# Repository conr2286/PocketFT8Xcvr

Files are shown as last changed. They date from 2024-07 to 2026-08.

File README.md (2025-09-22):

# Pocket FT8 Revisited
A derivative of Charles Hill's Palm-Sized Pocket FT8 Transceiver

# Attribution
* Copyright (C) 2025, James R Conrad (KQ7B), conr2286 *at* gmail *dot* com
* Copyright (C) 2021, Charles Hill (W5BAA), https://github.com/Rotron/Pocket-FT8 
* Si4735 Library developed by Ricardo Caritti: https://github.com/pu2clr/SI4735
* FT8 Decoding Library by Karlis Goba (YL3JG): https://github.com/kgoba/ft8_lib
* SN74ACT244 PA by Barb (WB2CBA), https://github.com/WB2CBA/DX-FT8-FT8-MULTIBAND-TABLET-TRANSCEIVER 
* Adafruit, PJRC and many Arduino libraries copyrighted by their respective authors

# Permissive MIT License (applies to most project files)
* Copyright (c) 2018 Kārlis Goba
* Copyright (C) 2019 Ricardo Lima Caratti
* Copyright (C) 2021, Charles Hill (W5BAA)
* Copyright (C) 2024, 2025 Jim Conrad (KQ7B)

Permission is hereby granted, free of charge, to any person obtaining a copy of this software and associated documentation files (the "Software"), to deal in the Software without restriction, including without limitation the rights to use, copy, modify, merge, publish, distribute, sublicense, and/or sell copies of the Software, and to permit persons to whom the Software is furnished to do so, subject to the following conditions:

The above copyright notice and this permission notice shall be included in all copies or substantial portions of the Software.

THE SOFTWARE IS PROVIDED "AS IS", WITHOUT WARRANTY OF ANY KIND, EXPRESS OR IMPLIED, INCLUDING BUT NOT LIMITED TO THE WARRANTIES OF MERCHANTABILITY, FITNESS FOR A PARTICULAR PURPOSE AND NONINFRINGEMENT. IN NO EVENT SHALL THE AUTHORS OR COPYRIGHT HOLDERS BE LIABLE FOR ANY CLAIM, DAMAGES OR OTHER LIABILITY, WHETHER IN AN ACTION OF CONTRACT, TORT OR OTHERWISE, ARISING FROM, OUT OF OR IN CONNECTION WITH THE SOFTWARE OR THE USE OR OTHER DEALINGS IN THE SOFTWARE.

# CopyLeft GPL License (applies to the SI5351 library)
* Copyright (C) 2015-2019 Jason Milldrum and Dana H. Myers

# Features
* Single band, FT8 Tranceiver
* Designed for 160-15 meters, tested on 40m
* Small Size, 4.0 X 2.8", 4-layer board
* Powered by a single 5V USB source (e.g. portable USB power block) delivering ~375 mA
* Si4735 SSB Receiver
* TCXO stabilized Si5351 Clock
* SN74ACT244 PA delivering ~250 mW on 40M (Tnx, Barb;)
* ADIF Contact Logging to SD card
* Adafruit 320 X 480 Resistive Color Touch Screen
* Optional Adafruit Ultimate GPS-derived location and UTC date/time
* RoboOp sequences FT8 QSOs somewhat akin to wsjtx

# DSP Audio Architecture
Decoding FT8 requires significant data storage and processing speed.  To optimize program storage and processing speed so the Teensy is not over taxed, the Teensy Audio Library has been modified to allow Analog to Digital conversion to be run at the rate of 6400 samples per second. This allows audio data processing to be done at 3200 Hz. The 3200 Hz audio processing with a 2048 FTT to process the received audio for FT8 decoding yields a bin spacing of 3.125 Hz.  For Teensy 4.1, the revised sample rate requires replacement of the core AudioStream.h file with the AudioStream6400.h file in the PocketFT8FW sketch folder.

The algorithms developed by Karlis Goba use the 3.125 Hz spaced FFT bins to be screened in both frequency and time so that errors in symbol frequency and time reception can be overcome to provide really great FT8 decoding. The end spacing of the FT8 algorithms is 6.25 Hz.

# Motivation and Related Projects
In the mid-60s, the ARRL Handbook published a receiver design known as the Junior Miser's Dream offering so much with so little.  Today, Charley Hill's concept for a self-contained FT8 transceiver, ideal for portable operation, again achieves so much with so little.  The entire transceiver fits in a small enclosure, powered by a USB power brick.  Pocket FT8 Revisited is a derivative of Charley's original concept.

Unlike the uSDX and related multi-mode designs, Pocket FT8 focuses entirely on FT8.  If you need CW, SSB, etc then Pocket FT8 is not for you.

Charley and Barb have progressed with another Pocket FT8 derivative, DX FT8, at https://github.com/WB2CBA/DX-FT8-FT8-MULTIBAND-TABLET-TRANSCEIVER, most notably replacing the SI4735 with a Tayloe receiver.

# Manifest
* BenchTests:  Arduino sketches for incremental tests of the hardware
* Bibliography:  "..shoulders of giants"
* Doc:  Minimalist user manual
* Enclosure:  STLs for 3D printing a plastic case for an older version (needs update)
* Examples:  Sample JSON configuration and ADIF log files
* Extras:  Modified Teensy AudioStream6400.h header (you *need* this)
* Investigations:  Code and simulations exploring technologies for this project
* Mfg:  BOM files for assembly.  V2.00 has been built; the current BOM awaits tariff issues.
* PocketFT8XcvrFW:  The transceiver firmware sources
* PocketFT8XcvrHW:  KiCad files for the PCB
* RFFilters:  Investigations into various filter designs
* Extras:  Contains Teensy AudioStream.h modified for 6400 samples/second.  You *need* this.
* Schematics:  PDFs of hardware schematics.  V2.00 matches V2.00 BOM.
* SpectralPurity:  Results of investigations into transmitter output using V2.00 hardware.

# Versions
* V1.00 PCB gerbers and pos files submitted to PCBWay.
* V1.10 Transmitter works.  Receiver occasionally decodes FT8 messages.  See Issue #23 on github.
* V2.00 Revised PCB moves the SI5351 and MCP342x to Wire1 to avoid I2C noise (Issue #23) hampering the SI4735
* V2.10 Implements GPS, ADIF logging and the RoboOp QSO sequencer.  Uses V2.00 hardware with patch wires for GPS connector.  The GPS is optional but *strongly* recommended.
* V3.00 continues with the same firmware, but the hardware eliminates the requirement for the PPS patch wire and adds an expansion connector to break-out a few GPIO signals.  The V3.00 board fabrication awaits a satisfactory tariff solution.

# Implementationi Notes
* The receiver is based upon the SI4735 chip offering a compact, low-power approach for most HF bands  Following up on a tip from the SI4735's application notes, the chip was found to be extremely sensitive to noise from other I2C traffic on the same bus as the SI4735.  The V2.00 boards address this issue by moving the touchscreen (MCP342X) and SI5351 traffic from the Wire to the Wire1 I2C bus, isolating the SI4735 on Wire.  Likewise, the V2.00 boards pay more attention to signal routing adjacent to noise-sensitive circuitry.
* Many clock designs use a TCXO driving one of the SI5351's XTAL pins and often in conflict with the SI5351 application notes recommendations.  Many designers have commented (not of one voice;) on this approach.  Following up on a now-misplaced tip re. phase noise, this design employs a low jitter TCXO driving the SI5351's CLKIN pin.  Following up on yet another misplaced tip regarding the SI5351's phase noise when driving heavy loads, the V2.00 boards buffer the XCLK signal from the SI5351.  All this may be overkill but it was easy to implement.
* The V2.00 boards and the original Pocket FT8 project use an external MCP342x ADC to poll the touchscreen.  With a non-blocking ADC library, the Teensy 4.1 could likely use the second internal ADC but this idea has not yet been tested (it can be achieved using a patch to the V2.00 boards).  Alternative approaches include using a touchscreen controller.  These are considered for a future V4.00.
* The V1.10 LP filter lacked rejection of received signals below the operating frequency.  Spectral investigations into the found surprisingly strong signals in the 500..7000 kHz range having the potential to limit the receiver's performance.  The V2.00 board filter plugins offer a chance to explore a bandpass design to protect the receiver's front end.  Suitable bandpass filters have been modeled but not yet been tested.
* The V2.00 boards support the Adafruit Ultimate GPS Breakout board.  The firmware supports using the PPS digital interrupt signal to determine when the GPS acquires a fix; however, the V2.00 PCB requires a patch wire to connect the PPS pin to Teensy Digital Pin 2, and the GPS connector has the PPS pin in an awkward location for a ribbon cable.  This will hopefull be fixed in the V3.00 hardware when tariffs permit.  The patch is easy to solder and I strongly recommend it.

# Boards and Parts Availability
Pocket FT8 Revisited is not a kit.  If you seek a kit-like experience, check-out QRP Labs, the uSDX follow-ons, or the DX FT8 kit because Pocket FT8 construction requires some engineering skills and tools including KiCAD, the Arduino IDE, and Visual Studio Code with the PlatformIO extensions.  This project is more about homebrewing than operating.  That said, sometimes I have spare boards for one version or another.

# Building the Firmware
1. Install Arduino 2.X IDE (the BenchTests still require the Arduino IDE, sorry)
2. Using Arduino 2.X, install support for the Teensy 4.1 board
3. Install Visual Studio Code and PlatformIO
4. Using PlatformIO, install support for the Teensy 4.1 platform
5. Using PlatformIO, install support for the required libraries (documented in the PocketFT8XcvrFW folder)
6. Copy Extras/AudioStream6400.h into
 .../Library/Arduino15/packages/teensy/hardware/avr/1.59.0/cores/teens4 asArduinoStream.h --- This file redefines AUDIO_SAMPLE_RATE_EXACT enabling Teensy 4.1 to operate the audio stream at 6400 samples/second (required).  You absolutely *must* do this; PocketFT8XcvrFW.cpp will not execute if you forget.
7. Build the firmware with PlatformIO.  The project src files build without warnings; library files... not so much.

# Hardware Notes
Pocket FT8 Revisited was designed with KiCAD, and the V2.00 PCBs were fabbed and the SMD assembled by PCBWay.  There are two boards, the main board (PocketFT8XcvrHW) and a daughter board for the filter (RFFilters).  I used the 5Pole40MLPFilter in the SpectralPurity test.  The V3.00 boards are designed and checked but await a satisfactory tariff solution for fabrication and assembly.

# Building the Hardware
1. Attach the Teensy 4.1 MPU to the board using *low profile* headers.
2. Attach the Adafruit resistive 320x480 touchscreen with high profile headers (so the display clears the MPU)
3. Construct a suitable filter (e.g. 5-pole Chebyshev) for your chosen band of operation and solder it into the FL1 spot.  The RFFilters folder contains a KiCAD design for the filter daughter board.
4. Hand solder SMD CR2032 battery holder to reverse side of PCB and install battery (before powering-up the Teensy).  T
5. Hand solder THT red XMIT LED
6. Wind THT T1 (10T bifilar #26 on FT37-43 core) and install
7. Install right angle header for GPS.  Hand solder a PPS patch wire from the GPS connector to the MCU as described above.
8. Hand solder the SMD SMA antenna socket to the board
9. Smoke test with wall wart USB supply (not your expensive computer;)
10. Build and execute each of the BenchTests (with Arduino IDE 2.00) in numerical order to individually check-out the circuit subsystems.

# Putting Pocket FT8 Revisited On-the-Air
1. Create an SD file, CONFIG.JSON, to configure the Pocket FT8 for your station (see the sample file in Examples).  The required parameters are, callsign and frequency.  If you don't have a GPS, you'll also need location.  Install the SD card in Teensy (*not* in the Adafruit display which also has an SD slot).
2. If you are using a GPS, connect it now.
3. Connect an antenna 
4. Connect your host computer and load your firmware

# Usage
## CONFIG.JSON
During setup(), the rig reads the config.json file, if available, from the Teensy SD card.  The SD card and configuration file are required to enable the transmitter.  See the example config file in the Examples folder.  The important configuration parameters include:
* callsign      Station callsign.  *Required* to enable the transmitter.
* frequency     Operating frequency in kHz (default is 7074).
* locator       Four letter Maidenhead grid square (Required if no GPS).
* enableAVC     Enable/disable SI4735 AVC (default is enabled).
* qsoTimeout    Seconds the QSO Sequencer will retransmit a msg without receiving a usable response from remote station (default is 180)

## GPS
If available, the rig will use the current UTC date, time and location (Maidenhead grid square) from an attached GPS.  The V2.00 hardware requires a patch wire to connect the GPS PPS connector pin to Teensy digital pin 2.  The firmware monitors PPS interrupts and begins using the UTC time and location only when/if the GPS acquires a satellite fix.  
Without a GPS fix, the firmware uses the date/time from the battery-backed Teensy Real Time Clock (RTC) and displays that date/time in yellow.  After a fix is obtained, the date/time displays in green.  The GPS is not required but *greatly* facilitates UTC logging and accurate synchronization with FT8 timeslots.

## Logging
Pocket FT8 logs successful contacts to an ADIF file on the Teensy SD disk.  The date/time are recorded in UTC if the rig has acquired a GPS fix.  If the rig has never had a GPS fix, the date/time come from the boot loader and the computer that installed the firmware --- that may work for FT8 but the UTC date/time will be incorrect in the ADIF log.  You really do want the GPS.  The logging software considers a contact successful when the rig obtains the remote station's callsign and signal report (yes, that's a little more severe than required by ARRL's LoTW).  Without a GPS, the grid locator can be obtained from the configuration file.

## Robo-Op
Pocket FT8 firmware includes a "RoboOp" "sequencer somewhat akin (or ajar...;) to those used in wsjtx and DX FT8.  The sequencer conducts a standard FT8 QSO initiated with your station's CQ, or with your reply to a station calling CQ.  The sequencer automagically coordinates its transmissions with those of the remote station to avoid "doubling" (transmitting in the same timeslot as the remote transmission).  In most cases, the sequencer prepares a reply during the FT8 "dwell" time (between timeslots) and can transmit in the very next timeslot.  If not... well... it will wait for an appriopriate even/odd timeslot.
The sequencer is implemented as a giant state machine that attempts to make the best of difficult conditions/responses to complete a troubled QSO.  The sequencer has a configurable QSO Timeout feature to abort a run-on QSO (including CQ) arising from QRM, QRN, or a QRT/QLF remote station.  As with most large state machines... the code is difficult to follow, but is mitigated with an abundance of comments that attempt to explain what's happening in the various event handlers and their actions.

## CQ Button
The CQ button directs RoboOp to begin calling CQ in the next FT8 timeslot.  RoboOp will continue calling CQ until either a response is received, a timeout occurs, the operator toggles the CQ button, or clicks the ABort button.

## TU Button
The TUne button transmits a dead carrier at the CONFIG.JSON specified operating frequency.  Toggling the TUne button or clicking ABort drops the carrier.

## AB Button
The ABort button aborts a transmission in-progress.

## TX Button
The TX button directs RoboOp to respond to the first received CQ message.  Unless CONFIG.JSON has configured otherwise, RoboOp ignores recent duplicates already in the log.  Toggling the TX button or the completion of a QSO disables the TX mode auto-responses.

## M0, M1 and M2 Buttons
These buttons transmit a free-text FT8 message specified in CONFIG.JSON.

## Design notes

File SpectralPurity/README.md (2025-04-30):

# Manifest
## PocketFT8V210.bmp
Output spectrum under modulation ("CQ KQ7B DN15") with rig operating at 7074 kHz.  The 2nd harmonic is lost in the noise, the 3rd is ~50dB down, subsequent harmonics are lost in the noise.  The analyzer was scanning from DC-50 mHz, 5 mHz/division, with a bandwidth of 100 kHz.

## NarrowView.bmp
Narrow view of the output spectrum during modulation ("CQ KQ7B DN15") with rig operating at 7074 kHz + 888Hz for the FT8 offset .  The analyzer is scanning from 7074 to 7076 kHz, centered at 7075 kHz with a 30 Hz bandwidth.  At -30 dB down, emission products extend from ~7074.650 to 7075.050 Hz.

## TuningCarrier.bmp
Narrow view of the output specturm from the steady tuning carrier at 7074 kHz.  The analyzer is scanning from 7074 to 7076 kHz with a 30 Hz bandwidth.  We are likely viewing the combined phase noise performance of the transmitter and the Rigol DSA 815.  At ~200 Hz above the carrier, the noise is ~45 dB down.  This is probably the optimal measurement of the rig with the DSA 815, a baseline for comparison to the narrow view during modulation.

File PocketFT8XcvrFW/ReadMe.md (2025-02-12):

#BUILD
PocketFT8XcvrFW builds using Visual Studio Code and PlatformIO

##MANIFEST
~/include	*.h files common to project src and libraries
~/src		*.cpp and *.h files comprising the project sources
~/lib		*.cpp and *.h files comprising the custom libraries used by project src

##DEPENDENCIES
* Teensy41		        PlatformIO installs this platform
* Adafruit GPS Library	Installed by PlatformIO
* ArduinoJson		    Installed by PlatformIO
* PU2CLR SI4735		    Installed by PlatformIO

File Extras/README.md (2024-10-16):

* AudioStream6400.h:  This file must be copied as "AudioStream.h" into the Teensy 4.1 audio library, .../Arduino15/packages/teensy/hardware/avr/1.59.0/cores/teensy4 on my macos machine, to enable the firmware to run the audio stream at 6400 samples/second.

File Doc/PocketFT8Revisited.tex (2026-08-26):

\documentclass[10pt, letterpaper,]{article}

% Include supporting packages
\usepackage[top=1in, bottom=1in]{geometry}
\usepackage{setspace}
\usepackage{amsmath}
\usepackage{enumitem}
\usepackage{setspace}
\usepackage{url}
\usepackage{graphicx}
\usepackage[hidelinks]{hyperref}
\usepackage{wrapfig}
\usepackage{enumitem}

\title{Pocket FT8 Revisited}
\author{Jim Conrad, KQ7B}
\date{\today}

\begin{document}
	\maketitle
%\small

%\vspace*{.5in} % Pushes the title  down page 1
%\begin{center}
%    {\LARGE \bfseries Pocket FT8 Revisited} \par
%    \vspace{0.25in}
%    {\large Jim Conrad, KQ7B} \par
%    {132 Mill Creek MDW, Grangeville, ID 83530 USA}
%\end{center}

\begin{abstract}
 The original Pocket FT8  was a small, self-contained, portable, software defined, QRPP, FT8 transceiver. 
 This article revisits the original Pocket FT8 concept with hardware and firmware enhancements to create a compact digital rig  suitable for outdoor adventuring.
\end{abstract}

\section*{Introduction and Features}
Charles Hill's original Pocket FT8 project\cite{pocketFT8} inspired several fully self-contained FT8 transceiver derivatives\cite{dxFT8}\cite{tinyDX} in which an embedded computer \textit{is} the rig.
This derivative offers simplified hardware and enhanced firmware while retaining the compact-size, single-band, QRPP, HF transceiver concept.
Features include:
  \begin{itemize} [noitemsep]
  \item Open source hardware and firmware
  \item 600 mHz Teensy 4.1 Micro Controller Unit (MCU)
  \item Self-contained and light-weight
  \item Compact, 4-layer PCB (4.0X2.8")
  \item Direct FSK, FT8 modulator/demodulator
  \item QRPP 275+ mW RF output
  \item RF filter slot
  \item Low jitter TCXO
  \item GPS disciplined date, time and location (grid square)
  \item 480x320 pixel TFT calibrated touchscreen
  \item Waterfall traffic display
  \item Standard FT8 QSO sequencer
  \item Micro-SD card accessible via USB
  \item Automatic QSO logging to an ADIF file on SD
  \item JSON station configuration file on SD
  \item Operation from a  5V, USB power bank
  \end{itemize}
The FT8 protocol\cite{qexFT8}, designed for weak signal communication, excels in portable, battery-operated, QRPP operation.
Pocket FT8 integrates the traditional digital station's computer, transceiver, rig controller, and digital/audio interface in a single, self-contained package.
Use of FT8 reduces the transceiver's power requirements and weight while also  eliminating the telegraph key, microphone, and headset accessories accompanying SSB/CW transceivers.
Consolidating the  radio with the FT8 encoder/decoder in an embedded computer eliminates the need to carry a computer into the field.
Further integration of a GPS receiver offers UTC date and time for ADIF logging as well as the Maidenhead grid square and synchonization with FT8 time-slots.

FT8 QSOs are  terse, contest-like exchanges conveying sequenced,  structured messages with minimal operator intervention following contact establishment.
Because an FT8 message requires an extremely quick response, WSJT-X\cite{qexFT8} and related FT8 applications automate the message exchange between stations as human response times are woefully inadequate.
Pocket FT8 Revisited includes a QSO sequencer, affectionately known as RoboOp, implementing WSJT-X style message sequencing for Tx1 through Tx6.
Akin to WSJT-X, RoboOp retransmits the previous message if it doesn't receive a valid response from the remote station.
A configurable QSO timer guards against endless retransmissions.

The Teensy micro SD card slot holds both the operator-supplied configuration file, CONFIG.JSON, and the ADIF log file produced during station operation.
The executing firmware supports the Media Transfer Protocol\cite{mtp} (MTP) enabling an optional host computer to access the Teensy SD card via USB without removing the media.
MTP is  the preferred way to read the log file when the SD card is not accessible through the transceiver's enclosure.

\section*{Transceiver Construction}
TBD

\section*{Low Pass Filter}
FL1 in the Figure \ref{fig:schematic} removes harmonics from the digital PA.
A suitable five-pole Chebyshev design for the 40m band is in the \texttt{RFFilters/5Pole40MLPFilter} folder.
This filter was designed with Marki's on-line tool to allow 1 dB of ripple  peaking near the 40M FT8 7074 kHz calling frequency, and its performance was simulated with LTSpice.
A Bode plot instrumentation of KQ7B's real-world implementation of 40M FL1 design appears in Figure \ref{fig:lpFilter}.
A spectrum analyzer plot of the transceiver's ouput through the 40M FL1 implementation appears in Figure \ref{fig:spectralPurity}.
The third hamonic is the most prominent and is suppressed by about 50 dB.

\section*{Building the Firmware}
The firmware was developed on MacOS but should build on Windows or linux.  
In all cases, use Visual Studio Code and PlatformIO to build and install the firmware.
Install the required development tools for your computer's operating system and project source code:

\begin{itemize} [noitemsep]
\item Visual Studio Code
\item C/C++ 23 compiler/linker
\item \texttt{PocketFT8XcvrFW} source code 
\end{itemize}

You will need some Visual Studio Code extensions for C/C++ embedded systems development.
From within Visual Studio Code, install:
\begin{itemize} [noitemsep]
\item PlatformiO IDE
\item C/C++ DevTools
\item C/C++ Extension Pack
\item C/C++Themes
\item CMake Tools
\end{itemize}

You will likely need to modify the \texttt{PocketFT8XcvrFW/platform.io} project configuration for your development environment.
In particular, you may wish to edit (or comment-out) the parameters describing which of your computer's USB ports connects to Teensy.
You may also need to edit the \texttt{lib\_extra\_dirs} pathnames.

You can test your development environment by having PlatformIO build \texttt{test\_01}, an implementation of blinky, with  the pio command, \texttt{pio test -f hw/test\_01}.

\section*{Installing and Debugging the Firmware}
Connect your development computer to Teensy's USB port.
With all \texttt{platformio.ini} references to ports commented-out, click on PlatformIO's ``Upload" icon.
If all goes well, PlatformIO will automatically locate the correct USB port and install the firmware.
Upon occasion, PlatformIO may not dependably locate the correct port and you may need to manually configuring that port in \texttt{platformio.ini}.

Teensy 4.1 does not include a debugging port such as JTAG.
Consequently, all debugging to date has been achieved using debugging messages written to Teensy's USB serial port.
The \texttt{DEBUG.h} and \texttt{NODEBUG.h} header files define C macros (e.g. DPRINTF) facilitating use of debugging messages.
Including \texttt{DEBUG.h} in a source file enables that file's debugging messages, while including \texttt{NODEBUG.h} disables them.

\section*{Transceiver Configuration}
Use a computer to create a station configuration file, \texttt{CONFIG.JSON}, on a micro-SD card and install the card in the Teensy slot as the radio can not boot-up without it.
After the radio is operational, all the files on the SD card are accessible via USB through MTP.
Sample JSON configuration files appear in Figure \ref{fig:config} and in the github project's Examples folder.

Only two config parameter entries, the station's callsign and operating frequency, are essential; all remaining parameters illustrated in Figure \ref{fig:config} may be omitted.
The callsign must conform to the WSJT-X requirements.
The operating frequency must be provided in integral kHz (no decimal fraction) and that frequency must be compatible with the low-pass filter installed in the filter slot, FL1.

The operator's personal name is optional and is included in log file entries when provided.

The optional M0, M1 and M2 entries program three possible ``canned" 13-character FT8 ``free text" messages.

When GPS is not reliable, the station's 4-character maidenhead grid square locator may be configured manually.

The Si4735 automatic volume control feature may be optionally configured off (\texttt{false}). 
The default is on (\texttt{true}).

To prevent endless retransmissions, RoboOp maintains a timer and abandons a QSO after the \texttt{qsoTimeout} period (in seconds) expires.

By default, RoboOp tracks recently worked stations and avoids contacting duplicates; the \texttt{enableDuplicates} parameter override this prohibition if set to \texttt{true}.

Successful QSOs, those exchanging callsigns and signal reports, are logged to an ADIF file whose name may be optionally configured to override the default, \texttt{LOGFILE.ADIF}.
This is useful, for example, if you'd like to maintain different log files for different dates or QTHs.
In all cases, the log file is written to the Teensy micro SD card.

If your station is located at a SOTA site, you may wish in configure a SOTA Reference Number to be included in the log entries.

\section*{Connections}
The only truly required connections to the radio are power, antenna and the micro SD card containing the CONFIG.JSON file.
Five volt power must be supplied through the Teensy 4.1's USB Micro-B port.
Commonly available USB power banks are satisfactory.
The HF antenna must be connected to the transceiver's SMA port.
The micro SD card must be inserted in the Teensy slot, not the unsupported Adafruit display slot.

The use of a connected GPS significantly improves the transceiver's usability and is strongly recommended.
The GPS connection is made with a 5-pin ribbon cable to J3 for received data (\texttt{GPSRX}), transmitted data (\texttt{GPSTX}), Pulse Per Second (\texttt{PPS}), power (\texttt{+5V}) and ground (\texttt{GND}) as illustrated in Figure \ref{fig:schematic}.
A GPS fix automatically configures the station's maidenhead grid square locator as well as the UTC date and time.
Lacking the GPS, the radio uses the manually configured locator and restores the current date and time from Teensy's battery-backed clock.
Without the GPS, the station's timezone is unknown and QSOs may not be logged using UTC time as required by ADIF.
Without the GPS, the transceiver's knowledge of the FT8 15-second time slot boundaries drifts with the battery-backed clock.
Because FT8 requires transmissions to begin at accurately known time slots, communication is frustrated or impossible with timing errors.
When a GPS fix has never been achieved, Teensy's battery-back clock is using date and time values obtained by the boot loader; these are unlikely to be particularly accurate nor UTC.
Use the GPS whenever possible.

There is no microphone, key or headphone connection.
The computer \emph{is} the radio, and only digital modulation is supported.

\section*{User Interface}
The transceiver's user interface consists of a waterfall display of activity within the receiver's passband, a station status display, a display of decoded messages, a transcript of the current QSO's traffic (if any), and a set of menu buttons.
Brighter colors in the waterfall indicate stronger signals.
The status display indicates the station's callsign, maidenhead grid square locator, date, time, etc.
Values deemed certain appear in green text, while unvalidated content appear in yellow.

FT8's AFSK legacy specifies the operating frequency as the carrier frequency (in kHz) and an audio offset (in Hz); the actual unmodulated operating frequency is their sum.
The transceiver's carrier frequency must be configured in CONFIG.SYS.
The default offset is 1000 Hz and is changed by touching the waterfall display.

The transceiver boots up when 5V power is applied to the Teensy's USB port.
The status display indicates the station's callsign and operating frequency as obtained from CONFIG.JSON.
Until a GPS fix is obtained, the status display presents the battery-backed date, time and the grid square in yellow.
Following a GPS fix, the UTC date and time, and the maidenhead grid square, appear in green text.
During initialization, the transceiver reads the content of the log file, if any, and notes the callsigns of upto 1000 previously worked stations.
By default, RoboOp will not rework those stations.

Following initialization, the transceiver begins displaying decoded FT8 messages from other stations.
Received CQ messages are highlighted to gain your attention.
The limited display size requires the signal strength of the decoded messages to appear as simple S values (e.g. S1, S2, ... S9) rather than dB as in WSJT-X.
When the band is quiet, you may be able to contact almost any heard station; in a noisy band, only the stronger stations may be able to decode your QRPP transmissions.
Touch a decoded station's message (e.g. CQ) to initiate a QSO with that station.
Alternatively, you may use the CQ menu button to begin transmitting your own CQ messages.
RoboOp (the firmware sequencing a WSJT-X-style QSO) will begin transmitting at the next appropriate FT8 time slots, avoiding those time slotss when a called station will likely transmit.
If you do not receive an appropriate response, RoboOp  repeats your transmission until the configured timeout period expires, or you touch the ABort button.
In all cases, RoboOp attempts to avoid transmitting in the same time slots as a specified remote is expected to transmit.
In crowded band conditions, you may wish to change the offset frequency (by touching the waterfall) to select a quiet location.

 \section*{Hardware Overview}
The Pocket FT8  transceiver (Figure \ref{fig:schematic}) is designed around a Teensy 4.1, 600 mHz, 32-bit ARM Cortex-M7 MCU with hardware floating point, USB, SPI, I2C, 1 mB of RAM, and two ADCs.

When transmitting, the MCU reprograms the Si5351 clock generator's output for each of the eight FT8 Frequency Shift Keying (FSK) tones, a direct FSK scheme, unlike the Audio FSK (AFSK) widely used with a SSB transmitters' microphone jack.
Frequency stability is achieved by locking the Si5351 to a low jitter Temperature Controlled Crystal Oscillator (TCXO) reference.
The Si5351's output is buffered by one element of a SN74ACT244 octal bus driver whose remaining seven buffers function in parallel as the transmitter's QRPP power amplifier (PA).
A five-pole Chebyshev low-pass filter  with 1 dB of ripple (Figure \ref{fig:lpFilter}) peaking near the expected operating frequency  provides harmonic rejection.
The PA delivers 275 mW through the filter.

An Si4735 digital receiver implements the receiver's RF section and delivers FT8 audio tones to the Teensy audio pipeline via ADC2.
While the Si4735  lacks the performance of alternative designs, its capabilities are on par with the QRPP transmitter:  on-the-air experience found the receiver decodes more signals than the 275 mW transmitter can work, especially in crowded band conditions.
The development of an early prototype found the Si4735 performance degrades in the presence of noise from other I2C bus device traffic; the problem was resolved by isolating the Si4735 on a private I2C bus.
The Si4735's phase-locked loop (PLL) locks to the Si5351 clock generator's CLK2 output.

An Adafruit 3.5" TFT 320x480 touchscreen with an HX8357D controller serves as the graphical user interface device.
The display achieves satisfactory performance over an SPI bus from the MCU while the resistive touchscreen connects to the MCU's ADC1.
The compact display is ideal for portable operation,  but touchscreen accuracy improves with use of a stylus rather than your finger.

 \subsection*{FL1 Design}
FL1 mainly provides harmonic rejection for the transmitted signal.
On 40 meters, the five pole Chebyshev design provides for 1 dB of ripple peaking inside the band.

During receive, the Chebyshev low-pass design offers only minimal rejection of out-of-band signals. 
While this has not proven to be a significant issue in the wilderness use-case, the receiver might benefit from a bandpass design in other applications.
 \subsection*{Hardware Construction}

\subsection*{T1}
T1 is a broadband, bifilar wound transformer consisting of 10 turns of 26 AWG on an FT37-43 core.

\subsection*{FL1}
The FL1 low-pass filter can be assembled and tested on a small daughter board.
With some effort, it can probably be made pluggable to facilitate band changes.

\section*{Software}
\subsection*{Software Design}

\subsection*{Software Construction}

\section*{Testing}

\section*{Future}

\section*{Acknowledgements}
Pocket FT8 Revisited is a derivative of Charles Hill's original Pocket FT8 project\cite{pocketFT8} with important contributions from Ricardo Caritti's Si4735 library, Karlis Goba (YL3JG)'s FT4/FT8 encoder/decoder, Barb (WB2CBA)'s SN74ACT244 PA, and, of course, Franke, Somerville and Taylor's work on WSJT-X\cite{qexFT8}.
Someone, somewhere, possibly in a FaceBook post, noted that the Si4735 desensitizes in the presence of I2C bus traffic with other devices; I found this to be absolutely true and their post saved the day.
Perhaps everyone doing this kind of work has been inspired by Hans Summers (G0UPL)'s experiments and designs at QRP Labs.  
If your operating interests don't include hours of analysis and debugging at a lab bench, you may find what you're looking for at, \url{https://qrp-labs.com}.

\section*{Authors}
\begin{description}
	\item[Jim Conrad] is a retired engineer from the computer industry and academia.  His career contributed to pioneering implementations of personal computer networking, embedded device networking, and color electrophotography before teaching computing to aspiring engineers.  He now lives on a small farm in northern Idaho.  ``Never let the people who didn't try tell you what you can or cannot do."

\end{description}

% Schematic
\begin{figure}[b]
\centering

\caption{Schematic}
\label{fig:schematic}
\end{figure}

% Chebyshev Low-Pass Filter Bode Plot
\begin{figure}[b]
\centering
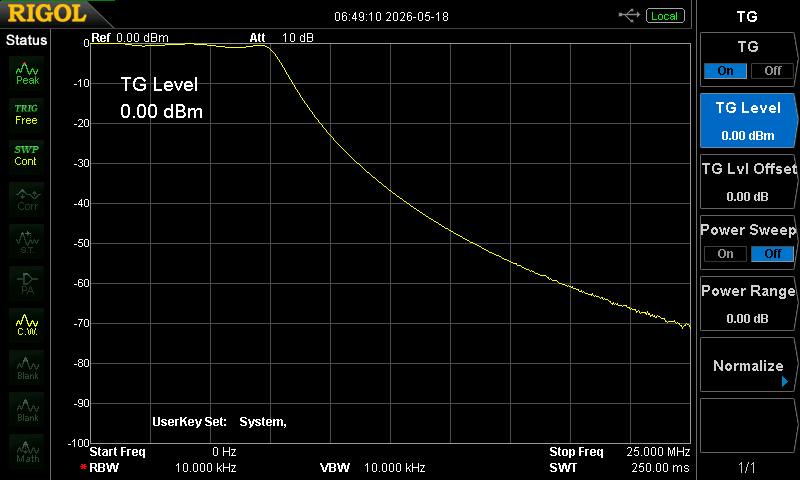
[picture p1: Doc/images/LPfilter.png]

\caption{Chebyshev Low-Pass Filter Bode Plot}
\label{fig:lpFilter}
\end{figure}

% Spectral purity
\begin{figure}[b]
\centering
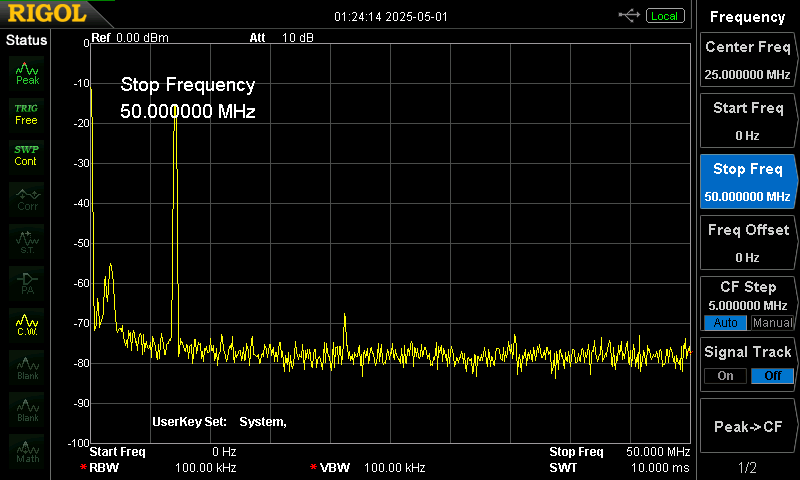
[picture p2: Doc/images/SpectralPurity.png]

\caption{Spectral Purity}
\label{fig:spectralPurity}
\end{figure}

% CONFIG.JSON
\begin{figure}[htbp]
\centering
\begin{verbatim}
//-CONFIG.JSON-------------------------------------------------------------
{
   "callsign": "W1AW",              //REQUIRED:  Station callsign
   "frequency": 7074,               //REQUIRED:  Operating frequency in kHz
   "myName" : "Jim",                //OPTIONAL:  Operator's personal name
   "M0" : "CQ KQ7B/IDAHO",          //OPTIONAL:  13-Char Free Text Msg0
   "M1" : "IDAHO",                  //OPTIONAL:  13-Char Free Text Msg1
   "M2" : "QRT"                     //OPTIONAL:  13-Char Free Text Msg2
   "tcxoCorrection": -5,            //OPTIONAL:  TCXO freq correction in Hz
   "locator": "",                   //OPTIONAL:  4-char maidenhead grid
   "enableAVC": true,               //OPTIONAL:  0=disabled, 1=enabled
   "qsoTimeout": 180,               //OPTIONAL:  Seconds RoboOp will retry
   "enableDuplicates": false,       //OPTIONAL:  Enable duplicate contacts
   "logFilename" : "LOG0815.ADIF",  //OPTIONAL:  ADIF logfile name
   "my_sota_ref" : "W7I/IC-257",    //OPTIONAL:  SOTA Reference Number 
}
\end{verbatim}
\caption{CONFIG.JSON}
\label{fig:config}
\end{figure}

%\newpage
\bibliographystyle{IEEEtran}
%\bibliographystyle{plain}
%\bibliographystyle{ieeetr}
\bibliography{PocketFT8Revisited}

\end{document}

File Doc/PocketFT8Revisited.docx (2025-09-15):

# The Pocket FT8 Transceiver Revisited

Jim Conrad, KQ7B, 09/15/25

[^1]

Abstract—Pocket FT8 Transceiver Revisited is a derivative of Charles Hill’s (W5BAA) Pocket FT8 project [5]. This document describes how to assemble and operate the little rig plus a few hints for modifying it.

Index Terms—Amateur Radio, Digital Signal Processing, DSP, FT8, Homebrew, SDR, Software Defined Radio, Teensy, Si4735, Si5351, Transceiver, WSJTX.

# I. INTRODUCTION & ASSEMBLY

The Pocket FT8 Revisited is a self-contained, single-band, FT8 amateur radio transceiver. Features include:

- 4.0 X 2.8", 4-layer board
- Filter slot for a single band
- FT8 (only) modulation
- 275 mW RF output (QRPP)
- 480x320 TFT touchscreen display
- 600 mHz Teensy 4.1 MCU
- Auto-logging to an SD ADIF file
- JSON configuration file
- “RoboOp” sequenced FT8 QSO
- TCXO clock
- GPS disciplined date, time and grid square
- Operation from a single 5V power brick

To assemble the radio, you need:

- A V2.00 or V3.00 PCB assembly
- A Teensy 4.1
- Adafruit Ultimate GPS PA1616S
- Adafruit 480x320 TFT resistive touchscreen 2050
- Low-profile headers for Teensy
- Tall headers for display
- Right-angle headers for GPS
- SMT BU2032SM holder & CR2032 battery
- SMT SMA antenna jack
- A 5-Pole Low-Pass Filter
- Hand soldered THT red XMIT LED
- T1 bifilar wound xfmr: 10T #26 on FT37-43
- An SD card with CONFIG.JSON file

Note: The GPS header pinout on V2.00 boards is not an exact match for the Adafruit Ultimate GPS; you need to hand-build the GPS cable. V2.00 boards require a patch wire from GPS PPS pin to the GPIO2 (Teensy Header #4) pin.

KQ7B’s spectral tests were conducted with the 5-Pole Chebyshev Low Pass filter in .../RFFilters/5Pole40MLPFilter. This 40 meter filter’s initial design was created using https://markimicrowave.com/technical-resources/tools/lc-filter-design-tool/ and then hand-tuned with LTspice to place the peak near the 7074 FT8 calling frequency, while optimizing the design for T37-17 inductor cores and standard capacitor values.

The Pocket FT8 Revisited is a homebrew project [6], not a commercial kit. If you’re looking for a Heathkit-like experience, consider one of the products from Han’s QRP Labs, or the DX FT8. On the other hand, this rig’s hardware and the firmware are fully open source and ripe for experimentation. You can use or improve the KiCad schematics and board design, or the PlatformIO firmware and the tests with few restrictions.

# II. User Interface Overview

The user interface (UI) displays five panels and a row of menu buttons. The upper-left panel provides a waterfall display of received signal strengths, and is also used to change the FT8 offset frequency. The upper-right panel reports the station’s status including the current date and time, four character Maidenhead grid square locator, callsign, carrier frequency, and the rig’s current activity (e.g. RECEIVE, TUNE, TRANSMIT…). The middle-left panel reports the first 6 messages decoded during the previous FT8 interval. The middle-right panel displays messages directed to or from this station. The bottom panel displays error messages and information about the little rig’s activities.

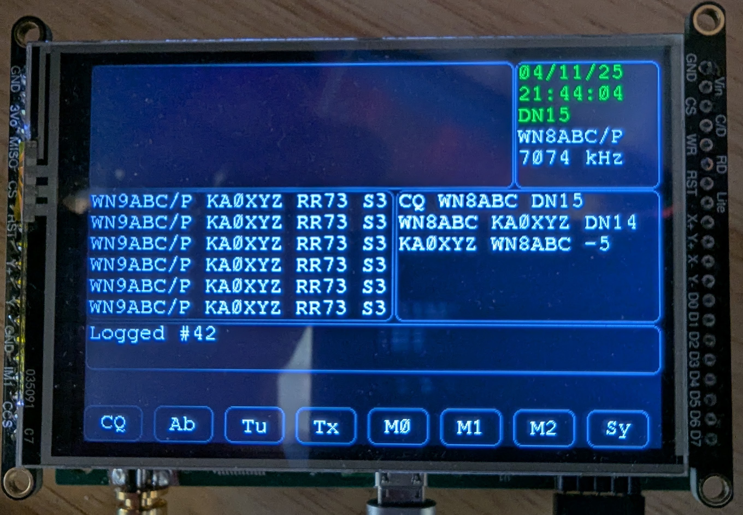
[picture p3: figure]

Fig. 1. Pocket FT8 Revisited’s User Interface

The menu buttons appear in the bottom row and these control the functions of the FT8 rig.

## A. Waterfall Panel

The waterfall provides an interactive display of FT8 activity. Brighter pixels indicate stronger signals while darker pixels reflect weaker signals. The vertical red line indicates your chosen transmitter offset frequency (from the carrier), and may be adjusted by touching the panel. You may wish to choose an offset in a quiet region of the band so your QRPP signals will not be buried beneath those of QRO stations.

## B. Station Status Panel

When a GPS fix is available, the GPS-disciplined date and time are displayed in UTC with green text. Without a GPS fix, the date and time values are retrieved from the battery-backed Real Time Clock (RTC) and displayed with yellow text.

Likewise, when a GPS fix is available, the four-character Maidenhead grid square locator is displayed with green text. When a GPS fix is not available, the rig uses the locator provided by the SD configuration file, else the transmitter is disabled if the grid square is not available from any source.

Note that the GPS, while highly desirable, is optional. The rig will “make the best of it” when a GPS fix cannot be obtained. In particular, if a GPS fix was previously obtained after the firmware was loaded into the MCU, the battery-backed RTC will likely be reasonably accurate. Keep in mind that Teensy resets the RTC clock to your computer’s local time when you load new firmware into the MCU. To ensure UTC logging and optimal FT8 performance, the rig needs a GPS fix following firmware installation.

The station’s callsign appears in the status panel, as does the nominal operating frequency (kHz) and the transmitter’s FT8 offset (Hz).

The bottom line of the status panel displays the rig’s current mode, RECV, PEND (transmission), XMIT or TUNE.

## C. The Decoded Messages Panel

The receiver displays its decoded messages in the middle-left panel. Due to constrained screen space and the conflicting desire to report as much detail as possible about each signal, the display differs from the familiar WSJTX. The Received Signal Level (RSL) appears as S1-S9 rather than the FT8 decibel convention in order to fit the signal report into two characters rather than three. The MCU firmware refreshes the list of received messages following each FT8 time slot. What you see is always the most recent.

Clicking on a received message, e.g. a CQ, instructs RoboOp to engage the remote station in a QSO by transmitting a call in the next available FT8 time slot (this is explained in more detail in the FT8 Essentials section below).

## D. The Station Messages Panel

Signals received by and transmitted from the local station appear in the Station Messages panel on the righthand side of the screen. These messages scroll so the oldest message always appears at the top. Most messages appear in white text, but repeated messages appear in yellow rather than in multiple lines. Repeated, unsuccessful attempts to contact a station eventually timeout, and the final attempt appears in grey. Old messages eventually scroll off the panel.

## E. The Application Messages Panel

The Application Messages panel displays error and informative messages about the rig’s activities. Most are self-explanatory, but a few deserve further attention:

- FATAL: You *must* copy AudioStream6400.h to .../teensy/hardware/avr/1.59.0/cores/teensy4/AudioStream.h: This occurs when firmware has been rebuilt with the wrong version of Teensy’s AudioStream.h header file. You’ll find the correct version in the Extras folder named, AudioStream6400.h, and this must be renamed and copied into the ...cores/teensy4 folder before the rebuilding the firmware.
- ERROR: Unable to access SD card: The SD storage disk containing your CONFIG.JSON file (and space for the ADIF log) is not accessible in the Teensy SD slot. Insert your SD card in the Teensy slot, not the Adafruit display board’s socket. The rig will continue to boot up but many features are inoperable without your station’s callsign.

## E. The Menu Buttons

- CQ: Pressing the CQ button instructs the rig to begin calling CQ in the next available FT8 timeslot. If a response is received, RoboOp attempts to engage the responder in a standard, sequenced FT8 QSO, and resumes listening when the QSO completes. If nothing is heard, the rig repeats the CQ message until RoboOp times-out. Pressing the CQ button while the rig is already transmitting CQs terminates CQ activity.
- AB: Abort any transmission in progress.
- TU: Output a steady carrier for antenna tuning. Pressing the TU button during a tuning activity cancels the tuning activity.
- TX: Instructs RoboOp to respond to the first station it hears calling CQ. If successful, RoboOp engages in a standard, sequenced FT8 QSO and then returns to listening. RoboOp repeatedly attempts to contact the heard station until a time-out occurs. You can abort RoboOp’s pursuit of a contact by pressing TX again, or by pressing the AB (abort) button. By default, RoboOp will not engage a station that’s already in the log; this can be changed in the configuration file.
- M0: Not implemented.
- M1: Not implemented.
- M2: Not implemented.
- Sy: Not implemented.

III. FT8 Essentials

FT8 [1] is a digital communication mode whose excellent weak signal performance imparts some compromises.

All transmissions are of a fixed length and require ~12.6 seconds to complete. Every transmission occurs in one of four time slots that arise at 0, 15, 30 or 45 seconds past the minute. There is, at most, a 2.4 second “dwell” time between the end of a received transmission and the beginning of the following time slot, and that only if the transmission begins exactly on time and can be decoded concurrently as the bits arrive. Timing is important.

Consider the case of a remote station transmitting CQ messages during even-numbered time slots and listening for responses during odd-numbered time slots. At most, our receiving station has 2.4 seconds to decide to transmit a response during the following odd-numbered time slot while the remote is listening. That’s not much time. What’s worse is, if our station is too slow to respond in the first available odd-numbered slot, we will have to wait for the beginning of a future odd-numbered time slot to avoid “doubling” with the remote station. If the remote station is rare DX, well… we likely missed our opportunity. Hence… RoboOp.

IV. RoboOp

Because the 2.4 second response time challenges human operators, FT8 software generally implements automation to sequence a standard, contest-like, QSO without human intervention. Pocket FT8 Revisited automates FT8 QSOs with its “RoboOp” feature.

Clicking on a remote station’s CQ message directs RoboOp to engage that station. RoboOp replies to their CQ and sequences a QSO with the standardized FT8 messages at the appropriate times. RoboOp retransmits its message when it doesn’t hear an appropriate reply.

The TX menu button directs RoboOp to contact the first remote station it hears sending CQ messages. If successful, RoboOp will sequence the entire QSO thereafter.

The CQ menu button directs RoboOp to transmit CQ messages and engage the first responder it hears in a QSO. RoboOp completes, at most, a single QSO; it will never run continuously, logging QSO after QSO, while you enjoy a sandwich and cold beverage from the cooler.

RoboOp employs a configurable time-out determining how long it persists retransmitting a message without receiving a satisfactory response from the remote station.

By default, RoboOp will not respond to CQ messages from a known station already in the log. However, see CONFIG.JSON for the override as this is exactly what you may wish to do when testing your latest enhancement to the hardware or firmware.

V. Logging

Pocket FT8 Revisited records an ADIF log file on the Teensy MCU’s SD card. By default, the file is called, LOGFILE.ADIF but the actual name is configurable. You currently must remove the SD card to copy the log file to your computer.

VI. Configuration

You must supply a configuration file, CONFIG.JSON, on the SD card installed in the Teensy MCU. The Examples folder contains a sample CONFIG.JSON which you can modify for your own station. The callsign and frequency fields are required, the others are optional. If you plan to operate without a permanent GPS connection, you will need to configure the locator field with your Maidenhead grid square.

VII. Building the Rig

Pocket FT8 Revisited is a github project at, https://github.com/conr2286/PocketFT8Xcvr. The firmware is located in the PocketFT8XcvrFW folder, and the hardware in PocketFT8XcvrHW.

## A. Firmware

The firmware design requires a change to the Teensy 4.1 AudioStream.h file, and a copy of the modified file you need resides in the Extras folder named AudioStream6400.h. You will have to locate Teensy 4.1’s AudioStream.h file and replace it with the renamed AudioStream6400.h file. No, you can’t fudge this. If you try, the firmware will tell on you (you might ask how I know that;).

In pursuit of improved testing, much of the V2.* firmware has been moved from the Arduino 2.0 IDE to PlatformIO, a more capable IDE for projects of this size. The platformio.ini file is located in the PocketFT8XcvrFW folder. The easiest way to get started is to install the Arduino 2.0 IDE first (PlatformIO will use the tools and libraries it installs), Arduino’s support for the Teensy 4.1 board, the Adafruit GPS Library V1.7.5, the PU2CLR SI4735 V2.1.8 library, the bblanchon ArduinoJson V7.3.0 library, and the Adafruit GFX V1.12.0 library. Some of the libraries build with compiler warnings; the PocketFT8XcvrFW code builds clean as of April 23, 2025.

As of V3.00, the choice of amateur band (e.g. 40M) is hardwired in the PocketFT8XcvrFW.cpp source code. If operation is planned on other than 40 meters, you will need to modify the definitions for MINIMUM_FREQUENCY and MAXIMUM_FREQUENCY for the band of your choice.

To open the project with PlatformIO, first install Visual Studio Code (VSC), then the VSC extension for C/C++ programming, and then the PlatformIO extension. Click on the PlatformIO “alien” icon, then “Pick a folder” then the “PocketFT8XcvrFW” folder. PlatformIO will likely busy itself installing the necessary board, framework and libraries either before or when you click the build (checkmark) icon. The project files should build clean (no warnings); the library files not so much.

It might be possible to build the firmware using the Arduino IDE 2.00. Install the required Teensy 4.1 board and library dependencies (these are listed in PlatformIO.ini). Rename PocketFT8XcvrFW.cpp to become PocketFT8XcvrFW.ino, then move all the src, lib and include folders’ files into the PocketFT8XcvrFW folder to satisfy the Arduino’s expectations. Don’t forget to replace Teensy’s AudioStream.h file as described above. Let me know if it works.

Compatibility: The V3.00 firmware runs on either the V2.00 hardware (with the GPS PPS patch wire) or on the V3.00 hardware (without any patch wires).

## B. Test Programs

There are a number of folders within the BenchTests folder containing small (mostly Arduino 2.0 IDE) test projects for the hardware. The folders are numbered in a suggested order, and the code they contain was developed for testing new boards. You may find them useful for testing new boards, but they are not required.

Additional tests reside in the PlatformIO test folder. As of the V2.* builds, these mainly address the user interface.

## C. Investigations

The Investigations folder contains folders and files used to prove (and disprove!) some of the concepts developed for the firmware and hardware.

## D. Filters

The RFFilters folder contains a variety of LTSpice filter designs, simulations and daughter board designs. The transmitter requires a 5th order Chebyshev low-pass filter to meet the USA FCC spectral purity requirements. The receiver might benefit from a bandpass filter, especially when operated near an AM broadcast antenna, but this has not been evaluated as of April, 2025.

## E. Hardware

The PocketFT8XcvrHW folder contains the KiCAD 9 files for the schematic and PCB artwork. The Bill of Materials (BOM) is in the Mfg folder. PCBWay built and assembled most SMT components on my boards. The only SMT components not in the BOM (like… the antenna jack, the RTC’s battery holder…) are really easy to solder. I installed low-profile headers on the Teensy 4.1 and THT soldered these to the PCB.

## F. GPS

J3 on the V2.00 boards break-out a 5-pin connection for the GPS. The PCB layout for J3 was designed for an obsolete GPS and the pinout doesn’t exactly align with the Adafruit Ultimate GPS PA1616S; that means you will need to construct the GPS cable by hand rather than use a flat ribbon. The firmware needs the Pulse Per Second (PPS) signal to determine when the GPS has acquired a fix. The V2.00 boards require a patch wire connecting PPS to Teensy GPIO2.

The firmware will run without a GPS, but a working GPS supplies the maidenhead grid square, UTC date, and UTC time for the ADIF log, as well as synchronizing the transceiver with the FT8 time slot boundaries. If you don’t have a GPS, the Teensy loader sets the MCU’s date/time to that of your development computer. This is sometimes accurate enough to conduct an FT8 QSO but is far from optimal for either FT8 or logging. I strongly recommend using a GPS in the field.

## G. Auxiliary Analog/Digital Expansion

J4 on the V3.00 boards break-out additional Teensy analog and digital connections for a planned expansion of the firmware.

## H. Enclosure

The FreeCAD and STL files reside in the Enclosure folder. There is one file to build the main enclosure, and a second for the display bezel. As of July, 2025, the enclosure requires substantial post-processing to make it usable.

VII. Limitations

Several menu buttons are defined but unimplemented in Version 2.* firmware.

The FT8 library does not currently support hashed callsigns. Received traffic with hashed callsigns is not displayed. RoboOp will not respond to hashed callsigns.

I have long expected disappointment with the Si4735 receiver chip but its real-world performance seems up to the task of communicating with “ordinary” stations receiving the little rig’s 275 mW QRPP signal. This level of performance was only achieved through careful board revision to eliminate Si4735 interference from digital noise. Long-term, the receiver may migrate to a Tayloe detector to facilitate QRPP-to-QRPP QSOs.

VIII. Bug Reports and Other Contributions

This is a homebrew, personal project, without commercial support. Perhaps the best way to report a bug is as a github issue. As with any project, please review the known issues (https://github.com/conr2286/PocketFT8Xcvr) prior to submitting a duplicate report.

If you wish to submit a github pull request to incorporate your bug fix or enhancement upstream, please contact me at conr2286@gmail.com to discuss your proposal.

IX. Spectral Purity


The analysis was obtained during modulation with the carrier at 7074 kHz using the 40M 5-Pole Chebyshev low-pass filter. Note the strongest displayed spur lies below the fundamental, in the neighborhood of about 200 kHz, and is at least ~40 dB down. The 2nd harmonic is in the noise (consistent with the PA’s square wave output) and the 3rd ~50 dB down. The harmonics are no problem and the 200 kHz spur easily cleansed by a resonant antenna, or trivial high-pass filter that also reduces AM broadcast noise into the receiver. This spur deserves further investigation.

# Acknowledgments

Pocket FT8 Revisited [6] is a derivative of Charles Hill’s (W5BAA) Pocket FT8 project [5] with important contributions from Ricardo Caritti (the Si4735 library), Karlis Goba (YL3JG, the FT8 library), Barb (WB2CBA, the SN74ACT244 PA), and many other widely available Adafruit, Arduino and PJRC libraries. Charles and Barb continue their work with the DX FT8 project [7], another Pocket FT8 derivative. I am indebted to tips from now-forgotten bloggers (Hans and others) for optimizing the phase noise performance from the Si5351, optimizing the sensitivity of the Si4735 receiver, combined RF/AF/digital PCB design guidelines, and getting the most from the Teensy 4.1 MCU. With regard to the Si4735, I cannot overemphasize the importance of good PCB design and isolating the chip on its own I2C bus as the Si4735 seems quite noise-sensitive.

Back in the 60s, the ARRL published an amazing receiver for its day, the Junior Miser’s Dream, that accomplished so much with so little. Its focused design influenced my engineering career, discouraging unwarranted complexity. The Pocket FT8 revisits that theme in a digital world. May you too stand on the shoulders of giants.

References

[1] S. Franke, B. Somerville and J. Taylor. “The FT4 and FT8 Communication Protocols,” QEX, July-August 2020.
[2] SKYWORKS. “AN619 Manually Generating an Si5351 Register Map for 10-MSOP and 20-QFN Devices,” September 2021.
[3] SKYWORKS. “AN1234 Manually Generating an Si5351 Register Map for 16QFN Devices,” December 2021.
[4] VE2ZAZ. “VE2ZAZ Si5351 Synthesizer Board,” https://ve2zaz.net/Si5351_Synth/Si5351_Synth.htm, November 2019.
[5] Charles Hill. https://github.com/Rotron/Pocket-FT8
[6] J. Conrad KQ7B. https://github.com/conr2286/PocketFT8Xcvr

[7] Charles Hill. https://github.com/WB2CBA/DX-FT8-FT8-MULTIBAND-TABLET-TRANSCEIVER

[^1] Jim Conrad, KQ7B, is retired from the computer industry with his wife on their little farm near Grangeville, Idaho (e-mail: conr2286@gmail.com). The many nearby SOTA and POTA sites remain an inspiration for this project.

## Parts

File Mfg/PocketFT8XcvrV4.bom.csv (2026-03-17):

Reference | Value | Footprint | Qty | DNP | # | Manufacturer | Description | Notes | Mfg Part # | Type
Y1 | ASTXMH11-25.000MHZ-T | ASTX_H11_25_000MHZ_T:XTAL_ASTX-H11-25.000MHZ-T | 1 |  | 1 | Abracon | ASTX-H11-25.000MHZ-T. -30 ~ +75C | Do not substitute | ASTX-H11-25.000MHZ-T | SMD
U4 | SI5351C-B-GM | SI5351C-B-GM:QFN20_4X4_SKY | 1 |  | 2 | Skyworks Solutions | IC CLOCK GENERATOR 20QFN | https://www.digikey.com/en/products/detail/skyworks-solutions-inc/SI5351C-B-GM/3679850 (Do not substitute) | SI5351C-B-GM | SMD
U3 | SN74ACT244DWR | sn74act244dwr:DW20 | 1 |  | 3 | TI | IC BUFF NON-INVERT 5.5V 20SOIC | Do not substitute | SN74ACT244DWR | SMD
U2 | Si4735-D60-GU | Package_SO:SSOP-24_3.9x8.7mm_P0.635mm | 1 |  | 4 | Skyworks Solutions | AM/FM/SW/LW Broadcast Radio Receiver with RDS/RBDS | Do not substitute | SI4735-D60-GU | SMD
R11,R12,R13 | 510 OHM | Resistor_SMD:R_0603_1608Metric | 3 |  | 5 | Yageo | RES 510 OHM 5% 1/10W 0603 | Substitutions OK |  | SMD
R7 | 51 OHM | Resistor_SMD:R_0603_1608Metric | 1 |  | 6 | Yageo | RES 51 OHM 5% 1/10W 0603 | Substitutions OK | RC0603JR-0751RL | SMD
R6 | 10k | Resistor_SMD:R_0603_1608Metric | 1 |  | 7 | Yaego | Resistor | Substitutions OK | AF0603JR-0710KL | SMD
R3,R4 | 47k | Resistor_SMD:R_0603_1608Metric | 2 |  | 8 | Yageo | Resistor | Substitutions OK | RC0603JR-0747KL | SMD
R1,R2,R5,R8,R9 | 2.2k | Resistor_SMD:R_0603_1608Metric | 5 |  | 9 | Yageo | 2.2k 5% 1/10 Watt 0603 | Substitutions OK | RC0603JR-132K2L | SMD
Q1 | 2N7002DW | digikey-footprints:SOT-363 | 1 |  | 10 | ON Semiconductor | DUAL MOSFET N-CH 60V 0.115A SC70-6 | Do not substitute | 2N7002DW | SMD
C8,C9,C10,C13,C14,C15,C18,C19,C20,C21,C22,C23,C25,C27,C28,C29,C30 | 0.1UF | Capacitor_SMD:C_0603_1608Metric | 17 |  | 11 | Kemet | CAP CER 0.1UF 16V X7R 0603 | Substitutions OK | C0603C104K4RACTU | SMD
C5,C6,C7,C11,C16 | 10UF | Capacitor_SMD:C_0805_2012Metric | 5 |  | 12 | Kemet | CAP CER 10UF 16V X5R 0805 | Substitutions OK | C0805C106K4PAC7800 | SMD

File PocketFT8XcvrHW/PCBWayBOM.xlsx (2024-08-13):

Designator | Quantity | Value | Footprint | Package | MPN | DNP | Mount_Type | Description | Mfg Part # | Category | Family | Manufacturer | Status | Description_1 | Type | Notes | Field5 | PROD_ID | Voltage | Tolerance | Height | Mouser Part Number | Mouser Price/Stock | Digi-Key_PN | DK_Datasheet_Link | DK_Detail_Page | PARTREV | STANDARD | SNAPEDA_PN | MAXIMUM_PACKAGE_HEIGHT
BAT1 | 1 | BU2032SM-JJ-GTR | BU2032SM-JJ-GTR_MPD |  |  |  | smt | BATT HOLDER COIN 20MM 1 CELL SMD | BU2032SM-JJ-GTR | Battery Products | Battery Holders, Clips, Contacts | MPD (Memory Protection Devices) | Active | BATTERY HOLDER COIN 20MM PC PIN | SMD | Must mount topside
C1, C11, C12, C13, C14, C15, C16, C17, C19, C20, C25, C27, C28, C29, C3, C4 | 16 | 0.1UF | C_0603_1608Metric |  |  |  | smt | CAP CER 0.1UF 16V X7R 0603 | C0603C104K4RAC7867 |  |  | Kemet |  |  | SMD | Substitutions OK | [C4]CAP-07885; [C3]CAP-08390; [C12,C13,C14,C15]CAP-07886; [C25,C27,C28,C29]CAP-08604 | CAP-00810 | 16V | 10%
C10 | 1 | 75PF | C_0805_2012Metric |  |  | Yes | smt | Unpolarized capacitor
C2, C5, C6, C7 | 4 | 10UF | C_0805_2012Metric |  |  |  | smt | CAP CER 10UF 16V X5R 0805 | C0805C106K4PAC7800 |  |  | Kemet |  |  | SMD | Substitutions OK |  | [C6,C7]CAP-11015; [C5]CAP-13930 | [C6,C7]6.3V; [C5]16V | [C6,C7]20%; [C5]10%
C26 | 1 | 47PF | C_0805_2012Metric |  |  | Yes | smt | Unpolarized capacitor |  |  |  |  |  |  |  |  | CAP-08913 | CAP-08913 | 100v | 1%
C8 | 1 | 75PF | C_0805_2012Metric |  |  | Yes | smt | Unpolarized capacitor
C9 | 1 | 243PF | C_0805_2012Metric |  |  | Yes | smt | Unpolarized capacitor
D1 | 1 | XMIT | LED_D5.0mm |  |  | Yes | tht | Light emitting diode
IC1 | 1 | SI5351C-B-GM1 | QFN50P300X300X90-17N-D |  | SI5351C-B-GM1 |  | smt | Clock Generators & Support Products I2C programmable, any-frequency, any-output, reference clock input, 4-output LVCMOS clock generator |  |  |  | Skyworks |  |  |  |  |  |  |  |  | 0.9 | 634-SI5351C-B-GM1 | https://www.mouser.co.uk/ProductDetail/Skyworks-Solutions-Inc/SI5351C-B-GM1?qs=r5DSvlrkXmLdhgVRtlBfMw%3D%3D
J1 | 1 | HX8357D SPI | PinHeader_1x20_P2.54mm_Vertical |  |  | Yes | tht | Generic connector, single row, 01x20, script generated (kicad-library-utils/schlib/autogen/connector/)
J2 | 1 | 22-23-2021 | PinHeader_1x2_P2.54mm_Drill1.02mm |  | 22-23-2021 | Yes | tht | CONN HEADER VERT 2POS 2.54MM |  | Connectors, Interconnects | Rectangular Connectors - Headers, Male Pins | Molex | Active | CONN HEADER VERT 2POS 2.54MM |  |  |  |  |  |  |  |  |  | WM4200-ND | https://media.digikey.com/pdf/Data%20Sheets/Molex%20PDFs/A-6373-N_Series_Dwg_2010-12-03.pdf | /product-detail/en/molex/22-23-2021/WM4200-ND/26667
J3 | 1 | GPS | PinHeader_1x4_P2.54mm_Drill1.02mm |  | 0022232041 | Yes | tht | CONN HEADER VERT 4POS 2.54MM |  | Connectors, Interconnects | Rectangular Connectors - Headers, Male Pins | Molex | Active | CONN HEADER VERT 4POS 2.54MM |  |  |  |  |  |  |  |  |  | WM4202-ND | https://www.molex.com/pdm_docs/sd/022232041_sd.pdf | /product-detail/en/molex/0022232041/WM4202-ND/26671
J5 | 1 | HX8357D 8-BIT | PinHeader_1x20_P2.54mm_Vertical |  |  | Yes | tht | Generic connector, single row, 01x20, script generated (kicad-library-utils/schlib/autogen/connector/) |  |  |  |  |  |  |  | Mechanical support without electrical connections
L1 | 1 | 0.5uH | L_Toroid_Vertical_L10.0mm_W5.0mm_P5.08mm |  |  | Yes | tht | Inductor with ferrite core
L2 | 1 | 0.5uH | L_Toroid_Vertical_L10.0mm_W5.0mm_P5.08mm |  |  | Yes | tht | Inductor with ferrite core
L3 | 1 | 1.0mH | IND_BOURNS_RLB9012 |  |  | Yes | tht | FIXED IND 1MH 510MA 2.9 OHM TH | RLB9012-102KL |  |  | Bourns |  |  | SMD |  |  |  |  |  |  |  |  | RLB9012-102KL-N
Q1 | 1 | 2N3904 | TO-92-3 |  |  | Yes | tht | TRANS NPN 40V TO-92 | 2N3904 | Discrete Semiconductor Products | Transistors - Bipolar (BJT) - Single | Central Semiconductor Corp | Active | TRANS NPN 40V TO-92 | THT |  |  |  |  |  |  |  |  | 2N3904CS-ND | https://my.centralsemi.com/get_document.php?cmp=1&mergetype=pd&mergepath=pd&pdf_id=LSSGP072.PDF | /product-detail/en/central-semiconductor-corp/2N3904/2N3904CS-ND/4806876
Q2 | 1 | 2N3906 | TO-92-3 |  |  | Yes | tht | TRANS PNP 40V TO-92 | 2N3906 | Discrete Semiconductor Products | Transistors - Bipolar (BJT) - Single | Central Semiconductor Corp | Active | TRANS PNP 40V TO-92 | THT |  |  |  |  |  |  |  |  | 2N3906CS-ND | https://my.centralsemi.com/get_document.php?cmp=1&mergetype=pd&mergepath=pd&pdf_id=LSSGP072.PDF | /product-detail/en/central-semiconductor-corp/2N3906/2N3906CS-ND/4806878
Q3 | 1 | 2N7000 | TO-92-3 |  | 2N7000 | Yes | tht | MOSFET N-CH 60V 200MA TO-92 | 2N7000 | Discrete Semiconductor Products | Transistors - FETs, MOSFETs - Single | ON Semiconductor | Active | MOSFET N-CH 60V 200MA TO-92 | THT |  |  |  |  |  |  |  |  | 2N7000FS-ND | https://www.onsemi.com/pub/Collateral/NDS7002A-D.PDF | /product-detail/en/on-semiconductor/2N7000/2N7000FS-ND/244278
Q4 | 1 | 2N7000 | TO-92-3 |  | 2N7000 | Yes | tht | MOSFET N-CH 60V 200MA TO-92 | 2N7000 | Discrete Semiconductor Products | Transistors - FETs, MOSFETs - Single | ON Semiconductor |  | MOSFET N-CH 60V 200MA TO-92 | THT | Substitions OK |  |  |  |  |  |  |  | 2N7000FS-ND | https://www.onsemi.com/pub/Collateral/NDS7002A-D.PDF | /product-detail/en/on-semiconductor/2N7000/2N7000FS-ND/244278
R1, R2, R5 | 3 | 2.0K | R_0603_1608Metric |  |  |  | smt | RES 2K OHM 5% 1/10W 0603 | RC0603JR-072KL |  |  | Yageo |  |  | SMD | Substitutions OK |  | RES-08296
R10, R9 | 2 | 5.1K | R_0603_1608Metric |  |  |  | smt | RES 5.1K OHM 5% 1/10W 0603 | RC0603JR-075K1L |  |  | Yageo |  |  | SMD | Substitutions OK
R11, R8 | 2 | 510 Ohm | R_0603_1608Metric |  |  |  | smt | RES 510 OHM 5% 1/10W 0603 | RC0603JR-07510RL |  |  | Yageo |  |  | SMD | Substitutions OK |  | RES-08296
R3, R4 | 2 | 47K | R_0603_1608Metric |  |  |  | smt | RES 47K OHM 1/10W 5% 0603 | RC0603JR-0747KL |  |  | Yageo |  |  | SMD | Substitutions OK |  | RES-07871
R6 | 1 | 10K | R_0603_1608Metric |  |  |  | smt | RES 47.0K OHM 1/8W 0805 SMD | RC0603JR-0710KL |  |  | Yageo |  |  | SMD | Substitutions OK |  | RES-00824
R7 | 1 | 51 OHM | R_0603_1608Metric |  |  |  | smt | RES 51 OHM 5% 1/2W 1210 | RC1210JR-0751RL |  |  | Yageo |  |  | SMD | Substitutions OK
TN1 | 1 | Teensy4.1 | Teensy41 |  |  | Yes | tht | Teensy 4.1 Microcontroller
U1 | 1 | MCP3422A1T-E/SN | SOIC-8_3.9x4.9mm_P1.27mm |  |  |  | smt | IC ADC 18BIT SIGMA-DELTA 8SOIC | MCP3422A1T-E/SN |  |  | Microchip Technology |  |  | SMD
U2 | 1 | Si4735-D60-GU | SSOP-24_3.9x8.7mm_P0.635mm |  |  |  | smt | RF RX AM/FM 153KHZ-279KHZ 24SSOP | SI4735-D60-GU |  |  | Skyworks Solutions |  |  | SMD
U3 | 1 | GVA-84+ | SOT-89-3_Handsoldering |  |  |  | smt | DC-7000MHz +16dB Gain Block, SOT-89 | GVA-84+ |  |  | Mini-Circuits |  |  | SMD | hand soldering footprint used for better heat sink
Y1 | 1 | ASTX-H11-25.000MHZ-T | XTAL_ASTX-H11-25.000MHZ-T |  |  |  | smt | ASTX-H11-25.000MHZ-T. -30 ~ +75C | ASTX-H11-25.000MHZ-T |  |  | Abracon |  |  | SMD |  |  |  |  |  |  |  |  |  |  |  | 05.13.15 | Manufacturer Recommendations | ASTX-H11-25.000MHZ-T | 1.10mm

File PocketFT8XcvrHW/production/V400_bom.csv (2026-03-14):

Designator | Footprint | Quantity | Value | LCSC Part #
C10, C13, C14, C15, C18, C19, C20, C21, C22, C23, C25, C27, C28, C29, C30, C8, C9 | 0603 | 17 | 0.1UF
C11, C16, C5, C6, C7 | 0805 | 5 | 10UF
Q1 | SOT-363 | 1 | 2N7002DW
R1, R2, R8, R9 | 0603 | 4 | 2.0K
R11 | 0603 | 1 | 510 Ohm
R12, R13 | 0603 | 2 | 510
R3, R4 | 0603 | 2 | 47K
R5 | 0603 | 1 | 2.2K
R6 | 0603 | 1 | 10k
R7 | 0603 | 1 | 51 OHM
U2 | SSOP-24_3.9x8.7mm_P0.635mm | 1 | Si4735-D60-GU
U3 | DW20 | 1 | SN74ACT244DWR
U4 | QFN20_4X4_SKY | 1 | SI5351C-B-GM
Y1 | XTAL_ASTX-H11-25.000MHZ-T | 1 | ASTXMH11-25.000MHZ-T

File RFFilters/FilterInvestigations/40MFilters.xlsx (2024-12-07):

 | Value | Core | Wire | Turns | Inches | Notes
T1 |  | FT37-43 | #26 | 10 |  | Bifilar
L1 | 240nH | T37-0 | #26 | 22 | 14
L2 | 6.8 uH | T37-1 | #28 | 29 | 17
L3 | 240nH | T37-0 | #26 | 22 | 14
C1 | 2.4nF
C2 | 91pF
C3 | 2.4nF

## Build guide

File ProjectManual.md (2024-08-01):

# Project Journal

# Outstanding Questions
Q: Why did Hans power the HX8357D from the Teensy's 3.3V regulator rather then the
5V supply where more current is available?

Q: What is the purpose of Charles' complex RC network between Si4735
  and Teensy?  The Skyworks application notes suggest a simple approach.
  
Q: Is a notch needed in the output filter to reject the second harmonic?
A: Simulation of the filter using a swept sine wave source found weak rejection of the second harmonic at 36 mHz.  Adherance to US FCC 97.307d seemingly depends upon the square wave XCLK composition of primarily odd-numbered harmonics.  Simulation with a trap constructed with a capacitor paralleled with L1 provides strong attenuation of the 36 mHz harmonic with minimal degradation of the 3rd at 54 mHz.  Conclusion:  add C26 in parallel with L1 to schematic but don't load the component on the board unless spectral testing requires it.

Q: Why did Charles include T1 following the MMIC if the MMIC's output impedance is 50 ohms?

# Log
1. HX8537D molex connector wired to connect IM2 to +3OUT, avoiding the
need to solder the on-board jumper.
2. Paranoia:  A goal of the bypass caps near the active devices/modules is to localize the anticipated ground currents rather than disperse them throughout the ground plane where they might become troublesome.

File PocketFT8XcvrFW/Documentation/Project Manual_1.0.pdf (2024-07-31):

### Pocket FT8: A Palm Size FT 8 Transceiver

Scope
This document is written to help you build your own self contained FT8 Rig. Listed below are the main features of the project.
- Small Size, 3.5” X 2.75” X 1.125”
- 100 mW power output @ 50 ohm load
- 1 uVolt Receiver Sensitivity
- Single 5 volt power input, battery or wall wart
- Silicon Labs Technology, Si4735 SSB Receiver & Si5351 Transmit FSK Clock
- SD Card Contact Logging
- 320 X 480 Resistive Color Touch Screen

Attributions
This project is based on two significant software projects:

Si4735 Library developed by Ricardo Caritti: https://github.com/pu2clr/SI4735

FT8 Decoding Library by Karlis Goba: https://github.com/kgoba/ft8_lib

DSP Audio Architecture
Decoding FT8 requires significant data storage and processing speed.

In order to optimize both program storage and processing speed requirements so that the Teensy 3.6 is not over taxed, the Teensy Audio Library has been modified to allow Analog to Digital conversion to be run at the rate of 6400 samples per second. This allows audio data processing to be done at 3200 Hz. The 3200 Hz audio processing with a 2048 FTT to process the received audio for FT8 decoding yields a bin spacing of 3.125 Hz.

The algorithms developed by Karlis Goba use the 3.125 Hz spaced FFT bins to be screened in both frequency and time so that errors in symbol frequency and time reception can be overcome to provide really great FT8 decoding. The end spacing of the FT8 algorithms is 6.25 Hz.

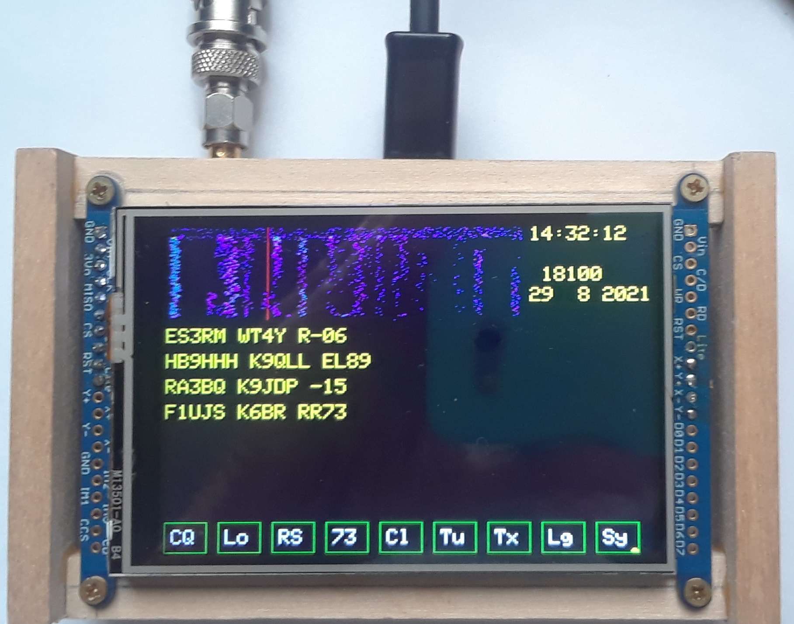
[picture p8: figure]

Overall Architecture
The project consists of the following hardware modules:

Teensy 3.6
https://www.pjrc.com/store/teensy36.html

Adafruit 320 X 480 TFT Touchscreen https://learn.adafruit.com/adafruit-3-5-color-320x480-tft-touchscreen-breakout

Adafruit Si5351 Clock Breakout Board https://www.adafruit.com/product/2045

Si4735 Radio Receiver IC:
https://www.semiconductorstore.com/cart/pc/viewPrd.asp?idproduct=51832 (https://www.microchip.com/en-us/product/MCP3422)

Microchip MCP 3422 Analog to Digital IC https://www.microchip.com/en-us/product/MCP3422

Mini-Circuits GVA84++ Monolithic RF Amplifier https://www.minicircuits.com/pdfs/GVA-84+.pdf

The Teensy 3.6 communicates with the Si5351 Clock, Si4735 Receiver and MCP 3244 A/D via a common I2C Bus and the Touchscreen Display via a SPI Bus.

The Microchip MCP 3422 Analog to Digital IC is used to interface the Touch Screen touch point coordinates to the Teensy processor. One may ask “Why not use two of the Analog Pins on the Teensy?”. An attempt was made to do just this. However, the high rate of A to D sampling required by the Teensy Audio Library swamps out polling of the touch screen analog data. So, the MCP3422 is used so the touch point data may be fed to the Teensy 3.6 via the I2C Bus.

The project connections are shown on two drawings shown below. One drawing shows the connections between the modules listed above and the other shows the low pass filters and PTT control associated with the GVA-84+ transmit RF amplifier. The values for the low pass filers are set for 17 Meter (18.100 mHz) operation.

Touch Screen (TS) | Teensy 3.6 (TN)

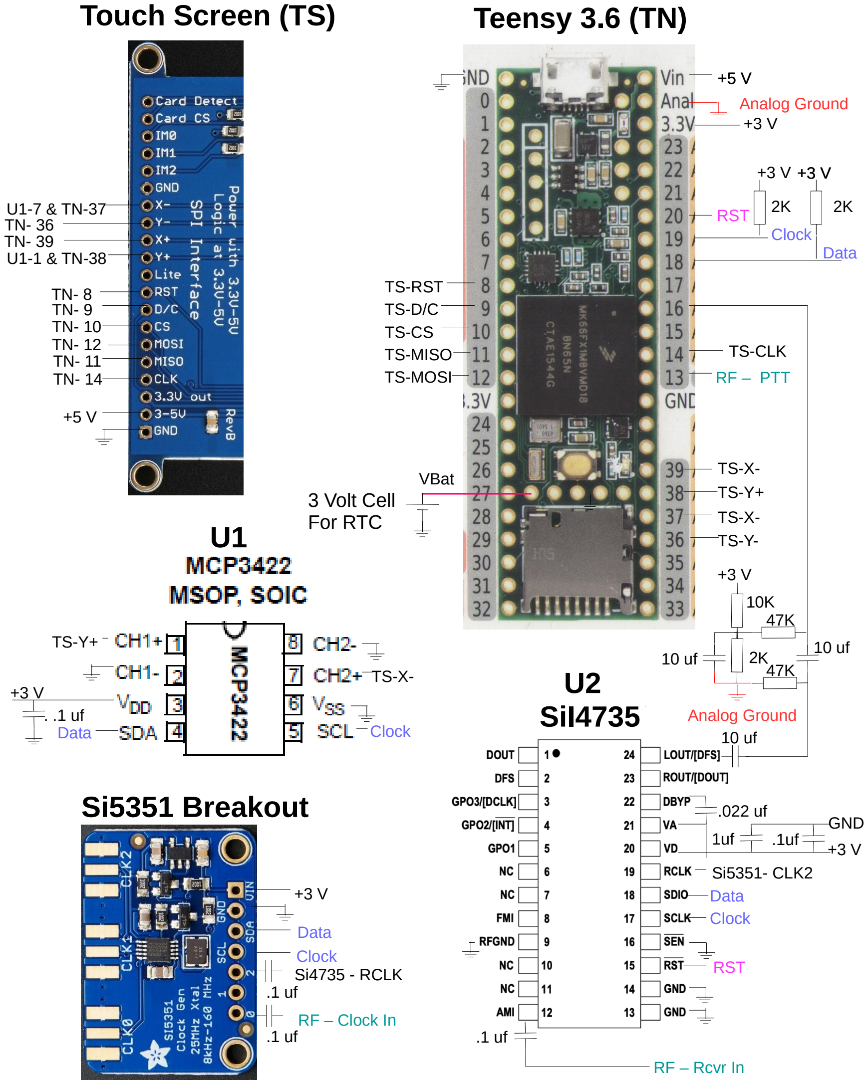
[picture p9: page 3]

U1

U2

## SiI4735

## Si5351 Breakout

+5 V

+3 V

+5 V

+3 V

TS-Y+

Clock

Data

Clock

TS-X-

Data

Data

Clock

Clock

Clock

Data

2K

47K

2K

+3 V +3 V

+5 V

U1-1 & TN-38

U1-7 & TN-37 | RST

RST

.022 uf

+3 V

10 uf

TN- 36
TN- 39

TN- 14

TN- 11

TN- 12

TN- 10

TN- 9

TN- 8

TS-Y+
TS-X-TS-Y-

TS-X-

TS-RST
TS-D/C
TS-CS
TS-MISO | TS-CLK
TS-MOSI

Si4735 - RCLK

.1 uf
RF – Rcvr In

Si5351- CLK2

RF – Clock In

+3 V

10 uf

10K

2K

Analog Ground

47K
10 uf

. .1 uf

GND
1uf .1uf

RF – PTT

.1 uf

.1 uf

+3 V
Analog Ground

+3 V

VBat
3 Volt Cell
For RTC

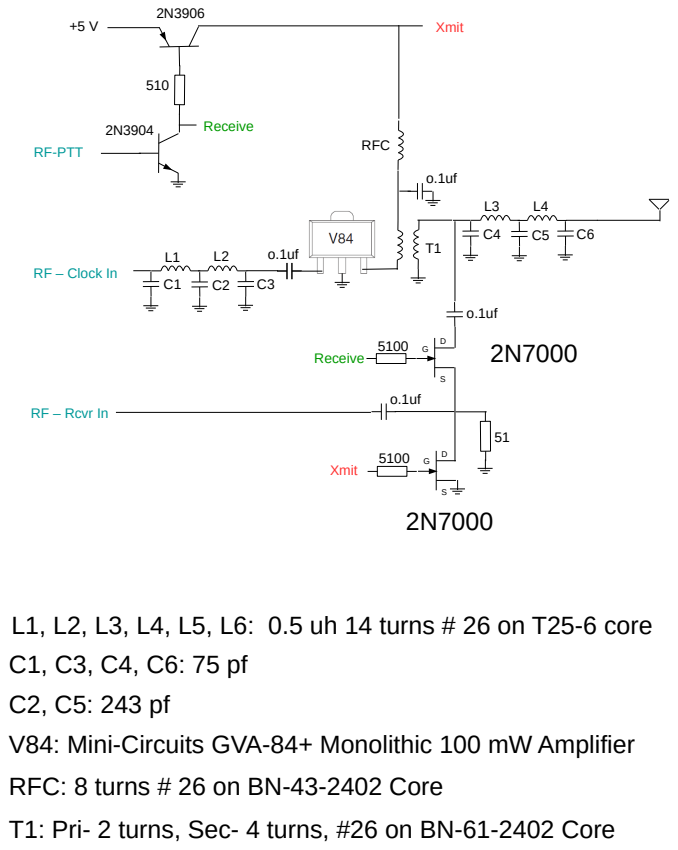
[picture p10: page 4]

L1, L2, L3, L4, L5, L6: 0.5 uh 14 turns # 26 on T25-6 core
V84: Mini-Circuits GVA-84+ Monolithic 100 mW Amplifier
RFC: 8 turns # 26 on BN-43-2402 Core
T1: Pri- 2 turns, Sec- 4 turns, #26 on BN-61-2402 Core

Building the Firmware
The firmware is built using the Arduino IDE along with the Teensy Libraries. Please use this link for instructions on installing the IDE : https://www.pjrc.com/teensy/td_download.html

As stated above, the Teensy Audio Library will need to be modified to support 6400 sample per second A to D sampling. To do this follow this path: C:\Arduino\arduino-1.8.5\hardware\teensy\avr\libraries\Audio\utility to the “utility” folder as shown below:

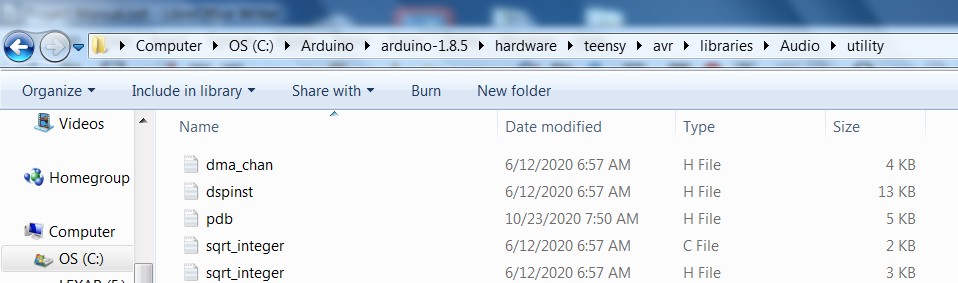
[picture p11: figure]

Replace the pdb.h file with the one provided with this project archive.

Shown below is the board selection for the Teensy 3.6 board:

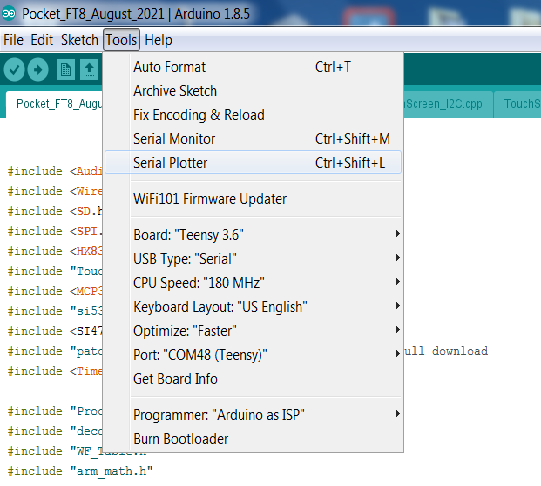
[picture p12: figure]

The following libraries are required for the project. These libraries are provided in the Project Driver Files folder:

Etherkit_Si5351 | HX8357_t3-master
MCP342X | Si4735-master

Real Time Clock
The Teensy Real Time Clock (RTC) is used to display relative time and to mark log entries with date – timegroups. The RTC is not used to synchronize the reception of FT8 Traffic.

Instead, the software is manually synchronized using the touch screen button marked “Sy”. This technique is copied from the work done by Karlis Goba and is a very effective way to sync with the current FT8 traffic.

A 3 volt coin cell battery is required to be connected to the Vbat pin on the Teensy 3.6. In order to set the date and time of the RTC please use the https://www.unixtimestamp.com/ to calculate a target sync time along with the Time.pde file included in the project archive to set the Teensy RTC.

Setting Your Call and Location
Before you build your project please modify the Pocket_FT8_August_2021.ino file, Lines 58 & 59 to use your call and your location Maidenhead Locator group. Shown below are Lines 58 & 59 in the .ino file

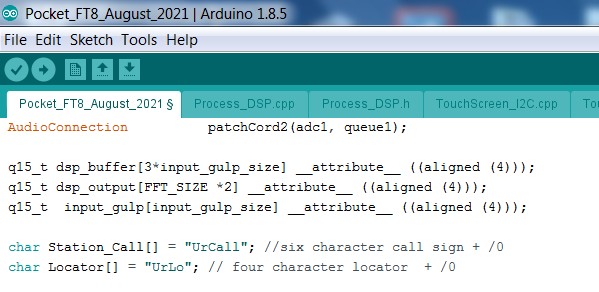
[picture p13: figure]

Setting Transmit Offset
Although both the transmit and receive functions are derived from the same Si5351 there will be an offset between the transmit frequency shown by the Red Line in the spectrum display and the actual transmit frequency of the FT_8 FSK signal. This is the result of the receiver using Clock 2 of the Si5351 and the transmitter using Clock 1 of the Si5351. To provide synchronization of the transmit frequency with the receive frequency a Serial interface has been included in the project firmware.

To use this interface install a copy of Tera Term: https://en.wikipedia.org/wiki/Tera_Term

Use Tera Term to establish a Serial connection to the Teensy 3.6 at 9600 Baud using the USB port on the Teensy. This is the same USB port used to program the Teensy. Then reboot the Teensy to see the entire start up message. You will see the instructions for changing the Transmit Frequency Offset in the Tera Term serial monitor window as shown below.

Then touch the Tu button to place the transceiver in the tune mode. Use the “u” key to move the transmitted signal up in frequency and the “d” button to move the transmitted frequency down.

The movement of the transmitted frequency may be viewed in real time on the spectrum display.

When the transmitted frequency is under the red line, use the “s” key to save the modified Transmit Frequency Offset value to the Teensy EEPROM. When you reboot the Teensy, the value stored in the EEPROM is recalled so that the transmitted signal shows up under the red line.

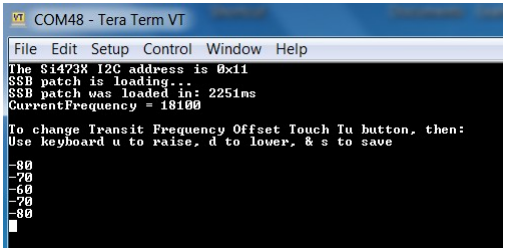
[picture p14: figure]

Pocket_FT8 User Operation

The user is presented with a number of data displays, touch buttons and touch areas as shown above.

Display Items
Starting at the top left hand, the received audio / FT8 spectrum is shown. The vertical red line on the spectrum display shows the FT8 transmit frequency.

At the top right hand side, the RTC time, selected station call sign, base FT8 RF Frequency, and RTC date are shown. In the figure above, the selected station call sign is blank since no station has been selected yet.

In the left center pane the received FT8 traffic is shown.

In the right center pane the FT8 messages wherein your station is being called are listed.

Touch Areas
Two touch areas are provided.

One is the FT8 spectrum. Touching this area moves the FT8 transmit frequency. The red vertical line moves to show the selected FT8 transmit frequency.

The other touch area is the left center pane where the FT8 traffic is listed. You may select one of the FT8 messages so that you may compose a message to the transmitting station. The call of the selected transmitting station is shown in the top right hand display area as described above.

The figure below illustrates the results of touching the message”IZ2KWV NK1I FN43” where the calling station call’s “NK1I” is displayed at the top right hand corner right below the displayed RTC time.

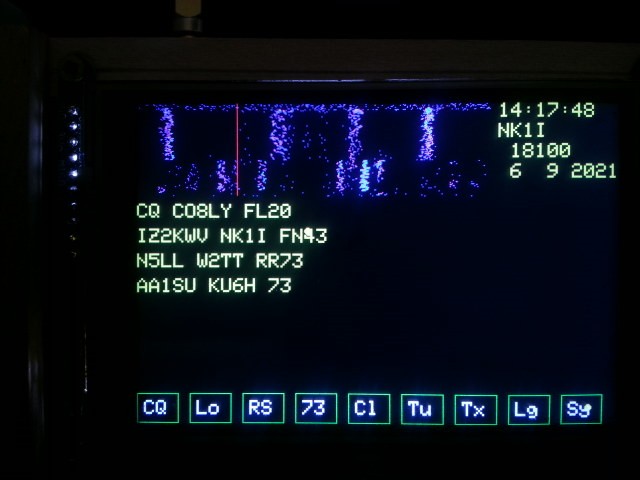
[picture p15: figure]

Touch Buttons

Nine touch buttons are displayed at the bottom of the screen.

CQ toggles between the beacon (CQing) mode and the QSO mode of operation. Green means the QSO mode is selected. Red means CQ mode is selected.

Lo generates a location message; e.g., W5ITU W5BAA EM00

RS generates a signal strength message; e.g, W5ITU W5BAA -7

### 73 generates a 73 message; e.g, W5ITU W5BAA RR73

The message composed and qued up for transmission is shown in white on the left hand side of the screen right above the touch buttons.

Cl clears the user composed FT8 message described right above.

Tu puts the transceiver in transmit with with a steady tone at the frequency shown by the vertical red line in the spectrum display.

Tx is used in the QSO mode so that the user composed FT8 message is transmitted on the next available FT8 time slot.

Lg is used to toggles the traffic logging on to the SD card on or off. Red means logging is on.

Sy allows the user to synchronize the FT8 receiver with the rest of the FT8 world.

Shown below is the result of touching the Lo button with the selected call of NK1I

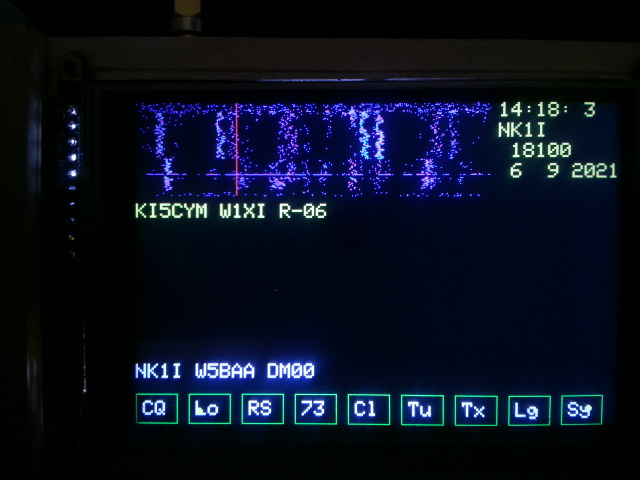
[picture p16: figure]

The other two message compose touch buttons, RS and 73 operate in the same way.

The FT8 has a traffic manager that works in either a QSO mode or CQ (beacon) mode.

In the QSO mode the user first selects a station to call by touching one of the FT8 traffic messages as described above. Then, by using the Lo, RS, or 73 touch buttons the user may compose the message to send next. Finally, the user must touch the Tx button so that the displayed composed message is transmitted in the next available FT8 time slot.

In the CQ mode the user simply touches the CQ button and the button turns red and then the user may observe the traffic. As stations respond to your CQ call, their FT8 messages are displayed in the center right hand pane as shown below.

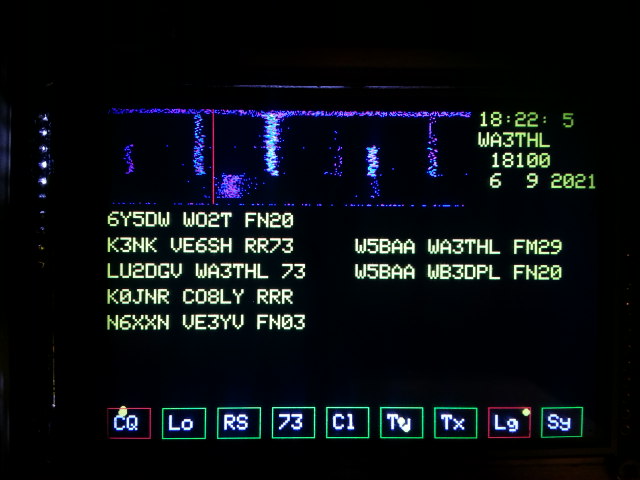
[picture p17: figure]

Further, if the Lg, Log button, is touched the button turns red and the traffic logging to SD card is turned on. Shown below are the log entries for the CQ message responses are shown above.

**********************
6/ 9/2021 17:28:39 W5BAA WB3DPL FN20
6/ 9/2021 18:11:39 W5BAA WA3THL FM29

The messages are logged along with the date and time of the received message. The date and time are taken from the Teensy Real Time Clock (RTC).

That’s All Folks!

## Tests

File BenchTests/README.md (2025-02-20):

# README.MD

The BenchTests exist to check-out a newly constructed board.  They are embedded tests, executing in  Teensy.  Most are easily built using the Arduino IDE 2.00 as they are fairly simple in structure.

## Usage
The tests are numbered, Test01-*, Test02-*, etc.  The numerical order of the tests offers a recommended ordering of which tests to execute first, second and so on.

## Issues
Considerable duplication of supporting code between PocketFT8FW and the BenchTests exist because the Arduino IDE does not readily handle code sharing between tests and the production firmware.  The longterm solution to this problem will likely have the tests join the production firmware in PlatformIO which offers an improved way to share code between libraries and tests.

## Documentation
At this time, many tests include unfortunately sparce comments in the code describing what they exercise and what results can be expected.

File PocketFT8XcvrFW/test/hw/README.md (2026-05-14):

##DESCRIPTION
    This folder contains PlatformIO Unity tests for turning-on new Pocket FT8 hardware (PCB)

##VERSION
    As of March 23, 2026, the tests target Version 4 of the hardware

##NOTES
    * A new board should be fully assembled with both SMT and THT parts installed prior to attempting any of these tests
    * A new board, passing a "smoke" pre-test, is ready to attempt test_01
    * The tests are named (e.g. test_01, test_02, etc) in numerical order, the order in which they should be attempted on a new board
    * These tests are not all pure unit tests as some interact with the operator using the hardware (the purpose of the tests is to exercise real hardware)

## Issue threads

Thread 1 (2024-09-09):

V1.01 SCK and PTT reversed on Teensy digital pins 14 and 13

conr2286, 2024-09-09:
Overlooked pin change between Teensy 3.6 and 4.1 resulted in SCK (DCLK) on wrong Teensy 4.1 pin and PTT connected to the Teensy 4.1 SCK pin.  The problem was discovered by Test03-Display.

A workaround for V1.01 requires PCB patches, test and FW changes:

* Move PTT from digital pin 13 to 14 for Teensy 4.1 by removing R10 from V1.01 PCB and replacing it with a 5.1K leaded resistor between digital pin 14 and Q1-B.
* Cut DCLK trace between digital pin 14 and J1, and replace with jumper between Teensy 4.1 digital pin 13 and J1-17.
* Change firmware to move SCK to digital pin 13
* Change firmware to move PTT to digital pin 14
* Change Test02-XmitRecvLED to expect PTT signal on Teensy 4.1 digital pin 14

Permanent schematic, board, gerber, test and FW changes anticipated in V1.10 release.  No changes expected in the BOM.

--- KQ7B

Closed 2024-09-09.

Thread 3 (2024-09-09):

XMIT LED is always "on" and cannot be turned-off

conr2286, 2024-09-09:
The XMIT LED, D1, is always illuminated and cannot be turned-off.  The problem was discovered by Test02-XmitRecvLED.

Investigation found KiCAD used an incorrect TO-92 footprint for Q1, 2N3904, reversing the Base and Collector pins.

Further investigation confirmed the correct TO-92 footprint was used for Q2, 2N3906.

conr2286, 2024-09-09:
A temporary workaround on the V1.01 PCB will require a patch to reverse the Q1 leads.  A permanent fix will require a new footprint for Q1 and revised Gerbers.  The schematic and tests are OK.

conr2286, 2024-09-10:
The Digikey 2N3904 symbol reversed the pin assignments for B and C

Closed 2024-09-10.

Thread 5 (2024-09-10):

Investigate whether Test05-Touchpad reports the expected X,Y coordinates as they are suspicious

conr2286, 2024-09-10:
This may be an issue with the test, the board, or both.  But the user has no way of knowing if Test05-Touchpad is reporting the expected X,Y coordinates (which appear suspicious as they apparently are not in the same coordinate system).

Closed 2024-09-10.

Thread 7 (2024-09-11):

Test06-Si5351 Occasionally reports LOL_B, LOL_A, etc

conr2286, 2024-09-11:
Frequent device status (SI5351 Register 0) readings by Test06-Si5351 occasionally report the value, 0x69. rather than the expected 0x00.   Notes:

* 0x69 == 0110 1001 in which the .11..... bits are the LOL_B and LOC_A, the ....1... bit is reserved, and the .......1 bit asserts the unlikely possibility that the Si5351 is changing its factory-set Revision ID.
* Oscilloscope confirms a solid CLKIN signal of 25 mHz.  Loss of lock is unlikely unless the TCXO or related power supplies are glitchy.

conr2286, 2024-09-12:
Fixed.  Si5351::init left ref_freq[] and corr[] entries for SI5351_PLL_INPUT_CLKIN uninitialized causing set_pll to divide by 0, the ref_freq.

Closed 2024-09-12.

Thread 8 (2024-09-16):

Touchpad needs coordination over full screen

conr2286, 2024-09-16:
Despite earlier naysaying, the Pocket FT8 GUI requires the touchpad coordinates to have access to the full screen area.

The problem arises from the MCP3422's use of an internal 2.048 Volt reference that limits touchpad access to a subset of the entire display area.

conr2286, 2024-09-16:
Resolved by adding R12 and R13 (510 Ohms) to lower the driven voltage to the touchpad so that it lies below the MCP3422's 2.048 Volt reference.  Tested the workaround with a patch to the V1.01 PCB.  Recalibrated the X/Y Min/Max values in Test05-Touchpad, Test09-GUI and the PocketFT8FW sketch.  Tests 05 and 09 now working correctly.

Closed 2024-09-16.

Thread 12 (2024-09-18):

PocketFT8Xcvr crashes and reboots following first calls to process_FT8_FFT(), extract_power(), and arm_rfft_q15()

conr2286, 2024-09-18:
PocketFT8Xcvr crash and reboot following first call to arm_rfft_q15() defined by arm_math.h for Teensy 4.1

conr2286, 2024-09-26:
This is not fully understood nor resolved.  The attached screenshot suggests that, just prior to invoking arm_rfft_q15, fft_inst.fftLenReal= 52232 which seems wholly ridiculous (seemingly should be 2048 q15 elements).
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

conr2286, 2024-09-30:
Bad build (bad mix of sketch and library .o files)

Closed 2024-09-30.

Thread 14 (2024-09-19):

CQ button ignored until received traffic appears

conr2286, 2024-09-19:
When operating with a dummy load, the CQ button is ignored.

conr2286, 2024-09-19:
The service_CQ() method is not invoked by update_offset_waterfall() which is not invoked by process_FT8_FFT() because the DSP_Flag is not set in loop().

The DSP_Flag will only be set after queue1.available() (defined by record_queue.h in AudioRecordQueue, derived from AudioStream)  returns true which is apparently not happening.

conr2286, 2024-09-30:
service_CQ() is not invoked by update_offset_waterfall until num_decoded_msg>0 which, without a complete RF chain on prototype, will not happen.

conr2286, 2024-10-20:
Pressing Tx button is not starting the transmitted CQ message either

conr2286, 2024-10-21:
In update_offset_waterfall, the conditional expression,
   **if (num_decoded_msg > 0 && WF_counter == 0) {**
was changed to become,
  **if (WF_counter == 0) {**
so that a successful decode is now unnecessary to transmit CQ.

conr2286, 2024-10-21:
Resolved.

Closed 2024-10-21.

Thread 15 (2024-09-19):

V1.01 PCB is using the Teensy 3.X rather than 4.X audio input network on pin A2

conr2286, 2024-09-19:
This is a HW problem in the V1.01 schematic, gerbers, and BOM.  Workaround:  replace the 10K Ohm 0603 R6 with a 2.2K 0603 resistor.

The Teensy audio input network (apparently for noise issues) is documented (only?) by the Audio System Design Tool, https://www.pjrc.com/teensy/gui/index.html?info=AudioInputAnalog

The V1.01 schematic is using the Teensy 3.X network version.  The Teensy 4.1 network is similar, but the value of R6 (in the V1.01 schematic) should be changed from 10K to 2.2K Ohms.

conr2286, 2024-10-15:
Resolved in KiCAD for future (e.g. V2.0) version of PCB

Closed 2024-10-15.

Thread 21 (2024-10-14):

Enhancement:  Implement a config file on SD

conr2286, 2024-10-14:
Configurable options might someday include:

- Station callsign
- Grid square or "gps"
- Operating frequency (within limits of the LP filter)
- SOTA summit
- Optional CQ info (e.g. CQ POTA or whatever)
- Frequency correction for TCXO
- Extra info for log file???

conr2286, 2024-10-15:
Initial Implementation on main.  The SD config.json file has potential applications for debugging as well as station operation.

Closed 2024-10-15.

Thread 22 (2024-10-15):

Receiver is not decoding FT8 traffic

conr2286, 2024-10-15:
Decoded FT8 traffic is not displayed.  The waterfall graph seems truncated with only the leftmost side displayed.

- Patching the received audio from the SI4735 into an amplified speaker plays FT8-sounding traffic.
- Playing a raw recording of the captured 16-bit single channel audio at 32000 samples/sec also sounds like FT8.

Timing problem???  GPS has not yet been implemented.

conr2286, 2024-10-16:
The ADC was running at the wrong sample rate.  Pocket FT8 requires a 6400 samples/second rate and this is implemented for Teensy 4.1 by modifying the definition of AUDIO_SAMPLE_RATE_EXACT in AudioStream.h to be #define AUDIO_SAMPLE_RATE_EXACT 6400.0f

With this fix in place, the Pocket FT8 Transceiver is now decoding and displaying some FT8 traffic, although it seems painfully sparse to me.

Closed 2024-10-16.

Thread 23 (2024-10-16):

The Pocket FT8 Transceiver seemingly doesn't display all the received messages

conr2286, 2024-10-16:
On an active 40M band, significant audio traffic is heard through the audio patch, but only a few decoded messages are displayed.

conr2286, 2024-10-17:
SI4735 noise problem?

- With the SigGen generating a steady carrier at 7075 kHz, the receiver audio emits ~1kHz tone.  This tone warbles with process_touch() enabled in loop(), and vanishes with process_touch() disabled.  Given the known issues with SI4735's sensitivities to I2C traffic, this noise may arise from polling the touch panel on I2C.

- But... even with process_touch() disabled, the scope connected to the audio sees a noisy 1kHz signal.  The tone is strong on the speaker, but appears unstable on the scope.

conr2286, 2024-10-19:
Disconnecting the audio test point connection may have improved the noise (no measurement available, but seems better).
Consider moving SI5351 and the MCP342X to from Wire to Wire2 (SDA2/SCL2) to reduce I2C noise on the SI4735 bus.

conr2286, 2024-10-23:
Disabling I2C polling of touchscreen ADC *greatly* improves reception evidenced by both the number of decoded messages and their signal strengths.  Removing the touchpanel display *may* provide a minor additional improvement (difficult to measure on-the-air --- it would need a controlled experiment to be sure).

conr2286, 2024-12-02:
Disabling the touchscreen polling in the firmware resolves the problem. The SI4735 doc asserts that its I2C port is sensitive to noise from other devices on the bus. V2.00 moves the other devices to another I2C bus, isolating the SI4735 on its own private bus.

However... it's also possible that investigation uncovered a firmware problem in which the touchscreen polling consumes too much CPU time for FT8 decoding. So... we are currently exploring a non-blocking design for the touchscreen ADC.

conr2286, 2024-12-08:
Using FW from commit 518115fa8f5eea407483691510a585ec8d56d03c checked-out to the V110 branch with the V1.10 hardware, the successful receive cannot be reproduced (i.e. old FW and old HW are not reproducing the receiver works).

conr2286, 2024-12-09:
Resolved in V2.00 hardware which isolates the SI4735 on its own I2C bus, away from noise/traffic arising for SI5351 and MCP342x.  Fixed in 3e19e267a30f87a64130a176fa1949a681c15553

Closed 2024-12-09.

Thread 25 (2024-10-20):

Traffic Manager doesn't enable/disable receiver for Tu (Tune) off/on

conr2286, 2024-10-20:
The V2 boards implement ~PTT in firmware with a second digital pin for RCV.  The traffic_manager is not always complementing PTT to the RCV pin.

conr2286, 2024-10-21:
Added code to set PIN_RCV to 0 prior to PIN_PTT to 1.  The PTT/RCV firmware should be ready for V2 boards.

Closed 2024-10-21.

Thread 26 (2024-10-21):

During modulation, the V1.10 transmitter has an intermittent -30 dB second harmonic

conr2286, 2024-10-21:
The steady-state carrier meets FCC specs (>43 dB attenuation) for all power levels.  However, during modulation, there is a momentary 2nd harmonic blip at ~-30 dB with the 5-Pole Chebyshev LP filter.  Measurements made with Rigol DSA815.

conr2286, 2024-10-21:
The problem can be resolved with either a 2nd harmonic trap or a 7-pole Chevyshev.

conr2286, 2024-12-02:
Awaiting results with V2.00 boards to see if the problem persists.  Things to consider:

- Did problem originate in SI5351 or MMIC?
- Is the SI5351 reprogrammed in correct order when switching from xmit to recv?

conr2286, 2025-01-17:
Not seen with V2 hardware and 40M 5-Pole Chebyshev LP filter

Closed 2025-01-17.

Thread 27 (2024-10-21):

Excessive resistive touchpad bounce

conr2286, 2024-10-21:
The resistive touchpad bounce causes double, triple and who-knows-how-many clicks.  So far, I've tried:

- Merely inserting delay()s following each reading
- Enabling Adafruit's sort that searches for the mean value of multiple readings.

conr2286, 2024-10-23:
This has been sufficiently improved by adding a delay() in button 0 (CQ).  Note:  the leveraged touchscreen code is not using the median value scheme.  If we have further problems, incorporating this approach may be beneficial.

conr2286, 2024-10-23:
There's still quite a bit of bounce.  It really does need a real fix such as found in the Adafruit library.

conr2286, 2024-11-27:
Disabling the touchscreen polling in the firmware resolves the problem.  The SI4735 doc asserts that its I2C port is sensitive to noise from other devices on the bus.  V2.00 moves the other devices to another I2C bus, isolating the SI4735 on its own private bus.  However... it's also possible that investigation uncovered a firmware problem in which the touchscreen polling consumes too much CPU time for FT8 decoding.  So... we are currently exploring a non-blocking design for the touchscreen ADC.

conr2286, 2024-12-02:
Workaround/fix ideas:

- Add caps from ADC inputs to ground forming LP filters
- Digital filtering
- Use a real touchscreen controller chip
- Non-blocking use of Teensy ADCs

conr2286, 2024-12-04:
Using the TouchScreenExplorer investigation tool, considerable noise was found on the floating YP signal (into the ADC).  The noise waveform is complex, but consists of narrow (~2 uS) pulses at ~50 uS intervals (observed on scope).  The noise persists even when the Adafruit touchscreen display is unplugged from the PCB.

conr2286, 2025-01-12:
The V2.00 hardware and firmware improvements significantly improved the Adafruit resistive touchscreen performance.

Closed 2025-01-12.

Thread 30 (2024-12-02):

V2.00 Board not finding SI4735

conr2286, 2024-12-02:
V2.00 PCBs isolated the SI4735 on its own I2C bus (Wire), but the I2C test isn't finding it. Wire2 is working correctly.  Considerations:

- Schematic error?
- Board doesn't implement schematic?
- Pullup resistor problem?
- Defective SI4735?
- Bus ringing?
- Program error?

Closed 2024-12-03.

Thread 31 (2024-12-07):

V2 FW/HW receiver finds no candidates

conr2286, 2024-12-07:
Not yet sure if this is a fw or a hw problem

conr2286, 2024-12-08:
Executing the V2.00 firmware (modified to set WIRE_ETC as Wire, and to disable process_touch()) found only 1 candidate out of 20 receive cycles on 7074.  The problem appears to be hardware independent.

conr2286, 2024-12-08:
V1.10 also fails to decode FT8 traffic on V1.10 hw.  But... the waterfall displayed a couple traces today on V1.10.

conr2286, 2024-12-09:
Teensy library update replaces the modified AudioStream.h file containing the Pocket FT8 requirement for a 6400 samples/second rate.

Closed 2024-12-09.

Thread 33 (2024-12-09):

Add GPS support to obtain location and UTC date/time

conr2286, 2024-12-09:
Currently, the code will try only during setup() to use a GPS on Serial1 (if available) to acquire date and time.  Not all GPS messages include the date, so it seems unreliable.

conr2286, 2024-12-12:
Resolved with dc56f2448bc7296f78b223d9db7e124687a99b99

Closed 2024-12-12.

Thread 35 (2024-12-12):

Pocket FT8 Revisited hangs on startup without the Arduino IDE running on development host

conr2286, 2024-12-12:
Hangs until the IDE is running.

conr2286, 2024-12-13:
Fixed in 128a7a657aba59c0285454ebe33777c5e212c21e

Closed 2024-12-13.

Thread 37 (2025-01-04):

CQ message slow to transmit following CQ button press

conr2286, 2025-01-04:
CQ button pressed at 13.013, receive time slot ends at 15.558.  But transmitter not engaged until 00.635, about 45 seconds later.

15:16:13.013 -> button.cpp:194 executeButton(0)
15:16:15.558 -> PocketFT8XcvrFW.ino:441 End of receive timeslot
15:16:15.591 -> decode_ft8.cpp:208 decoded:  field1='CQ DX' field2='K5CD' field3='EM10' snr=-18 Target_Locator='EM10'
15:16:16.218 -> decode_ft8.cpp:257 display_message 0 = '15:16:15 CQ DX K5CD EM10 -18' snr=-18, loc='EM10'
15:16:16.251 -> traffic_manager.cpp:213 service_CQ(), Beacon_state=0, Transmit_Armned=0
15:16:16.251 -> traffic_manager.cpp:220
15:16:16.251 -> traffic_manager.cpp:264 Exit service_CQ()) with Beacon_State=1, Transmit_Armned=0
15:16:30.601 -> PocketFT8XcvrFW.ino:441 End of receive timeslot
15:16:46.132 -> traffic_manager.cpp:213 service_CQ(), Beacon_state=1, Transmit_Armned=0
15:16:46.132 -> traffic_manager.cpp:225
15:16:46.132 -> decode_ft8.cpp:385 Check_Calling_Stations(0)
15:16:46.132 -> gen_ft8.cpp:82 set_message(0)
15:16:46.230 -> traffic_manager.cpp:264 Exit service_CQ()) with Beacon_State=2, Transmit_Armned=1
15:17:00.593 -> PocketFT8XcvrFW.ino:441 End of receive timeslot
15:17:00.635 -> traffic_manager.cpp:187 setup_to_transmit_on_next_DSP_Flag
15:17:00.635 -> traffic_manager.cpp:59 XMIT
15:17:14.117 -> PocketFT8XcvrFW.ino:427 End of transmit timeslot
15:17:14.183 -> traffic_manager.cpp:86 RECV

conr2286, 2025-02-02:
Resolved in 2e46f4d with implementation of new Sequencer

Closed 2025-02-02.

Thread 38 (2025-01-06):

Transmitted FSK sounds incorrect (too low frequency???)

conr2286, 2025-01-06:
The transmitted FSK has become (used to work fine) undecodable by wsjtx and the received audio sounds incorrect (may be too low of a frequency???).

conr2286, 2025-01-07:
WSJTX reports the V2.00 transmitted offset is 316 HZ

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

conr2286, 2025-01-07:
Another test found transmit freq at 1396 Hz

conr2286, 2025-01-08:
With rig driving a 50 ohm dummy load and K3 receiving only leakage, we are definitely not overloading the K3 where wsjtx report -11 db RSL but timing is off by 1.1 seconds.

conr2286, 2025-01-08:
With rig config'd for 925 Hz, spectral analysis finds the peak during modulation at 7.074925 mHz.  RBW=30Hz.  Modulated sig width displayed is ~200 Hz.  Reported freq is 917 Hz by wsjtx.

conr2286, 2025-01-17:
WSJTX reports the transmitted offset frequency is stable (~915 kHz) when Pocket FT8 operates from the Belkin Power Bank 20K rather than from the USB hub powered by a 3rd party USB charger that also connects Elecraft K3 and MacBook Air M2 host.  The problem appears to be ground or related in-station interference, not the Pocket FT8.

Closed 2025-01-17.

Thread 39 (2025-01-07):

WSJTX reports transmit timing is off by 0.9 Sec

conr2286, 2025-01-07:
This test conducted with GPS.  The timing report came from the DT column in WSJTX.

conr2286, 2025-01-08:
gpsHelper was not checking the age of the GPS-derived time signal.  But changing the code to require the time.age() to be less than 500 mS still leaves the wsjtx timing report off by 1.1 seconds.

conr2286, 2025-01-08:
Tightening time.age() constraint to 200 mS did not resolve issue.  wsjtx reports 1.2 seconds off.

conr2286, 2025-01-08:
Timing improves to 0.6 second following use of Sy button during audio lull in traffic on Elecraft K3.

conr2286, 2025-01-11:
Transmit timing improves to a couple hundred milliseconds as measured by wsjtx

Closed 2025-01-11.

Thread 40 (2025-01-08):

V3.00:  HW should be able to pull GPS "EN" (enable) line low

conr2286, 2025-01-08:
Pulling the line low saves power, stops serial traffic and resets communications

conr2286, 2025-04-24:
Will not do (power requirements are very modest)

Closed 2025-04-24.

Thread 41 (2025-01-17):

Broadband noise source roughly centered at ~2.5 mHz on antenna jack during receive

conr2286, 2025-01-17:
During receive, spectral analysis sampled at 50 Ohm dummy load (-40dB sample) finds a significant broadband (~500 kHz) noise source centered around 2.5 mHz.  The noise is intermittent but appears periodically (<<1 second).

Noise disappears when power is removed from Pocket FT8.

Noise continues even when Teensy 4.1 executes Blinky rather than Pocket FT8 firmware.

Noise continues even when GPS disconnected.

Noise continues even when Adafruit touch display is removed and Blinky executes (no GPS).

Noise significantly or completely reduced when USB hub unplugged from host laptop (Blinky executing).  The source appears to have something to do with the USB connection through the hub to the laptop, not from Pocket FT8.

conr2286, 2025-01-17:
Noise complete disappears when Pocket FT8 operates from Belkin 20K USB Power Bank.  Noise is definitely not a Pocket FT8 defect.

Closed 2025-01-17.

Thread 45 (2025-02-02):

Add surge protection to receiver RF input

conr2286, 2025-02-02:
This is low priority as the receiver's RF input is currently shunted to ground by a 51 Ohm resistor (R7 in V2.00 hardware).

conr2286, 2025-03-20:
It's not as bad as it sounds because the SI4735 RF input is shunted to ground by a 51 Ohm resistor

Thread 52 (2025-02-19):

Run-On CQ not terminated by timeout

conr2286, 2025-02-19:
See attached pic.

[RunOnCQ.pdf](https://github.com/user-attachments/files/18856892/RunOnCQ.pdf)

conr2286, 2025-02-19:
Resolved.  The outbound message was left even after CQ was terminated by timer.  Was just confusing as transmitter was no longer running.  Code change clears the confusing message in debugging stream.

Closed 2025-02-19.

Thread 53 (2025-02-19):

Sequencer appears to get lost while responding to remote station's CQ

conr2286, 2025-02-19:
See attached screenshot.

[SequencerLost.pdf](https://github.com/user-attachments/files/18857346/SequencerLost.pdf)

We are listening for RRR but received RSL leading to "Unexpected sequencer state"

conr2286, 2025-02-19:
timeslotEvent() lacked a case for LISTEN_RRR

Closed 2025-02-19.

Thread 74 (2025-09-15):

Firmware should build for any amateur band without a code change

conr2286, 2025-09-15:
Currently, to build the firmware for a specific band, the definitions for MINIMUM_FREQUENCY and MAXIMUM_FREQUENCY must be modified.  The firmware should look-up the band limits using the a table indexed by the CONFIG.JSON defined operating frequency.

conr2286, 2025-09-18:
Resolved with code change.  Firmware now calculates lower/upper band limits from CONFIG.JSON specified frequency

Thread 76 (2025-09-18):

GUI needs to accommodate more decoded messages than fit in the window

conr2286, 2025-09-18:
With the addition of Charley's amplifier in the audio pipeline, the receiver is decoding so many FT8 messages that they no longer fit in the received messages window.  The UI now begs for an enhancement:

- Add up/down buttons to the scroll box widget?
- Sort and display only the most important (signal strength?  distance?  dxcc?) messages
- Use a smaller font?
- The window can probably be expanded by at least one or two lines

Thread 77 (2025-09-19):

UTC time not restored from RTC

conr2286, 2025-09-19:
The Teensy loader initializes the MCU time to the host computer's local time.  When the executing firmware obtains a GPS fix, it successfully begins using UTC date/time and is supposed to record the UTC time in the RTC.  However, when the MCU reboots (without loading new firmware), the displayed time is incorrect (it should have been restored from the RTC).  Something in here is fouled up beyond all recognition.  :(

Closed 2025-09-20.

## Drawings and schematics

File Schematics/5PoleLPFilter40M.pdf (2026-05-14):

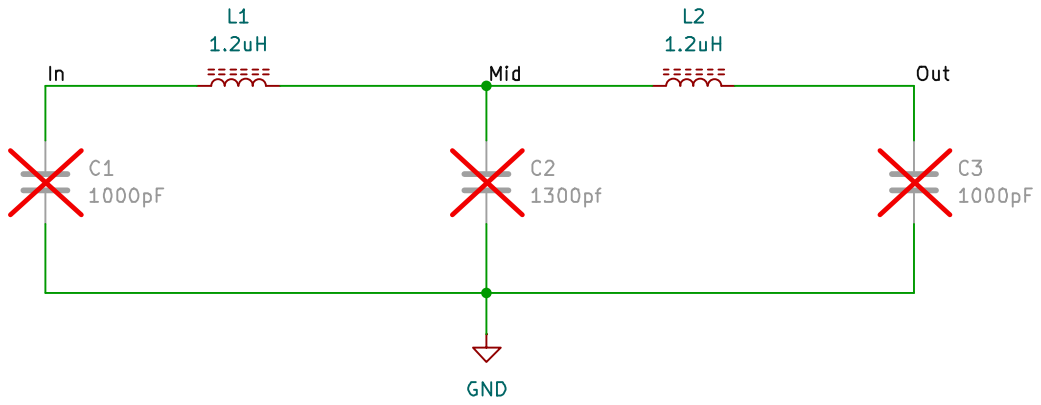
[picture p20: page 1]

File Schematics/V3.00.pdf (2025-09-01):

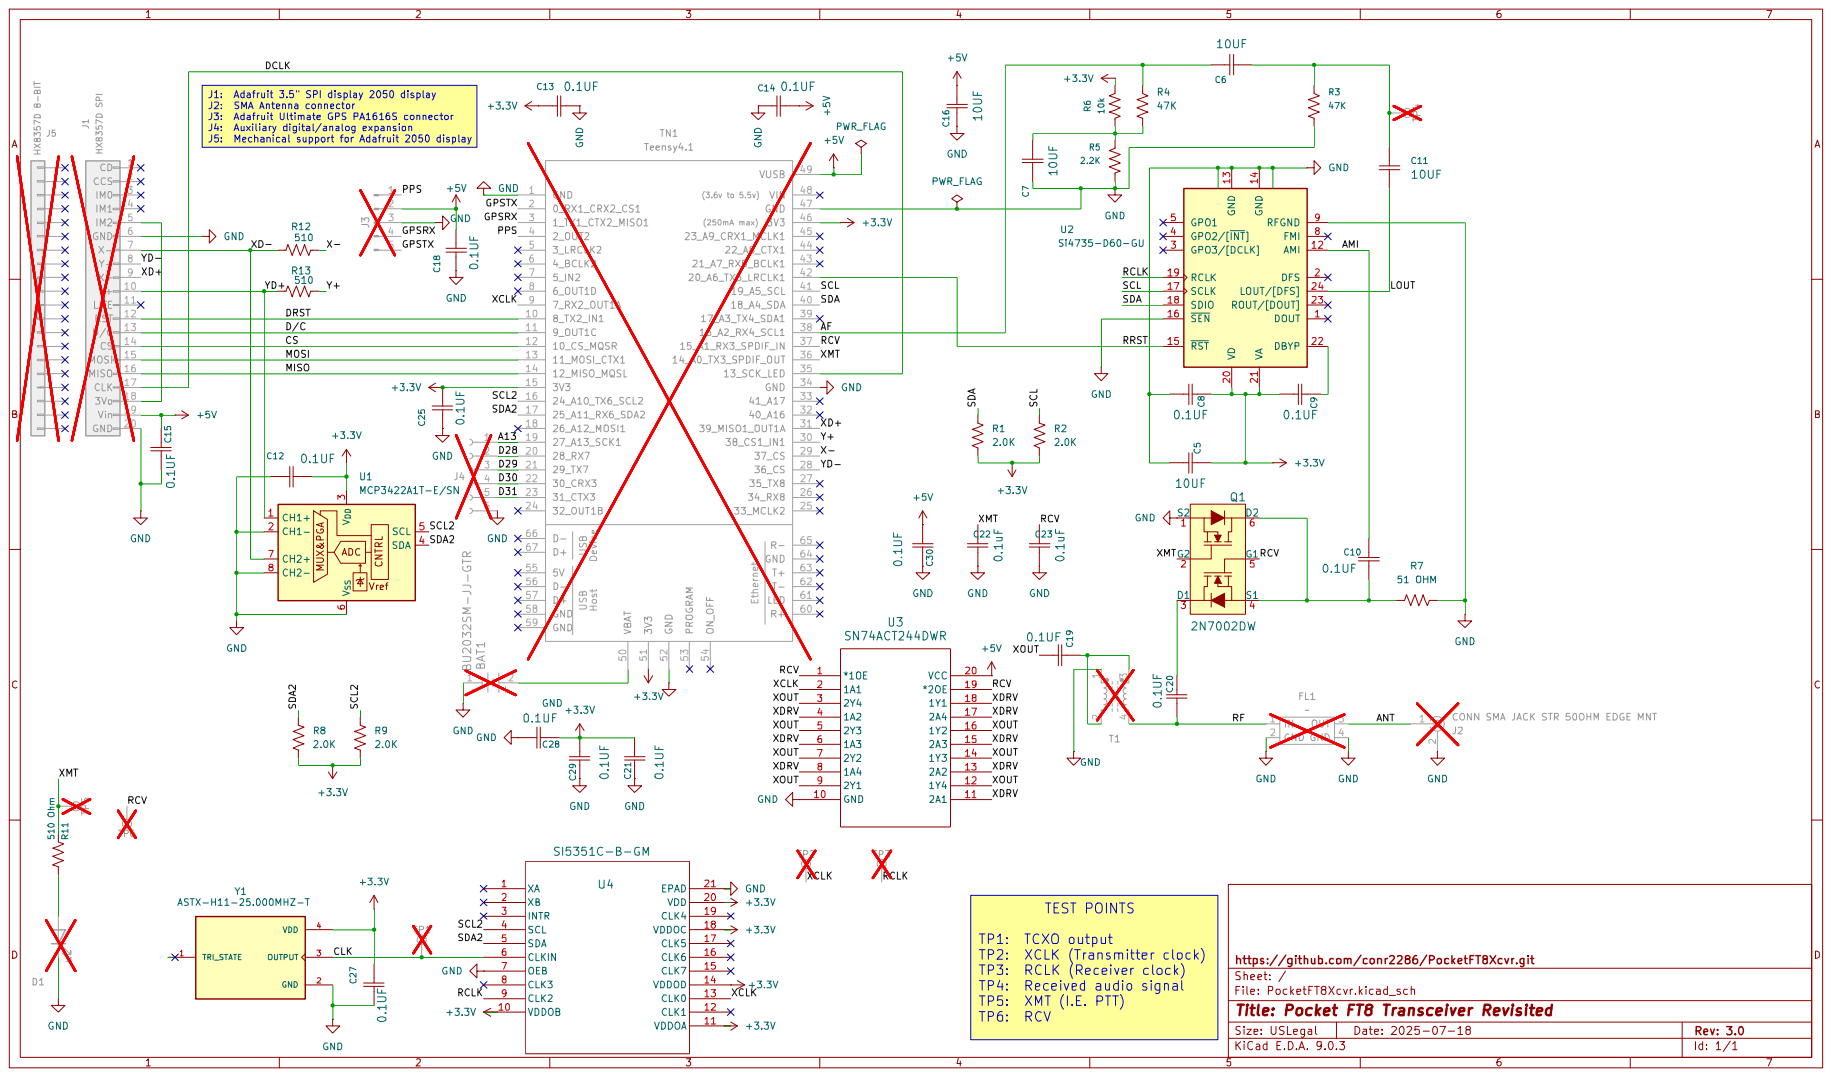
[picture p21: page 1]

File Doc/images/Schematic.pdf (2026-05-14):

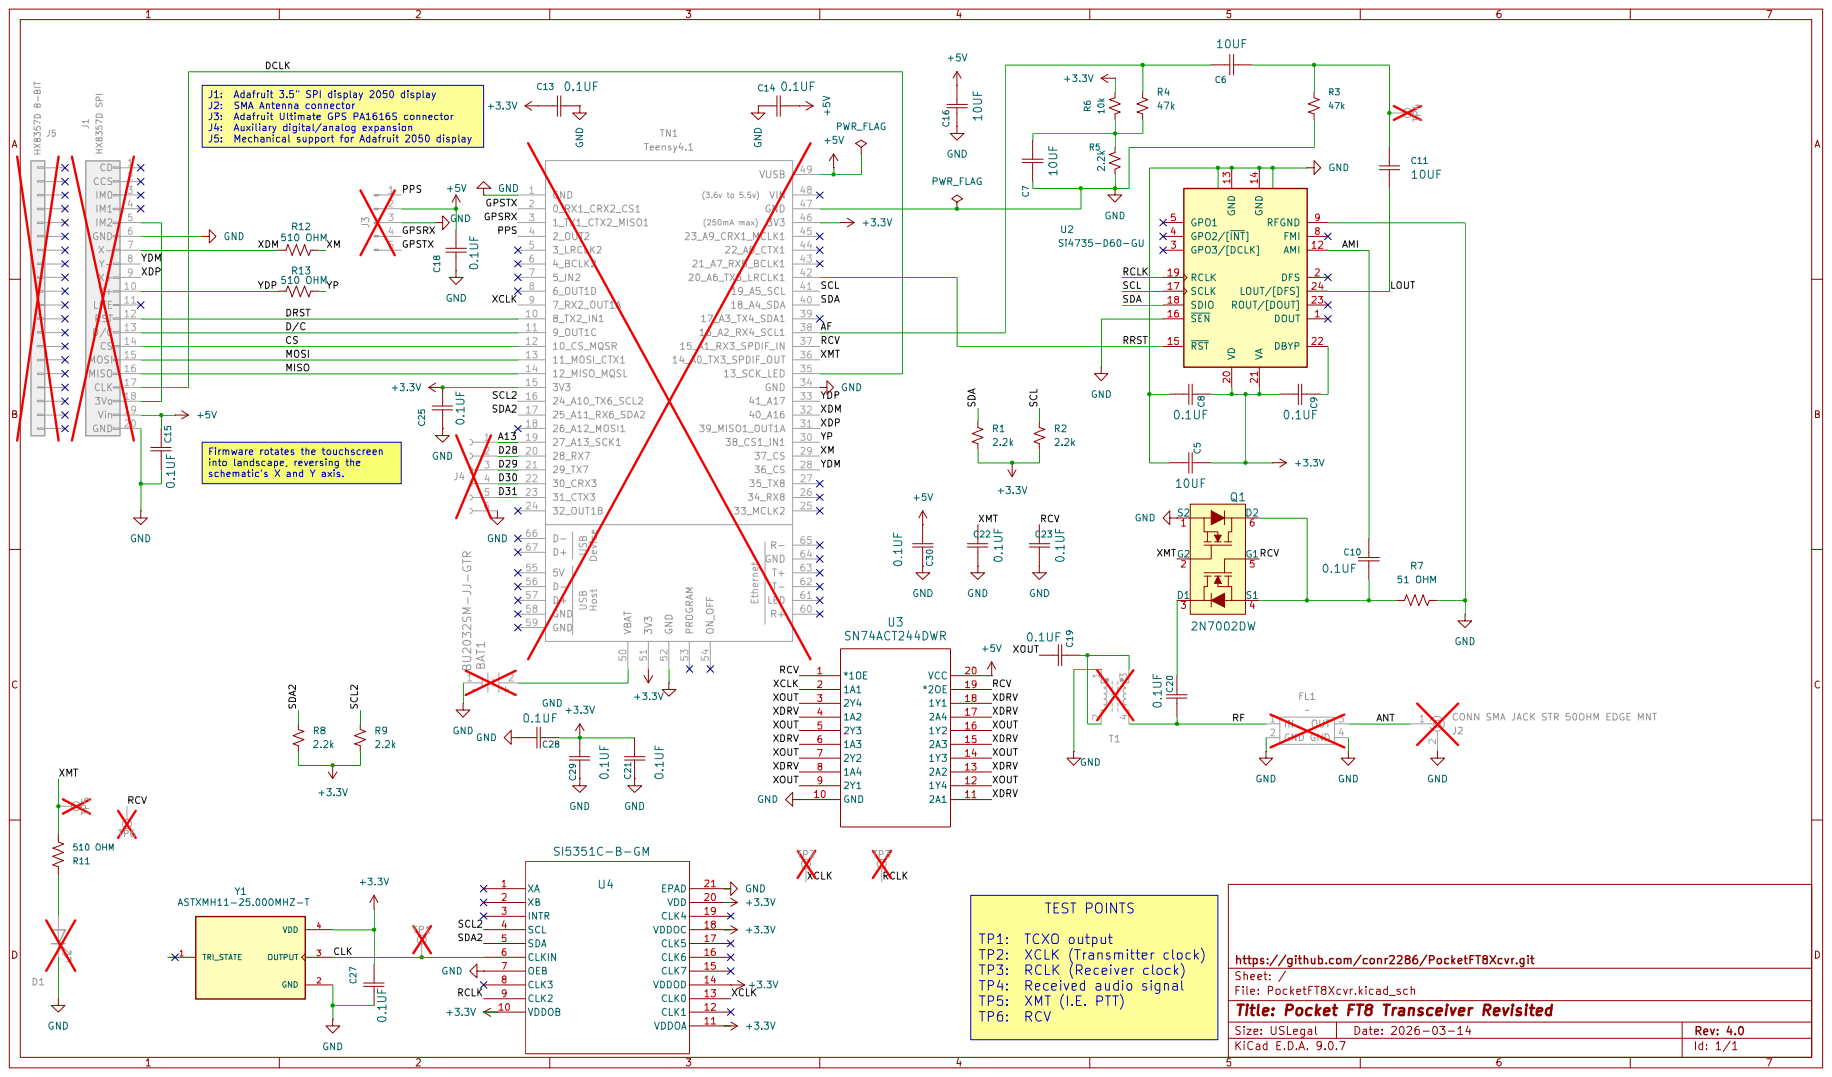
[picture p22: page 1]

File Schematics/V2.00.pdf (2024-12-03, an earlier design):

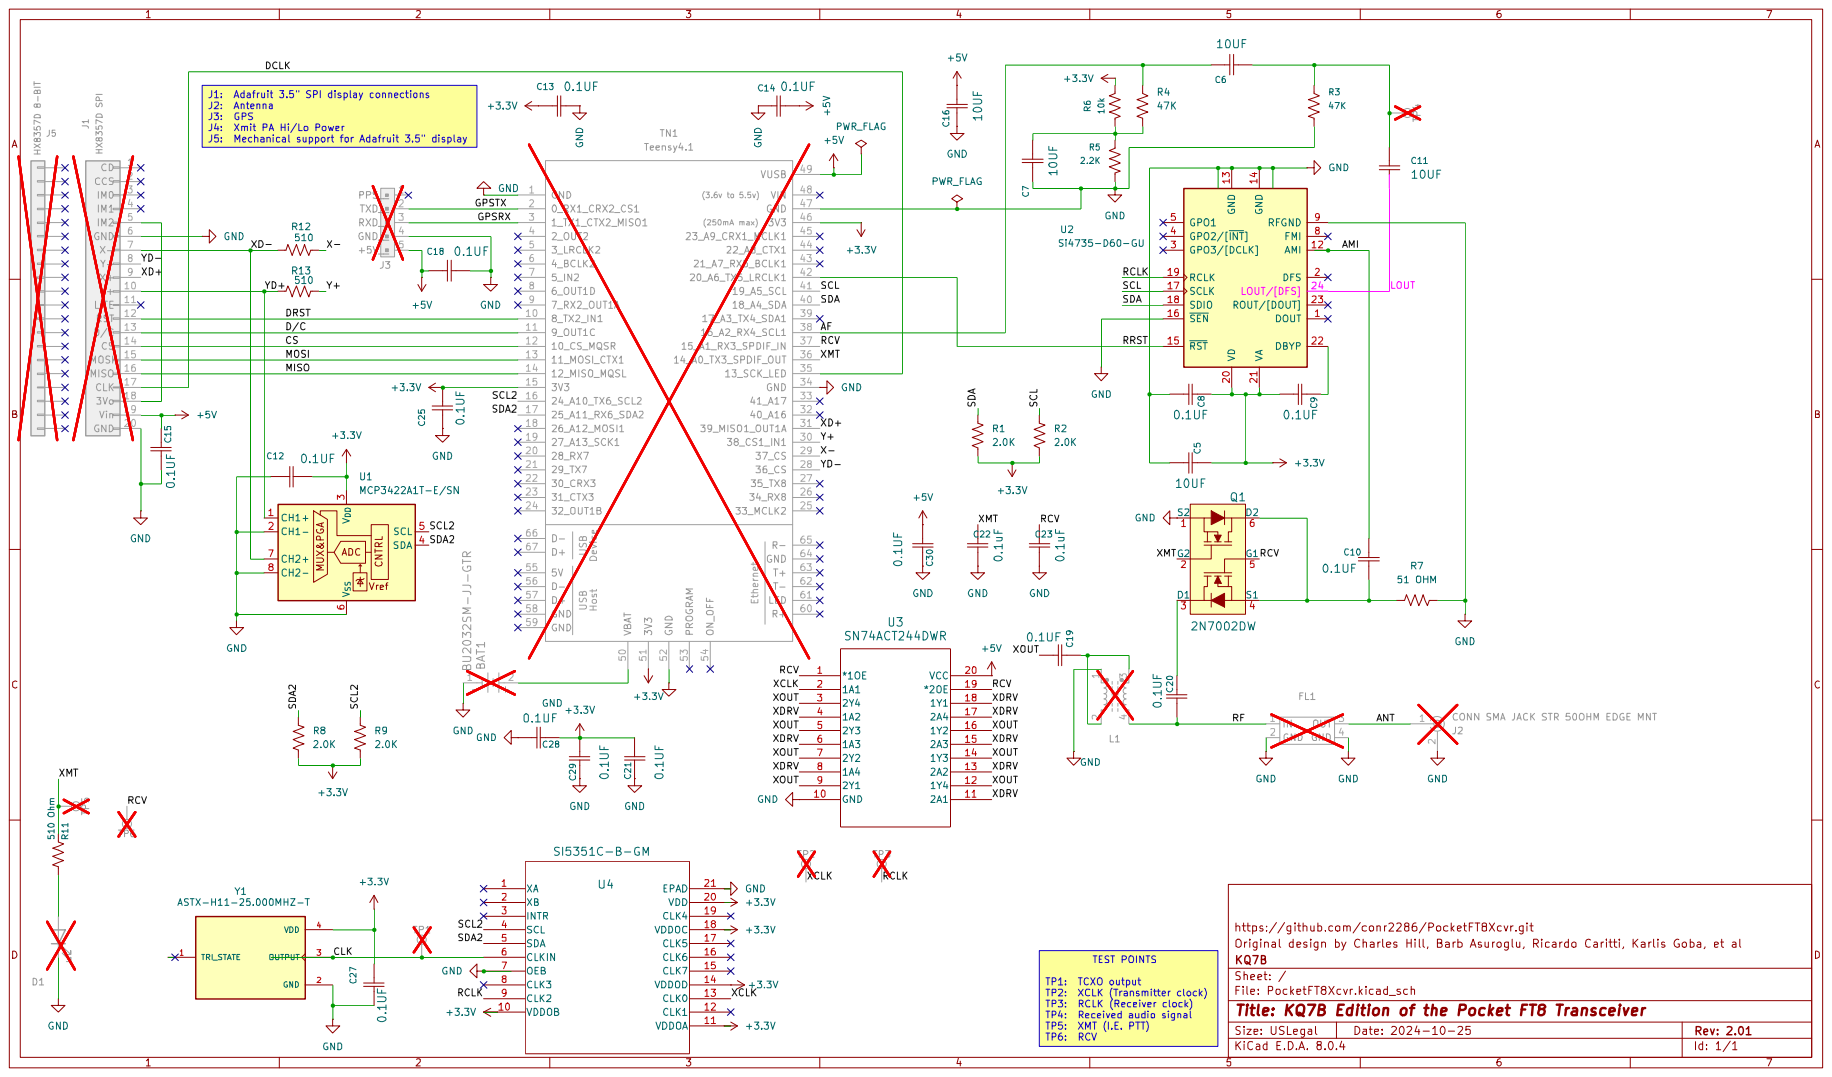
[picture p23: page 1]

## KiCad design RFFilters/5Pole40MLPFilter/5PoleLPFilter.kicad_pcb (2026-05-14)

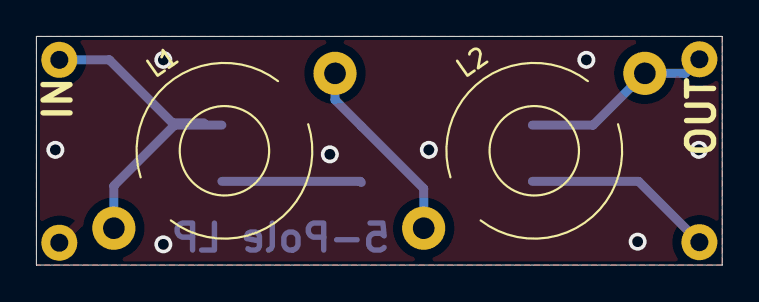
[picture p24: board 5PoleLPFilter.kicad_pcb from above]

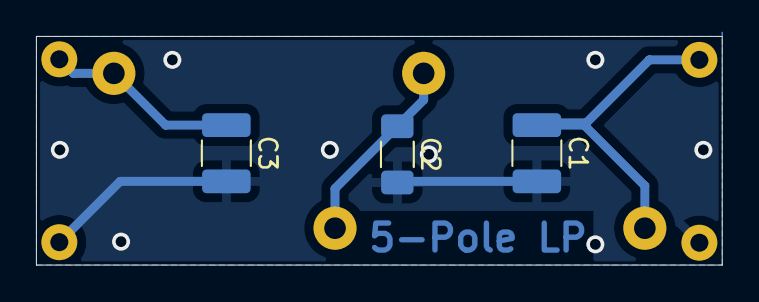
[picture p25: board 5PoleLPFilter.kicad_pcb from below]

Board: 2 copper layers, 38.1 x 12.7 mm, 6 parts (3 on the bottom side), 2 nets.

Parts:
C1, C3: 1000pF; C_1210_3225Metric_Pad1.33x2.70mm_HandSolder
C2: 1300pf; C_1206_3216Metric_Pad1.33x1.80mm_HandSolder
J1: FilterConn02
L1, L2: 1.2uH; L_Toroid_Horizontal_D9.5mm_P15.00mm_Diameter10-5mm_Amidon-T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

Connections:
/Mid: C2.1, L1.2, L2.1
GND: C1.2, C2.2, C3.2, J1.2

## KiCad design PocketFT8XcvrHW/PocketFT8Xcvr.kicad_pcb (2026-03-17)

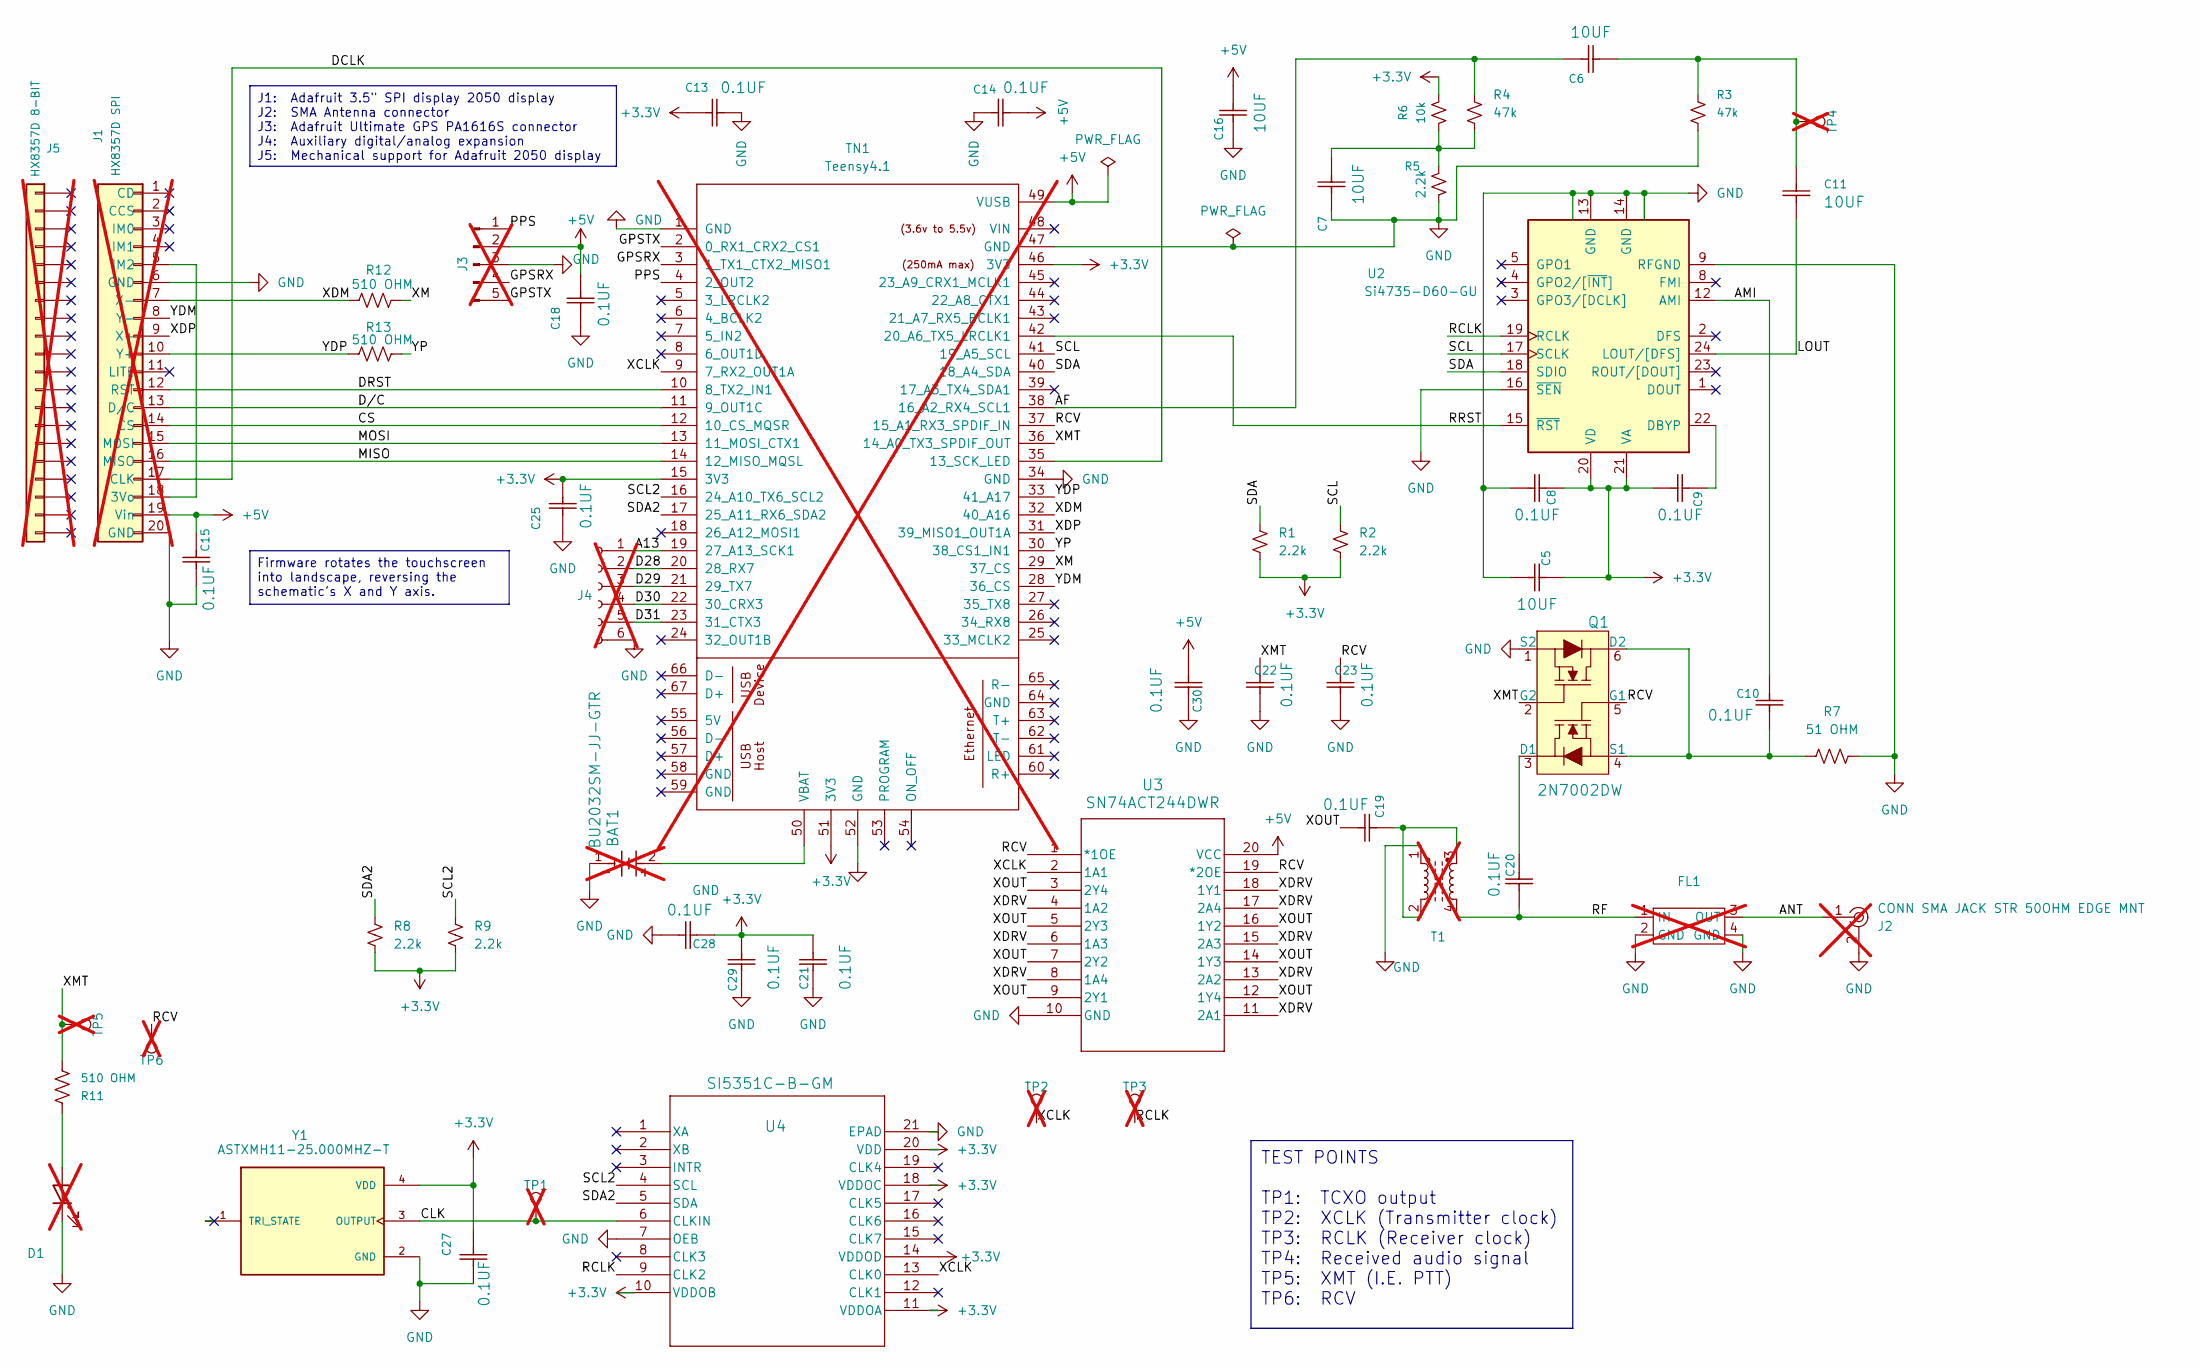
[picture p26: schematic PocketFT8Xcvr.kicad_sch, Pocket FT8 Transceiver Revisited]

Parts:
BAT1: BU2032SM-JJ-GTR; BU2032SM-JJ-GTR_MPD; Mfg Part # BU2032SM-JJ-GTR; not fitted
C5: 10UF; C_0805_2012Metric; Voltage 16V; Tolerance 10%; Mfg Part # C0805C106K4PAC7800
C6, C7, C11, C16: 10UF; C_0805_2012Metric; Voltage 6.3V; Tolerance 20%; Mfg Part # C0805C106K4PAC7800
C8, C9, C10, C13, C14, C15, C18, C19, C20, C21, C22, C23, C25, C27, C28, C29, C30: 0.1UF; C_0603_1608Metric; Voltage 16V; Tolerance 10%; Mfg Part # C0603C104K4RACTU
D1: XMIT; LED_D5.0mm; not fitted
FL1: PluginFilter; not fitted
J1: HX8357D SPI; PinHeader_1x20_P2.54mm_Vertical; not fitted
J2: CONN SMA JACK STR 50OHM EDGE MNT; RF_SMA_BoardEdge_142-0701-801; MPN 732511153; Digi-Key_PN J502-ND; not fitted
J3: B5B-XH-A_LF__SN_; PinHeader_1x5_P2.5mm_Drill1.1mm; MPN B5B-XH-A(LF)(SN); Digi-Key_PN 455-2270-ND; not fitted
J4: Conn_01x06_Socket; 1x06; not fitted
J5: HX8357D 8-BIT; PinHeader_1x20_P2.54mm_Vertical; not fitted
Q1: 2N7002DW; SOT-363; Mfg Part # 2N7002DW; Digi-Key_PN 2N7002DWCT-ND
R1, R2, R5, R8, R9: 2.2k; R_0603_1608Metric; Mfg Part # RC0603JR-132K2L
R3, R4: 47k; R_0603_1608Metric; Mfg Part # RC0603JR-0747KL; LCSC Part # C127447
R6: 10k; R_0603_1608Metric; Mfg Part # AF0603JR-0710KL; LCSC Part # C99198
R7: 51 OHM; R_0603_1608Metric; Mfg Part # RC0603JR-0751RL
R11, R12, R13: 510 OHM; R_0603_1608Metric; MFG PART # RC0603JR-07510RL
T1: L_Ferrite_Coupled; L_Toroid_Vertical_BIFILAR; not fitted
TN1: Teensy4.1; Teensy41; not fitted
TP1, TP2, TP3, TP4, TP5, TP6: PTH; 1x01; not fitted
U2: Si4735-D60-GU; SSOP-24_3.9x8.7mm_P0.635mm; Mfg Part # SI4735-D60-GU
U3: SN74ACT244DWR; DW20; Mfg Part # SN74ACT244DWR
U4: SI5351C-B-GM; QFN20_4X4_SKY; Mfg Part # SI5351C-B-GM
Y1: ASTXMH11-25.000MHZ-T; XTAL_ASTX-H11-25.000MHZ-T; PARTREV 05.13.15

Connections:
+3.3V: C5.2, C8.2, C9.1, C13.1, C21.2, C25.1, C27.2, C28.1, C29.2, R1.1, R2.1, R6.1, R8.1, R9.1, TN1.15 (3V3), TN1.46 (3V3), TN1.51 (3V3), U2.20 (VD), U2.21 (VA), U4.10 (VDDOB), U4.11 (VDDOA), U4.14 (VDDOD), U4.18 (VDDOC), U4.20 (VDD), Y1.4 (VDD)
+5V: C14.2, C15.2, C16.2, C18.2, C30.2, J1.19 (Vin), J3.2, TN1.49 (VUSB), U3.20 (VCC)
/A13: J4.1, TN1.19 (27_A13_SCK1)
/AF: C6.2, R4.1, TN1.38 (16_A2_RX4_SCL1)
/AMI: C10.2, U2.12 (AMI)
/ANT: FL1.3 (OUT), J2.1
/CLK: TP1.1, U4.6 (CLKIN), Y1.3 (OUTPUT)
/CS: J1.14 (CS), TN1.12 (10_CS_MQSR)
/D28: J4.2, TN1.20 (28_RX7)
/D29: J4.3, TN1.21 (29_TX7)
/D30: J4.4, TN1.22 (30_CRX3)
/D31: J4.5, TN1.23 (31_CTX3)
/DCLK: J1.17 (CLK), TN1.35 (13_SCK_LED)
/DRST: J1.12 (RST), TN1.10 (8_TX2_IN1)
/D/C: J1.13 (D/C), TN1.11 (9_OUT1C)
/GPSRX: J3.4, TN1.3 (1_TX1_CTX2_MISO1)
/GPSTX: J3.5, TN1.2 (0_RX1_CRX2_CS1)
/LOUT: C11.1, U2.24 (LOUT/[DFS])
/MISO: J1.16 (MISO), TN1.14 (12_MISO_MQSL)
/MOSI: J1.15 (MOSI), TN1.13 (11_MOSI_CTX1)
/PPS: J3.1, TN1.4 (2_OUT2)
/RCLK: TP3.1, U2.19 (RCLK), U4.9 (CLK2)
/RCV: C23.2, Q1.5 (G1), TN1.37 (15_A1_RX3_SPDIF_IN), TP6.1, U3.1 (*1OE), U3.19 (*2OE)
/RF: C20.2, FL1.1 (IN), T1.4
/RRST: TN1.42 (20_A6_TX5_LRCLK1), U2.15 (~RST)
/SCL: R2.2, TN1.41 (19_A5_SCL), U2.17 (SCLK)
/SCL2: R9.2, TN1.16 (24_A10_TX6_SCL2), U4.4 (SCL)
/SDA: R1.2, TN1.40 (18_A4_SDA), U2.18 (SDIO)
/SDA2: R8.2, TN1.17 (25_A11_RX6_SDA2), U4.5 (SDA)
/XCLK: TN1.9 (7_RX2_OUT1A), TP2.1, U3.2 (1A1), U4.13 (CLK0)
/XDM: J1.7 (X-), R12.1, TN1.32 (40_A16)
/XDP: J1.9 (X+), TN1.31 (39_MISO1_OUT1A)
/XDRV: U3.4 (1A2), U3.6 (1A3), U3.8 (1A4), U3.11 (2A1), U3.13 (2A2), U3.15 (2A3), U3.17 (2A4), U3.18 (1Y1)
/XM: R12.2, TN1.29 (37_CS)
/XMT: C22.2, Q1.2 (G2), R11.2, TN1.36 (14_A0_TX3_SPDIF_OUT), TP5.1
/XOUT: C19.1, U3.3 (2Y4), U3.5 (2Y3), U3.7 (2Y2), U3.9 (2Y1), U3.12 (1Y4), U3.14 (1Y3), U3.16 (1Y2)
/YDM: J1.8 (Y-), TN1.28 (36_CS)
/YDP: J1.10 (Y+), R13.1, TN1.33 (41_A17)
/YP: R13.2, TN1.30 (38_CS1_IN1)
GND: BAT1.1, C5.1, C7.1, C8.1, C13.2, C14.1, C15.1, C16.1, C18.1, C21.1, C22.1, C23.1, C25.2, C27.1, C28.2, C29.1, C30.1, D1.1 (K), FL1.2 (GND), FL1.4 (GND), J1.6 (GND), J1.20 (GND), J2.2, J3.3, J4.6, Q1.1 (S2), R3.2, R5.2, R7.1, T1.1, TN1.1 (GND), TN1.34 (GND), TN1.47 (GND), TN1.52 (GND), U2.9 (RFGND), U2.10 (NC), U2.11 (NC), U2.13 (GND), U2.14 (GND), U2.16 (~SEN), U3.10 (GND), U4.7 (OEB), U4.21 (EPAD), Y1.2 (GND)
unnamed: C7.2, R4.2, R5.1, R6.2
unnamed: C6.1, C11.2, R3.1, TP4.1
unnamed: C19.2, T1.2, T1.3
unnamed: D1.2 (A), R11.1
unnamed: J1.5 (IM2), J1.18 (3Vo)
unnamed: C20.1, Q1.3 (D1)
unnamed: C10.1, Q1.4 (S1), Q1.6 (D2), R7.2
unnamed: BAT1.2, TN1.50 (VBAT)
unnamed: C9.2, U2.22 (DBYP)

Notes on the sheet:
TEST POINTS TP1: TCXO output TP2: XCLK (Transmitter clock) TP3: RCLK (Receiver clock) TP4: Received audio signal TP5: XMT (I.E. PTT) TP6: RCV
Firmware rotates the touchscreen into landscape, reversing the schematic's X and Y axis.
J1: Adafruit 3.5" SPI display 2050 display J2: SMA Antenna connector J3: Adafruit Ultimate GPS PA1616S connector J4: Auxiliary digital/analog expansion J5: Mechanical support for Adafruit 2050 display

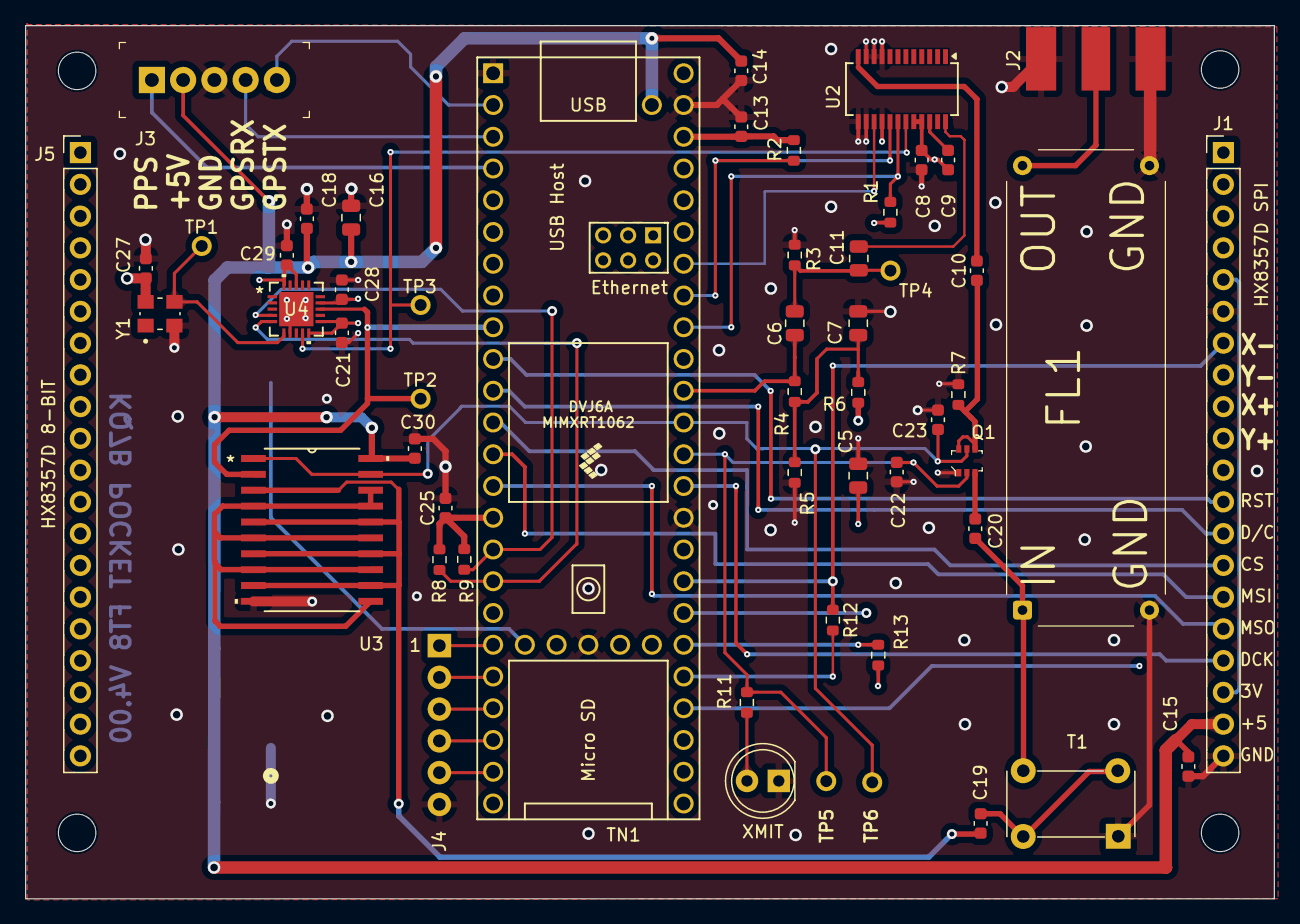
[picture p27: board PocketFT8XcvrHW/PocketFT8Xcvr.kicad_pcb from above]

Board: 4 copper layers, 99.9 x 69.9 mm, 55 parts (1 on the bottom side), 49 nets.

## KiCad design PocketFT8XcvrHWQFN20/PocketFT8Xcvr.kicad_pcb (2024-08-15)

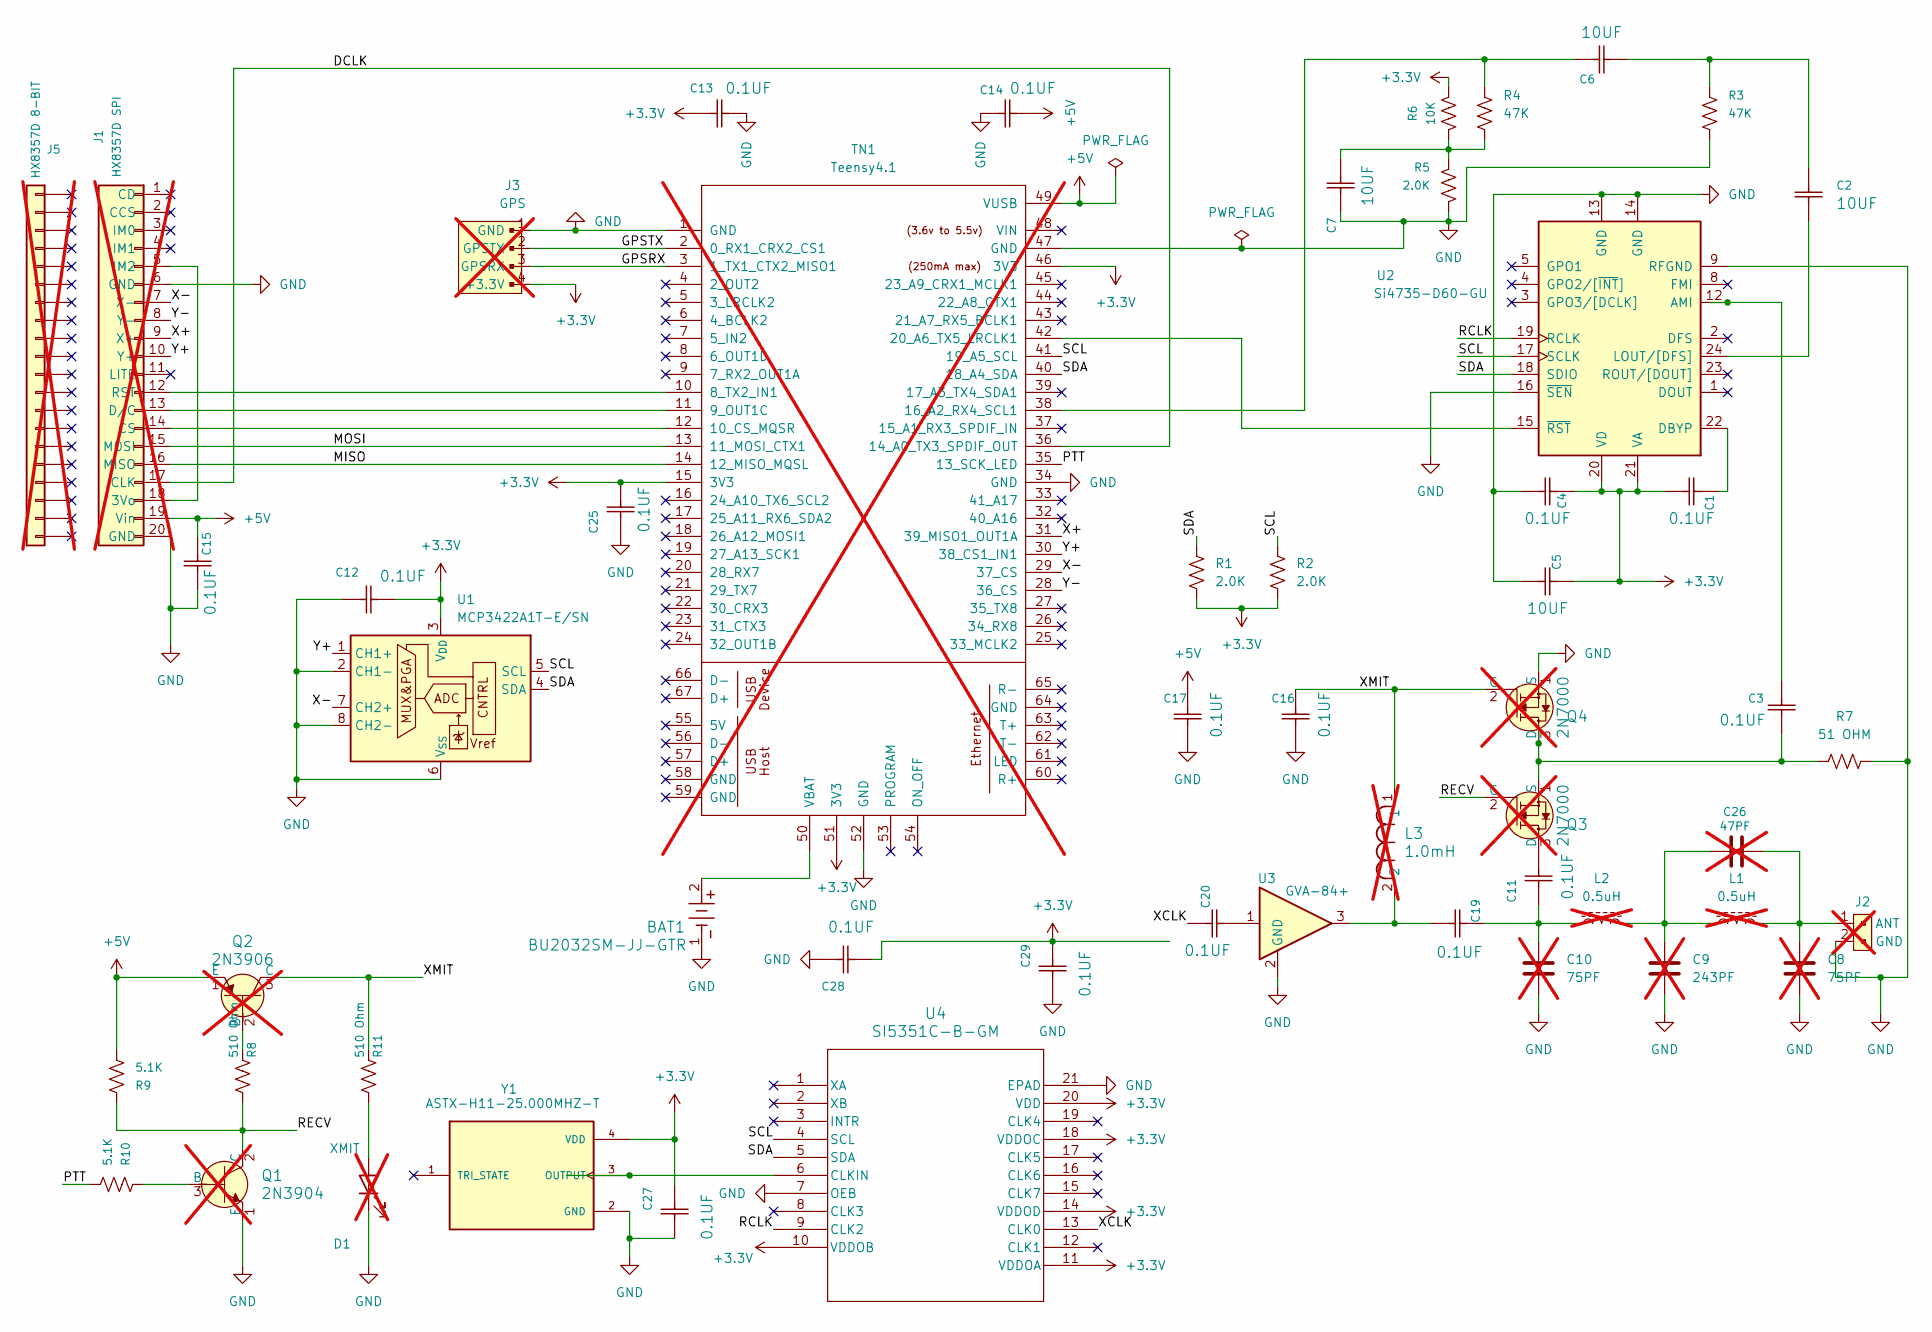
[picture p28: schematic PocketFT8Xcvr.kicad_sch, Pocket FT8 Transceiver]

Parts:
BAT1: BU2032SM-JJ-GTR; BU2032SM-JJ-GTR_MPD; Mfg Part # BU2032SM-JJ-GTR
C1, C3, C4, C11, C12, C13, C14, C15, C16, C17, C19, C20, C25, C27, C28, C29: 0.1UF; C_0603_1608Metric; Voltage 16V; Tolerance 10%; Mfg Part # C0603C104K4RAC7867
C2, C6, C7: 10UF; C_0805_2012Metric; Voltage 6.3V; Tolerance 20%; Mfg Part # C0805C106K4PAC7800
C5: 10UF; C_0805_2012Metric; Voltage 16V; Tolerance 10%; Mfg Part # C0805C106K4PAC7800
C8, C10: 75PF; C_0805_2012Metric; not fitted
C9: 243PF; C_0805_2012Metric; not fitted
C26: 47PF; C_0805_2012Metric; Voltage 100v; Tolerance 1%; not fitted
D1: XMIT; LED_D5.0mm; not fitted
J1: HX8357D SPI; PinHeader_1x20_P2.54mm_Vertical; not fitted
J2: 22-23-2021; PinHeader_1x2_P2.54mm_Drill1.02mm; MPN 22-23-2021; Digi-Key_PN WM4200-ND; not fitted
J3: GPS; PinHeader_1x4_P2.54mm_Drill1.02mm; MPN 0022232041; Digi-Key_PN WM4202-ND; not fitted
J5: HX8357D 8-BIT; PinHeader_1x20_P2.54mm_Vertical; not fitted
L1, L2: 0.5uH; L_Toroid_Vertical_L10.0mm_W5.0mm_P5.08mm; not fitted
L3: 1.0mH; IND_BOURNS_RLB9012; Mfg Part # RLB9012-102KL; Digi-Key_PN RLB9012-102KL-N; not fitted
Q1: 2N3904; TO-92-3; Mfg Part # 2N3904; Digi-Key_PN 2N3904CS-ND; not fitted
Q2: 2N3906; TO-92-3; Mfg Part # 2N3906; Digi-Key_PN 2N3906CS-ND; not fitted
Q3: 2N7000; TO-92-3; Mfg Part # 2N7000; Digi-Key_PN 2N7000FS-ND; not fitted
Q4: 2N7000; TO-92-3; MPN 2N7000; Digi-Key_PN 2N7000FS-ND; not fitted
R1, R2, R5: 2.0K; R_0603_1608Metric; Mfg Part # RC0603JR-072KL
R3, R4: 47K; R_0603_1608Metric; Mfg Part # RC0603JR-0747KL
R6: 10K; R_0603_1608Metric; Mfg Part # RC0603JR-0710KL
R7: 51 OHM; R_0603_1608Metric; Mfg Part # RC1210JR-0751RL
R8, R11: 510 Ohm; R_0603_1608Metric; Mfg Part # RC0603JR-07510RL
R9, R10: 5.1K; R_0603_1608Metric; Mfg Part # RC0603JR-075K1L
TN1: Teensy4.1; Teensy41; not fitted
U1: MCP3422A1T-E/SN; SOIC-8_3.9x4.9mm_P1.27mm; Mfg Part # MCP3422A1T-E/SN
U2: Si4735-D60-GU; SSOP-24_3.9x8.7mm_P0.635mm; Mfg Part # SI4735-D60-GU
U3: GVA-84+; SOT-89-3_Handsoldering; Mfg Part # GVA-84+
U4: SI5351C-B-GM; QFN20_4X4_SKY; Mfg Part # SI5351C-B-GM
Y1: ASTX-H11-25.000MHZ-T; XTAL_ASTX-H11-25.000MHZ-T; PARTREV 05.13.15

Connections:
+3.3V: C1.1, C4.2, C5.2, C12.1, C13.1, C25.1, C27.2, C28.1, C29.2, J3.4 (+3.3V), R1.2, R2.2, R6.2, TN1.15 (3V3), TN1.46 (3V3), TN1.51 (3V3), U1.3 (V_{DD}), U2.20 (VD), U2.21 (VA), U4.10 (VDDOB), U4.11 (VDDOA), U4.14 (VDDOD), U4.18 (VDDOC), U4.20 (VDD), Y1.4 (VDD)
+5V: C14.2, C15.2, C17.2, J1.19 (Vin), Q2.1 (E), R9.2, TN1.49 (VUSB)
/DCLK: J1.17 (CLK), TN1.36 (14_A0_TX3_SPDIF_OUT)
/GPSRX: J3.3 (GPSRX), TN1.3 (1_TX1_CTX2_MISO1)
/GPSTX: J3.2 (GPSTX), TN1.2 (0_RX1_CRX2_CS1)
/MISO: J1.16 (MISO), TN1.14 (12_MISO_MQSL)
/MOSI: J1.15 (MOSI), TN1.13 (11_MOSI_CTX1)
/PTT: R10.2, TN1.35 (13_SCK_LED)
/RCLK: U2.19 (RCLK), U4.9 (CLK2)
/RECV: Q1.2 (C), Q3.2 (G), R8.2, R9.1
/SCL: R2.1, TN1.41 (19_A5_SCL), U1.5 (SCL), U2.17 (SCLK), U4.4 (SCL)
/SDA: R1.1, TN1.40 (18_A4_SDA), U1.4 (SDA), U2.18 (SDIO), U4.5 (SDA)
/X+: J1.9 (X+), TN1.31 (39_MISO1_OUT1A)
/X-: J1.7 (X-), TN1.29 (37_CS), U1.7 (CH2+)
/XCLK: C20.1, U4.13 (CLK0)
/XMIT: C16.2, L3.1, Q2.3 (C), Q4.2 (G), R11.1
/Y+: J1.10 (Y+), TN1.30 (38_CS1_IN1), U1.1 (CH1+)
/Y-: J1.8 (Y-), TN1.28 (36_CS)
GND: BAT1.1, C4.1, C5.1, C7.1, C8.2, C9.2, C10.2, C12.2, C13.2, C14.1, C15.1, C16.1, C17.1, C25.2, C27.1, C28.2, C29.1, D1.1 (K), J1.6 (GND), J1.20 (GND), J2.2 (GND), J3.1 (GND), Q1.1 (E), Q4.1 (S), R3.1, R5.1, R7.1, TN1.1 (GND), TN1.34 (GND), TN1.47 (GND), TN1.52 (GND), U1.2 (CH1-), U1.6 (V_{SS}), U1.8 (CH2-), U2.9 (RFGND), U2.13 (GND), U2.14 (GND), U2.16 (~SEN), U3.2 (GND), U4.7 (OEB), U4.21 (EPAD), Y1.2 (GND)
unnamed: C2.2, C6.1, R3.2
unnamed: C7.2, R4.1, R5.2, R6.1
unnamed: C10.1, C11.2, C19.2, L2.1
unnamed: C19.1, L3.2, U3.3
unnamed: C20.2, U3.1
unnamed: C9.1, C26.1, L1.1, L2.2
unnamed: D1.2 (A), R11.2
unnamed: J1.5 (IM2), J1.18 (3Vo)
unnamed: J1.14 (CS), TN1.12 (10_CS_MQSR)
unnamed: J1.13 (D/C), TN1.11 (9_OUT1C)
unnamed: J1.12 (RST), TN1.10 (8_TX2_IN1)
unnamed: C8.1, C26.2, J2.1 (ANT), L1.2
unnamed: Q1.3 (B), R10.1
unnamed: Q2.2 (B), R8.1
unnamed: C11.1, Q3.3 (D)
unnamed: C3.1, Q3.1 (S), Q4.3 (D), R7.2
unnamed: C6.2, R4.2, TN1.38 (16_A2_RX4_SCL1)
unnamed: TN1.42 (20_A6_TX5_LRCLK1), U2.15 (~RST)
unnamed: BAT1.2, TN1.50 (VBAT)
unnamed: C3.2, U2.12 (AMI)
unnamed: C1.2, U2.22 (DBYP)
unnamed: C2.1, U2.24 (LOUT/[DFS])
unnamed: U4.6 (CLKIN), Y1.3 (OUTPUT)

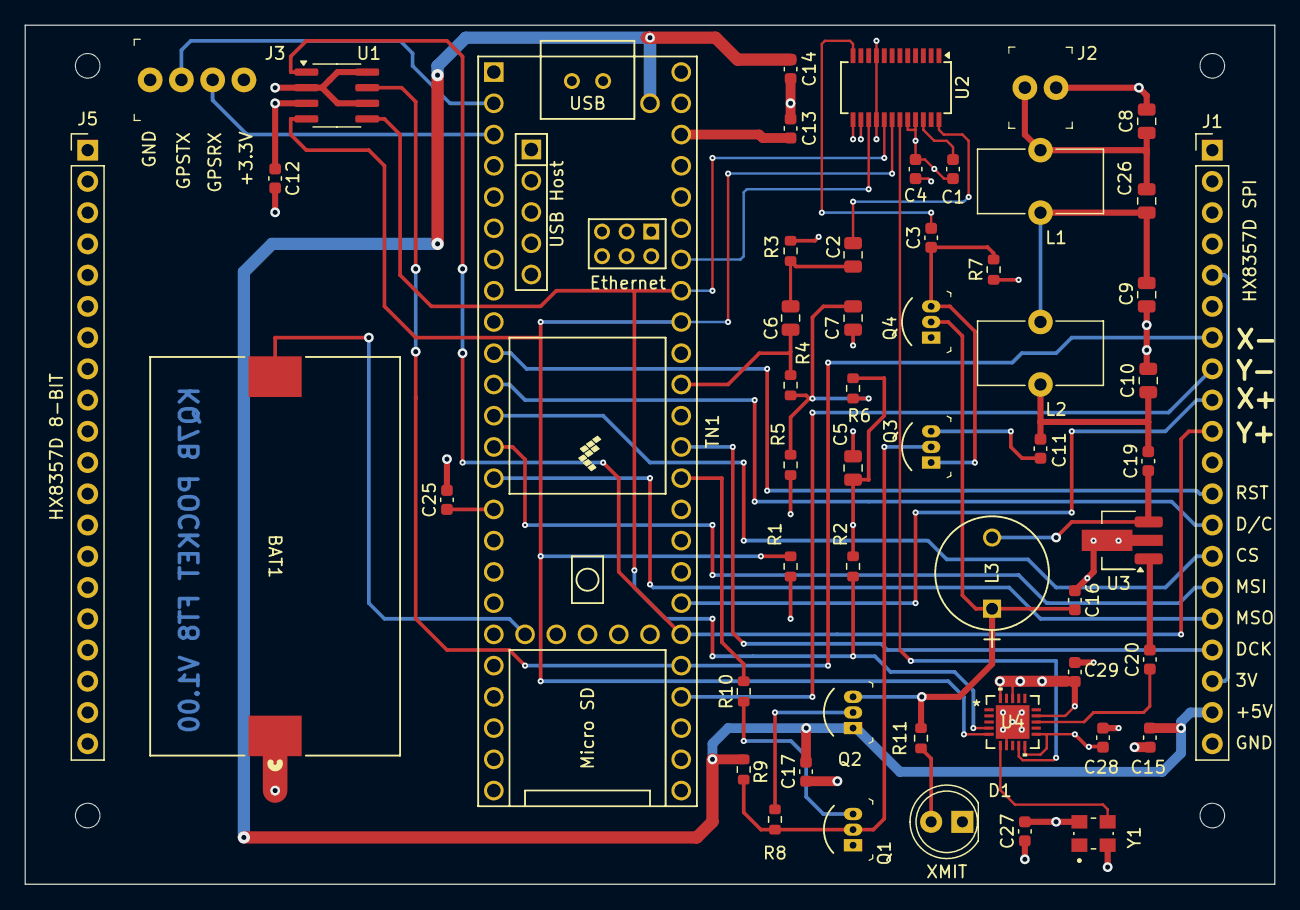
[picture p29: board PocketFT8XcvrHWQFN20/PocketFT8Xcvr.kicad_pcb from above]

Board: 4 copper layers, 101.6 x 69.9 mm, 54 parts (0 on the bottom side), 42 nets.

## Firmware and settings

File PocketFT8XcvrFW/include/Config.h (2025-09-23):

#pragma once
#include <Arduino.h>

// Configuration parameters read from SD file
#define CONFIG_FILENAME "/CONFIG.JSON"

// Configuration data struct.  TODO:  Perhaps should be a class???
typedef struct Config {
    char callsign[12];                     // 11 chars and NUL
    char locator[5];                       // 4 char maidenhead locator and NUL
    unsigned lowerFrequencyLimit;          // Band's lower limit
    unsigned operatingFrequency;           // Operating operatingFrequency in kHz
    unsigned upperFrequencyLimit;          // Band's upper limit
    long tcxoCorrection;                   // HZ correction factor used by Si5351
    unsigned long audioRecordingDuration;  // Seconds or 0 to disable audio recording
    unsigned enableAVC;                    // 0=disable, 1=enable SI47xx AVC
    unsigned gpsTimeout;                   // GPS timeout (seconds) to obtain a fix
    unsigned qsoTimeout;                   // QSO timeout (seconds) to obtain a response
    bool enableDuplicates;                 // Enable RoboOp to contact duplicates
    char logFilename[24];                  // Log filename
    char myName[16];                       // Operator's personal name, not callsign
    char m0[14];                           // Free Text Message 0 and NUL
    char m1[14];                           // Free Text Message 1 and NUL
    char m2[14];                           // Free Text Message 2 and NUL
    char my_sota_ref[12];                  // My station's SOTA Reference
} ConfigType;

// Default configuration
#define MINIMUM_FREQUENCY 14000               // Min freq supported by HW filters
#define MAXIMUM_FREQUENCY 14350               // Max freq supported by HW filters
#define DEFAULT_FREQUENCY 14074               // kHz
#define DEFAULT_TCXO_CORRECTION 0             // Hz
#define DEFAULT_CALLSIGN ""                   // There's no realistic default callsign
#define DEFAULT_AUDIO_RECORDING_DURATION 0UL  // Default of 0 seconds disables audio recording
#define DEFAULT_ENABLE_AVC 1                  // SI4735 AVC enabled by default
#define DEFAULT_GPS_TIMEOUT 60                // Number of seconds before GPS fix time-out
#define DEFAULT_QSO_TIMEOUT 180               // Number seconds Sequencer will retry transmission without a response
#define DEFAULT_ENABLE_DUPLICATES false       // RoboOp will not contact duplicates
#define DEFAULT_LOG_FILENAME "LOGFILE.ADIF"   // Default ADIF Log Filename
#define DEFAULT_MY_NAME ""                    // Operator's personal name (not callsign)

void readConfigFile(void);
unsigned getLowerBandLimit(unsigned f);  // Calculate lower band limit for operating frequency f
unsigned getUpperBandLimit(unsigned f);  // Calculate upper band limit for operating frequency f

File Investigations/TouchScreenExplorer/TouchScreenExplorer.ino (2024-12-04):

/*
NAME
  TouchScreen Explorer

DESCRIPTION
  Investigates properties/behaviors of the Adafruit 320x480 resistive touchscreen,
  especially those helpful to understanding erratic (bouncing, dropout, noise...)
  coordinate readings, and whether those arise from circuit board crosstalk or
  from the inherent characteristics of the touchscreen.

USAGE
  The sketch accepts one-letter commands entered on the USB Serial port:
    (R)esistance:  Calculates the X-Plate resistance from X- to X+
    (N)oise:       Measures noise on the floating Y-Plate
    (T)ouch Event: Samples the Y-Plate voltage before/during/after touch event
    (S)ave         Saves the buffered samples to an SD file
    (C)onversion   Measure the average/stdev conversion time

EXERCISED
  + X-plate resistance
  + Idle (no touch) noise on Y-plate
  + Touch event noise (dropouts, erratic coordinates, etc)

NOTE
  + From the Pocket FT8 schematic, we know the Teensy 4.1 YP and XM pins
  connect to the touchpad Y+ and X- pins through 510 ohm resistors.  This
  hardware dependency is widely used below.
  + Pocket FT8 operates the MCP342x ADC with 12 bits at 240 samples/second.  The 
  range of possible readings from the ADC should be 0..2047.
  + We consider a touch event to begin when the ADC returns a value greater
  than or equal to the so-called MINPRESSURE.
  + We note when a touch event begins, and record samples into a FIFO
  ring buffer for 1.9 seconds.
  + Code assumes the touchscreen is instrumented by an MCP342X ADC external
  to the Teensy 4.1 CPU, not the Adafruit touchscreen controller board.

REFERENCES

ATTRIBUTION
  KQ7B, MIT License

*/

#include "DEBUG.h"

#include <Wire.h>
#include <SD.h>
#include "HX8357_t3n.h"
#include "MCP342x.h"

// These are the four touchscreen pins used by Pocket FT8 hardware
#define YP 38  // must be an analog pin, use "An" notation!
#define XM 37  // must be an analog pin, use "An" notation!
#define YM 36  // can be a digital pin
#define XP 39  // can be a digital pin

// Define the value of the resistors connecting the Teensy 4.1 YP and XM pins
// to the touchpad's Y+ and X- pins.
#define RYP 510  //Ohms
#define RXM 510  //Ohms

//Define Vcc
#define VCC 3.3  //Volts

// // Touchpad calibrarion as investigated on V1.01 hardware
// #define TS_MINX 123
// #define TS_MINY 104
// #define TS_MAXX 1715
// #define TS_MAXY 1130

//Other touchpad constants replicated from button.cpp in PocketFT8XcvrFW
#define MINPRESSURE 120
#define PENRADIUS 3

//Number of samples taken during one phase of the investigation
#define NSAMPLES 240  //About one seconds worth of samples

//Define the maximum possible ADC sampled voltage
#define maxADCreading 2047  //Largest signed 18 bit value returned from ADC

//Build the display object using pin numbers from Charlie's Pocket FT8 code
HX8357_t3n tft = HX8357_t3n(10, 9, 8, 11, 13, 12);  //Teensy 4.1 moved SCK to dig pin 13

//Build an instance of the MCP342x A/D Converter
uint8_t address = 0x69;  //Original I2C address was 0x68 but MCP342X V1.01 chip reports 0x68
MCP342x adc = MCP342x(address);

//Build an array for storing ADC samples
float samples[NSAMPLES];  //About one seconds

//State variable tracks when we've detected the beginning of a touch event
bool touchEventInProgress = false;



class RingBfrState {
public:
  int nextIn;   //Index of where next added value will be placed
  int nextOut;  //Index of where next removed value will be found
  int count;    //Number of values in the buffer
};

/*
** RingBfr -- A FIFO ring buffer of long integers
**
** Someday:  rewrite this class as a template for arbitrary types and buffer sizes
*/
class RingBfr {

public:

  /**
 * RingBfr constructor
**/
  RingBfr() {
    nextIn = nextOut = count = 0;
  }  //RingBfr()


  /**
 * @brief Reset a ring buffer to its initial conditions
 *
**/
  void reset() {
    nextIn = nextOut = count = 0;
  }  //reset()


  /**
 * Increment a ring buffer index, wrapping around to 0 if necessary
 *
 * @param  index The value to be advanced
 *
 * @return The advanced index
 *
 * The returned index value will always lie within 0..(bfrSize-1).  Advancement
 * is independent of the count of existing entries in the buffer.
 *
**/
  int advance(int index) {
    index++;                          //Increment a buffer index
    if (index >= bfrSize) index = 0;  //Wrap around to beginning?
    return index;
  }  //advance()


  /**
 * Retard (backup) a ring buffer index, wrapping around if necessary
 *
 * @param index The value to be retarded
 *
 * @return The retarded index value
 *
 * The returned value will always lie within 0..(bfrSize-1) even if the index parameter
 * lies outside that range.
 *
**/
  int retard(int index) {
    if (index >= bfrSize) index = bfrSize;  //Repair invalid index
    index--;                                //Backup the index
    if (index < 0) index = bfrSize - 1;     //Deal with wraparound
    return index;
  }  //retard()


  /**
 * Getter for the nextIn member
 *
 * @return Value of the nextIn member
 *
**/
  int getNextIn() {
    return nextIn;
  }


  /**
 * Getter for the bfrSize member
 *
 * @return The maximum number entries that the buffer can hold
 *
**/
  int getBfrSize() {
    return bfrSize;
  }


  /**
 * Add a value to the end of a FIFO ring buffer
 *
 * @param  newValue The value to be added
 * 
 * @return Updated count of entries in buffer or -1 if the buffer was found already full
 *
 * Adds newValue to the end of the ring buffer, advances nextIn, and increments the count.
 * Will not overwrite an existing buffer entry.
 *
**/
  int addNext(long newValue) {
    if (count >= bfrSize) return -1;  //Check for full buffer
    buffer[nextIn] = newValue;        //Add newValue to end of the buffer
    nextIn = advance(nextIn);         //Advance the nextIn buffer index
    count++;                          //Increment count of buffered values
    return count;                     //Number of buffered values
  }                                   //addNext()


  /**
 * Add a value to the end of a FIFO ring buffer, overwriting old values when full
 *
 * @param  newValue The value to be added
 * 
 * @return Updated count of entries in buffer (0..bfrSize)
 *
 * Similar to addNext() but overwrites the oldest entry when buffer overflows.
 * Updates nextOut to index the oldest, entry so that the  FIFO continues to work.
 *
**/
  int overwrite(long newValue) {
    buffer[nextIn] = newValue;  //Add newValue to end of the buffer
    nextIn = advance(nextIn);   //Advance the nextIn buffer index
    count++;                    //Increment count of entries
    if (count > bfrSize) {      //Did buffer overflow?
      nextOut = nextIn;         //After overflow, nextOut=nextIn=Index(Oldest Entry)
      count = bfrSize;          //Maintain buffer at its maximum capacity after overflow
    }
    return count;  //1..bfrSize
  }


  /**
 * Retrieve the next value from a FIFO ring buffer
 *
 * @param &value Retrieved value
 *
 * @return #elements remaining in buffer or -1 if buffer was already empty
 *
 * Retrieves the next entry, advances the nextOut index, and decrements the count
 *
**/
  int getNext(long &value) {

    if (count == 0) return -1;   //Check for empty buffer
    value = buffer[nextOut];     //Retrieve the oldest value from buffer
    nextOut = advance(nextOut);  //Advance the nextOut index
    count--;                     //Decrement count of remaining entries
    return count;                //Number of buffered entries remaining
  }                              //getNext()


  /**
 * Getter for the count of buffered entries
 *
**/
  int getCount() {
    return count;
  }


  /**
 * Set nextOut to the specified value
 *
 * @param index The specified new value
 *
 * @return Updated nextOut if success, else -1 if index lies outside the buffer's range
 *
 * The index must lie in the range, 0..(bfrSize-1)
 *
**/
  int setNextOut(unsigned index) {
    if (index >= bfrSize) return -1;  //Check for invalid index
    nextOut = index;                  //It's valid
    return nextOut;                   //Return valid index
  }


  /**
  *
  * Save the ring buffer's state
  *
  * Saves the ring buffer's indices and count so that the buffer can be
  * iterated multiple times.  Does not save the actual data nor the bfrSize.
  *
  **/
  void saveState(RingBfrState &savedState) {
    savedState.nextIn = nextIn;
    savedState.nextOut = nextOut;
    savedState.count = count;
  }  //saveState()




  /**
  *
  * Restore ring buffer's state
  *
  **/
  void restoreState(RingBfrState savedState) {
    nextIn = savedState.nextIn;
    nextOut = savedState.nextOut;
    count = savedState.count;
  }  //restoreState()


  //Private members
private:
  int nextIn;                      //Index of where next added value will be placed
  int nextOut;                     //Index of where next removed value will be found
  int count;                       //Number of values in the buffer
  static const int bfrSize = 480;  //Maximum number of buffer entries
  long buffer[bfrSize];            //Container for the actual buffered data entries

};  //class RingBfr




/**
 * Function to erase the Adafruit display
 *
**/
void eraseDisplay() {
  tft.fillScreen(HX8357_BLACK);
}




/**
 * Wait for conversion to finish
 */
void waitForADC() {
  long value;
  MCP342x::Config status;
  MCP342x::error_t err;
  //Wait for adc to finish
  do {
    err = adc.read(value, status);
    if (!err && status.isReady()) break;
  } while (true);
}

//Build the ring buffer object
RingBfr bfr;

//Initialization
void setup() {



  //Initialize the Arduino world and let console know we're starting
  Serial.begin(9600);
  delay(100);
  Serial.println("Starting...");

  //Initialize communication with MCP342X ADC
  MCP342X_WIRE.begin();
  MCP342x::generalCallReset();
  delay(1);  // MC342x needs 300us to settle, wait 1ms


  //Initialize the display
  tft.begin(HX8357D);
  eraseDisplay();
  tft.setTextColor(HX8357_YELLOW);
  tft.setRotation(3);  //PocketFT8FW uses 3
  tft.setTextSize(2);


  //Setup to instrument a touch event
  Serial.printf("Keyboard cmds:  (R)esistance, (N)oise, (T)ouchEvent, (S)ave, (C)onversion Timing\n");
  DTRACE();
  bfr.reset();  //Reset the ring buffer

}  //setup()


//Define the various activities commanded by the user
enum ACTIVITY { IDLE,        //Awaiting user's command
                RESISTANCE,  //Measuring X-Plate resistance
                NOISE,       //Measuring noise on Y-Plate
                TOUCH,       //Instrumenting a touch eventr
                SAVE,        //Saving data to an SD file
                CONVERSION   //Measure conversion time
};
enum ACTIVITY activity = IDLE;  //Current activity state variable

//Define vars that must be retained between calls to loop()
int eventStart;    //Records index of where touch event begins in ring buffer
int plotStart;     //Records index of where plot begins in ring buffer
int nSamples = 0;  //Number of samples acquired during touch event

//Loop executes user's commands
void loop() {

  //What activity is in-progress?
  switch (activity) {

    case IDLE:
      //Nothing --- Poll the Serial port for the user's next command
      switch (Serial.read()) {
        case 'R':
        case 'r':
          resetResistance();
          activity = RESISTANCE;  //Cmd to measure X-Plate resistance
          break;
        case 'N':
        case 'n':
          resetNoise();
          activity = NOISE;  //Cmd to measure noise on Y-Plate
          break;
        case 'T':
        case 't':
          resetTouch();
          activity = TOUCH;  //Cmd to instrument a touch event
          break;
        case 'S':
        case 's':
          activity = SAVE;  //Cmd to save sample buffer to SD file
          break;
        case 'C':
        case 'c':
          activity = CONVERSION;
          break;
        default:
          break;  //Await a valid user command
      }           //Serial.read
      break;

    case RESISTANCE:
      measureResistance();  //Measuring X-Plate resistance
      break;
    case NOISE:
      measureNoise();  //Measuring Y-Plate noise
      break;
    case TOUCH:
      instrumentTouchEvent();  //Instrumenting touch event
      break;
    case SAVE:
      saveData();  //Save the captured data to SD file
      break;
    case CONVERSION:
      conversionTiming();  //Measure the average conversion timing
      break;
    default:
      activity = IDLE;  //Attempt recovery from unknown wreck
      break;
  }  //activity
}  //loop()



/**
* Print prompt message
**/
void prompt() {
  Serial.printf("Keyboard cmds:  (R)esistance, (N)oise, (T)ouchEvent, (S)ave\n");
}




/**
 * Measure the resistance of the X-Plate
 *
 *
 **/
void resetResistance() {
  eraseDisplay();
  bfr.reset();  //Reset the ring buffer
  printf("\nAvoid touching the screen during X-Plate resistance measuement\n");
  Serial.println("Measuring X-Plate resistance...");
}
void measureResistance() {

  MCP342x::Config status;
  long value;
  float sum, v2, rXplate;
  RingBfrState savedState;


  //Setup to measure the X-Plate resistance between XP and XM.
  //Note:  The connections are, GND---XPlate---RXM---VCC, so by measuring V(XM) we have created
  //a voltage divider consisting of the XPlate and RXM, and knowing VCC, we can calculate the unknown
  //XPlate resistance.
  pinMode(XM, OUTPUT);     //The X-Plate pins are XM and XP, and...
  pinMode(XP, OUTPUT);     //XM connects to RXM and then to X- on plate
  pinMode(YM, INPUT);      //Float Y plate connections
  pinMode(YP, INPUT);      //Float Y plate connections
  digitalWrite(XM, HIGH);  //Connect Vcc through RXM to X- side of plate
  digitalWrite(XP, LOW);   //Ground X+ side of the plate

  //Acquire ~1 second of samples of the voltage appearing on the touchpad's X- pin for the resistance calculation
  int i;
  uint8_t err;
  for (i = 0; i < NSAMPLES; i++) {
    err = adc.convertAndRead(MCP342x::channel2, MCP342x::oneShot, MCP342x::resolution12, MCP342x::gain1, 1000000L, value, status);
    if (err != 0) {
      DPRINTF("err=%d\n", err);
    }
    bfr.addNext(value);  //Add ADC value to the end of FIFO ring buffer
  }

  //Calculate the average value of the voltage on touchpad's XM pin (Note:  it may be noisy).  We are using
  //the ring buffer rather than a simple array so that plotBufferedData() has access to the samples.
  sum = 0.0;
  bfr.saveState(savedState);  //Save ring buffer's state
  for (i = 0; i < NSAMPLES; i++) {
    bfr.getNext(value);  //Retrieve next value from FIFO ring buffer
    sum += value;        //Sum all the readings from the ring buffer
  }
  v2 = (sum / float(NSAMPLES));  //Average value read from on touchpad's XM pin
  v2 = v2 / maxADCreading;
  //DPRINTF("sum=%f, NSAMPLES=%d, maxADCreading=%ld, v2=%f\n", sum, NSAMPLES, maxADCreading, v2);
  bfr.restoreState(savedState);  //Restore ring buffer's state

  //Now we can calculate the resistance of the X-Plate
  DPRINTF("RXM=%d, VCC=%f, v2=%f\n", RXM, VCC, v2);
  rXplate = (RXM * v2) / (VCC - v2);
  printf("X-Plate resistance = %f Ohms\n", rXplate);

  //Calculate the stdev (noise) of the X-Plate voltage measurements.  Note:  We are trying to learn whether
  //erratic touch event coordinates arise from noise on the PCB or from a noisy connection between the
  //X and Y resistive plates during a touch event.  Here we see the PCB noise with ~1 mV sensitivity on
  //the biased Xm without a touch event.
  float sumDevSquared = 0.0;
  bfr.saveState(savedState);  //Save ring buffer's state yet again

  for (i = 0; i < NSAMPLES; i++) {
    bfr.getNext(value);                                   //Retrieve next value from FIFO ring buffer
    float deviation = float(value) / maxADCreading - v2;  //Deviation of this value from average
    sumDevSquared += (deviation * deviation);             //Deviation squared
  }
  float stdev = sqrt(sumDevSquared / NSAMPLES);  //Standard deviation
  printf("X-Plate noise (stdev) measured at XM = %f volts\n", stdev);
  bfr.restoreState(savedState);  //Restore ring buffer's state
  plotBufferedData();            //Plot the buffered data

  //Resistance measurement has finished.  Data in the ring buffer can be (S)aved to SD.
  activity = IDLE;

}  //measureResistance()





/**
 * Measure noise
 *
 * This activity instruments the noise on the floating Y-Plate, akin to what the ADC samples
 * prior to and following a touch event.  The idea is to instrument the noise on the unloaded
 * Y-plate.  The samples are taken with about ~1 mV sensitivity.  Unlike many other
 * measurements made in this sketch, these *might* include negative values.  Since there is
 * no source applied to the floating plate, we seemingly can assume the observed noise
 * arose through crosstalk in the display, the PCB, or the ADC itself.
 **/
float noise;
float avg;
unsigned long maxReading;
void resetNoise() {
  eraseDisplay();
  bfr.reset();  //Clear the bfr of old data
  nSamples = 0;
  maxReading=0;
  noise = 0.0;
  avg = 0.0;
  //Setup the X+/X- pins just like we would to capture a touch event just in case the X-Plate
  //is the source of any noise coupled to the Y-Plate
  pinMode(XM, OUTPUT);     //The X-Plate pins are XM and XP, where...
  pinMode(XP, OUTPUT);     //XM connects throuh RXM to X- on plate
  digitalWrite(XM, HIGH);  //Connect Vcc through RXM to X- side of plate
  digitalWrite(XP, LOW);   //Ground X+ side of the plate
  //Float (high impedance) the Y-Plate connections so the ADC measures the unloaded Y-Plate voltage
  pinMode(YM, INPUT);
  pinMode(YP, INPUT);
  printf("\nAvoid touching the screen during the noise measurement\n");
}
void measureNoise() {
  RingBfrState savedState;
  uint8_t err;
  long value;
  MCP342x::Config status;


  //Get the next value (0..2047) from the ADC
  err = adc.convertAndRead(MCP342x::channel1, MCP342x::oneShot, MCP342x::resolution12, MCP342x::gain1, 100000, value, status);
  if (err != 0) {
    DPRINTF("adc.convertAndRead err=%d\n", err);
    return;
  }

  if (abs(value)>maxReading) maxReading=abs(value);

  //Add the ADC value to the ring buffer, overwriting the oldest entry when the buffer fills
  bfr.overwrite(value);  //Always record the sampled value in the ring buffer

  avg += value;  //Sum values to later compute average

  //Tally this sample
  nSamples++;

  //Was this the final sample?
  if (nSamples == 480) {  //We want to acquire 2 seconds of noise data
    DPRINTF("sum=%f\n", avg);

    avg = avg / 480;                      //average raw value
    avg = (avg / maxADCreading) * 2.048;  //Avg volts
    printf("Average voltage on floating YP=%f volts\n", avg);
    printf("Max ADC reading=%lu\n",maxReading);

    //Plot the buffered noise data
    plotBufferedData();  //Generate the plot
    activity = IDLE;     //The noise measurement is finished.  Data in the ring buffer can be (S)aved to SD.
  }
}




/**
  * (S)ave buffered data to SD file
  *
  * Saves the entire contents of the ring buffer to a single column CSV file.  The ring 
  * buffer's state remains unchanged.  Files are named, FILE01.CSV, FILE02.CSV, etc.  
  * Existing files by the same name, if any, are overwritten.
  *
  **/
unsigned filenameIndex = 0;
void saveData() {
  char filename[256];
  RingBfrState savedState;
  char s[256];
  long value = 0;

  //Build the filename
  sprintf(filename, "/FILE%2d.CSV", filenameIndex);

  //Initialize the Teensy SD library if the card is available
  if (!SD.begin(BUILTIN_SDCARD)) {
    Serial.println("Error:  Unable to access the SD card");
    activity = IDLE;
    return;
  }

  //Create the file
  File dataFile = SD.open(filename, FILE_WRITE);
  if (!dataFile) {
    Serial.printf("Error:  Unable to create %s\n", filename);
    activity = IDLE;
    return;
  }

  //Write the contents of the ring buffer to dataFile
  bfr.saveState(savedState);  //Save ring buffer state
  for (int i = 0; i < bfr.getCount(); i++) {
    bfr.getNext(value);
    sprintf(s, "%ld\n", value);
    dataFile.write(s);
  }
  bfr.restoreState(savedState);
  dataFile.close();
  activity = IDLE;  //(S)ave has finished
}



/**
 * Instrumenting a touch event
 *
 * The idea here is to capture the voltage on the Y-Plate before, during, and after a touch event
 * to observe the noise (dropouts, varying contact resistance between the plates, crosstalk, etc)
 * underlying the touchscreen's erratic behavior.  The 12-bit ADC has a resolution of about 1 mV
 * and negative readings seem unlikely while the plates are touching.
 *
 * Note:  nSamples counts the number of samples made after the user pressed the (T)ouch command
 * while bfr.count tracks the number of recorded samples starting about 0.1 second before the
 * touch event begins.  We expect to record a total of about 2 seconds of data prior to, during
 * and following the touch event.
 *
 **/
bool negativeReadingObserved;
void resetTouch() {
  eraseDisplay();
  bfr.reset();                      //Clear the bfr of old data
  nSamples = 0;                     //At this point, we have acquired no samples
  negativeReadingObserved = false;  //These are unexpected, at least during an event
  touchEventInProgress = false;     //Reset to capture a new event
    //Setup the X+/X- pins to capture a touch event's x coordinate on the Y-Plate
  pinMode(XM, OUTPUT);     //The X-Plate pins are XM and XP, where...
  pinMode(XP, OUTPUT);     //XM connects throuh RXM to X- on plate
  digitalWrite(XM, HIGH);  //Connect Vcc through RXM to X- side of plate
  digitalWrite(XP, LOW);   //Ground X+ side of the plate
  //Float (high impedance) the Y-Plate connections so the ADC measures the unloaded Y-Plate voltage
  pinMode(YM, INPUT);
  pinMode(YP, INPUT);
  printf("\nTap the touchscreen\n");  //Prompt the user
}
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

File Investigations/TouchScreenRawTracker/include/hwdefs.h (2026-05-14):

#pragma once
/*
**
** NAME
**  pins.h --- Define usage of all GPIO pins in this one place
**
** NOTES
**  If you change processors, displays, etc, you may need to reevaluate the GPIO pin assignments
**
**  Many of the PIN_* names reflect their labels in the schematic
**
**  The V2.0 boards control the RCV and XMT signals using firmware thru PIN_RCV and PIN_XMT.
**  This firmware implementation is compatible with both V1.X and V2.0 boards.
**
**  V2.X and V3.X boards use an MCP342X external 12-bit ADC to read the touchscreen signals.
**
**  V4.X boards eliminate the MCP342X and read the touchscreen through ADC1 A16 and A17 while
**  the Teensy 4.1 audio pipeline uses ADC2 and A2.
**
** HISTORY
**  10/08/2024 Teensy 4.1 pin assignments by KQ7B
**  03/14/2026 Version 4.X boards move the touchscreen to Teensy 4.1's A16 and A17 pins
**
**/

// Define the hardware version number (whole integral values only)
// #define HW_VERSION 2        //Version 2.X boards (working lab prototype)
// #define HW_VERSION 3        // Version 3.X boards (never mfg'd due to tariffs)
#define HW_VERSION 4  // Version 4.X boards (uses internal touchscreen ADC)

// The Adafruit 480x320 display pins
#define PIN_CS 10
#define PIN_DC 9
#define PIN_DRST 8
#define PIN_MOSI 11
#define PIN_DCLK 13  // Teensy 4.1
#define PIN_MISO 12

// I2C pins
#define PIN_SCL 19   // Wire
#define PIN_SDA 18   // Wire
#define PIN_SCL2 24  // Wire2
#define PIN_SDA2 25  // Wire2

// I2C bus definitions for the Wire objects
#define WIRE_RCV Wire   // The SI4735's private bus
#define WIRE_ETC Wire2  // Everything (SI5351, MCP342x) else

// Serial bus definitions for optional GPS
#define SerialGPS Serial1

// SI4735 pins
#define PIN_RRST 20  // Resets the Si4735
#define PIN_AF A2    // Si4735 received audio connected to A2 via Pin 16

// Transmit/Receive pins
#define PIN_XMT 14  // Teensy 4.1
#define PIN_RCV 15  // FW implementation of ~PTT (i.e. RECV) in V2.0 boards

// Adafruit resistive touchscreen pins (External ADC HW option)
#define PIN_YR 38  //
#define PIN_XR 37  //
#define PIN_YM 36  // Any digital pin
#define PIN_XP 39  // Any digital pin

#if HW_VERSION >= 4
// Version 4.X hardware internal Teensy 4.1 ADC pins (Note:  Versions 2.X and 3.x
// use an external ADC read via I2C rather than an internal ADC) for reading the
// touchscreen pins (Schematic signals XDM and YDP).  Note:  You can
// patch a V3.X PCB to make these signal connections for the internal ADC
#define PIN_XM A16  // Y-Coord analog input signal sampled from display's floating XM pin (A16)
#define PIN_YP A17  // X-Coord analog input signal sampled from display's floating YP pin (A17)
#endif

// GPS pins (Teensy 4.1 Serial1)
#define PIN_GPSTX 0  // TX data from GPS
#define PIN_GPSRX 1  // RX data from GPS
#define PIN_PPS 2    // PPS pulse

// Auxilliary pins for future expansion (Require V3+ PCB)
#define PIN_AN13 27  // A13
#define PIN_D27 27   // D27
#define PIN_D28 28   // D28
#define PIN_D29 29   // D29
#define PIN_D30 30   // D30
#define PIN_D31 31   // D31

// The ADC calibration data for V4.X hardware is using a 3.3V reference to Vcc
// And analog.c is using a 10-bit resolution rather than the MCP342X 12-bits.
#if HW_VERSION >= 4
#define TS_MINX (137 >> 2)
#define TS_MINY (126 >> 2)
#define TS_MAXX (2182 >> 2)
#define TS_MAXY (1392 >> 2)
#define MINPRESSURE (120 >> 2)  // I don't think the pressure stuff is working as expected
#define PENRADIUS 3
#else
// This is calibration data for the MC342x ADC to the screen coordinates
// using 510 Ohm resistors to reduce the sensors' driven voltage to Y+ and X-
// where the ADC reference voltage is 2.048 volts, and sampling at 12-bits.
#define TS_MINX 123
#define TS_MINY 104
#define TS_MAXX 1715
#define TS_MAXY 1130
#define MINPRESSURE 120  // I don't think the pressure stuff is working as expected
#define PENRADIUS 3
#endif

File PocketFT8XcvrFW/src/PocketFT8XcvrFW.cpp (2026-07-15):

/*
** NAME
**  PocketFT8XcvrFW -- Firmware for the Pocket FT8 Revisited Software Defined Radio Transceiver
**
** DESCRIPTION
**  The KQ7B PocketFT8Xcvr is a derivative of the original Pocket FT8 transceiver
**  in a compact, self-contained, package.  Notable features include:
**    + 4-Layer PCB
**    + Single band FT8 transmit/receiver
**    + Teensy 4.1 processor
**    + 4.0x2.8" PCB mates with the Adafruit display
**    + Adafruit 320x480 3.5" resistive touchscreen display
**    + TCXO
**    + Powered by 0.37 Amps from a single +5V USB power source
**    + SD Card logging to ADIF file
**    + Station configuration JSON file
**    + "RoboOp" FT8 QSO sequencer
**    + Plugable filters
**    + GPS disciplined UTC time and location
**    + Optional Adafruit Ultimate GPS automates time synchronization and Maidenhead Grid Square locator
**  The overall goal is to deliver a single band, fully self-contained, HF FT8 transceiver for
**  POTA/SOTA work where light weight and power requirements dominate other goals.
**
** RATIONAL
**  + Single-band operation is not a serious limitation for SOTA/POTA work where the portable
**  antenna limits the available band(s).
**  + QRPP == battery life for portable work
**  + While the SI4735 receiver's performance likely lags that available from a Tayloe detector,
**  it offers considerable simplicity and effectiveness for SOTA/POTA FT8 operation and will
**  likely receive most stations that hear our QRPP transmissions
**
** FUTURE
**    + Consider using a real touchscreen controller to replace the MCP342X ADC
**    + Bug fixes (see https://github.com/conr2286/PocketFT8Xcvr Issues)
**    + Update the FT8 library with Karlis' more recent code
**
** DEBUGGING
**  Because the Teensy 4.1 MCU lacks a JTAG or related debugging port, we are debugging everything
**  with the USB Serial port.  To facilitate this, Pocket FT8 code is laced with DPRINTF() and
**  DTRACE() macros, defined in DEBUG.h or NODEBUG.h.  The DPRINTF() macro works more or less like
**  a Serial.printf() while DTRACE() merely outputs a source filename and line number.  A source
**  file can enable debugging by including DEBUG.h or disable all its debug output messages by
**  including NODEBUG.h.  See examples in the code.  ;)
**
** KQ7B (conr2286 AT gmail.com)
**  Retired engineer living in north central Idaho (USA), stereotype "old guy"
**  ham radio operator, began constructing radios and first licensed in the 1960s.
**  "What a long, strange trip it has been." -- The Grateful Dead
**
** VERSIONS
**  1.00 Never completed due to unobtanium componentry
**  1.01 PCB required several patches to correct known issues.  You don't want this.
**  1.10 Working firmware and transmitter but SI4735 suffers serious I2C noise issues.  Avoid this one too.
**  2.00 Revised board/firmware overcomes I2C noise problems.  Requires one patch wire for GPS.
**  2.10 Firmware implements bug fixes, ADIF logging, and the "RoboOp" QSO Sequencer.  Uses V2.00 boards.
**  3.00 New PCB artwork eliminates need for PPS patch wire... but awaits satisfactory tariff solution
**
** ATTRIBUTION
**  https://github.com/Rotron/Pocket-FT8  Charley Hill's original Pocket FT8 project
**  https://github.com/WB2CBA/W5BAA-FT8-POCKET-TERMINAL  Barb's FT8 Pocket Terminal
**  https://github.com/kgoba/ft8_lib  Karlis Goba's FT8 Library for microprocessors
**  https://github.com/conr2286/PocketFT8Xcvr  The KQ7B HW and FW projects
**  Many other contributors (e.g. Adafruit et al) to the various libraries
**
** LICENSES
**  + The permissive MIT license widely cited throughout the Pocket FT8 firmware and libraries
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

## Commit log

2024-07-31 Organizing KiCAD and Arduino work-in-progress
    Initial, unreviewed KiCad 7 schematic.
    Original Pocket FT8 firmware + updates for Teensy 4.1 (compiles but untested).
    [ANTTENA.fzz, PocketFT8Xcvr.kicad_pcb, PocketFT8Xcvr.kicad_sch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]
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2024-07-31 Added the awful 7805 regulator
    [PocketFT8Xcvr.kicad_sch]
2024-08-01 1st Review of Schematic Capture
    [PocketFT8Xcvr.kicad_sch]
2024-08-01 Results from LP Filter Simulation
    2nd harmonic rejection of the original low pass filter is greatly improved with inclusion of a 36 mHz trap. The current version of the truth is to include the trap capacitor paralled with L1 (value u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
    [LowPassFilter.kicad_pcb, LowPassFilter.kicad_sch, LowPassNoTrap.kicad_pcb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]
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2024-08-01 Trying to get git to ignore kicad backups
    [PocketFT8Xcvr.kicad_sch]
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2024-08-02 Schematic passes Electrical Rules Check (ERC)
    [PocketFT8Xcvr.kicad_sch]
2024-08-02 BOM construction begun
    Connectors and capacitors
    [ANTTENA.fzz, PocketFT8Xcvr.kicad_pcb, PocketFT8Xcvr.kicad_sch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]
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2024-08-06 Poured GND and 3.3V into zones on in.1 and in.2 layers
    [PocketFT8Xcvr.kicad_pcb]
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2024-08-09 Delete 7805 voltage regulator
    Decision: Avoid heat dissipation issues with 12->5V linear regulators through use of widely available portable USB power banks supplying 5V at >= 1A via a USB-C to MicroUSB-B cable. These consumer devices deliver enough highly portable power for QRP communications. Their external noise problems may be easier to resolve than the internal heat/noise problems of 5V regulator designs. Long-term, "true" USB-C offers even more power capability should Teensy adopt it.
    [PocketFT8Xcvr.kicad_sch]
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2024-08-10 Simulations of Low Pass Filter + Harmonic Trap
    [Book2.xlsx, LowPassFilter.kicad_sch, LowPassNoTrap.kicad_sch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]
2024-08-11 Bench test development for the PocketFT8Xcvr hardware
    The tests are intended to be executed (and passed) in numerical order
    [ANTTENA.fzz, PTHComponents.xlsx, PocketFT8Xcvr.kicad_pcb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]
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2024-08-12 Built a QFN20 version for SI5351C in case QFN16 not available
    [PTHComponents.xlsx, PocketFT8Xcvr.kicad_pcb, PocketFT8Xcvr.kicad_sch]
2024-08-13 V1.00 As built by PCBway, Aug 7, 2024
    [PCBWayBOM.xlsx, PTHComponents.xlsx]
2024-08-15 Resubmit to PCBWay with SI5351c QFN20 Package
    QFN16 was unobtanium
    [PocketFT8Xcvr-B_Cu.gbr, PocketFT8Xcvr-B_Mask.gbr, PocketFT8Xcvr-B_Paste.gbr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]
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2024-08-16 V1.01 Resubmit gerbers and pos file to PCBWay
    The QFN16 SI5351C-B-GM1 proved unobtanium and was replaced with the QFN20 package, SI5351C-B-GM. The submitted fabrication files are in the CAM folder.
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2024-08-21 Created Pocket FT8 Proto PA
    Prototype of a ~1W PA using BS170s with Vcc=5V for a future version of the transceiver. The low-pass filter can be implemented as a Butterworth with a harmonic trap, or as a Chebyshev without a trap.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
    [LowPassChebyshev.kicad_pcb, LowPassChebyshev.kicad_sch, PA.kicad_pcb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]
2024-08-21 PA Proto submitted to PCBWay
    First PA Proto uses XOR to generate differentials, (2) BS170 finals, 5Vcc, and Chebyshev LP filter on a 2-Layer Board.
    [PA-B_Cu.gbr, PA-B_Mask.gbr, PA-B_Paste.gbr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]
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2024-09-09 PCB Patch, test and FW changes to repair 1-v101-sck-and-ptt-reversed
    SCK signal moved from digital pin 14 in Teensy 3.6 to pin 13 in Teensy 4.1. Workaround PCB patch swaps pins 13 and 14. Schematic, board layout, tests and FW updated for revised pin assignments. Test03-Display now passes.
    [PocketFT8Xcvr.kicad_pcb, PocketFT8Xcvr.kicad_sch]
2024-09-10 Fixed XMIT LED is always "on" and cannot be turned-off
    The digikey 2N3904 symbol reversed the pin numbers for B and C. This commit includes the schematic with the corrected symbol.
    [PocketFT8Xcvr.kicad_pcb, PocketFT8Xcvr.kicad_sch]
2024-09-10 Resolve MCP3422 I2C address is 0x69 not 0x68
    The MCP3422 V1.01 chip reports 0x69, not 0x68 as in Charlie's original implementation. Changes have been applied to both Test05-Touchpad and PocketFT8XcvrFW for the new address. Test05-Touchpad is now reporting X,Y coordinates when display is touched.
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2024-09-12 Fixed failure to initialize ref_freq[] for CLKIN
    Si5351:init failed to initialize ref_freq[] and corr[] for SI5351_PLL_INPUT_CLKIN
    [Test06-Si5351.ino]
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2024-09-16 Resolved: Touchpad needs coordination over full screen #8
    Added R12 and R13 to lower the driven voltage to the touchpad so that it lies below the MCP3422's 2.048 Volt reference.
    [PocketFT8Xcvr.kicad_pcb, PocketFT8Xcvr.kicad_sch]
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2024-09-16 Resolve Call to receive_sequence() hangs In PocketFT8XcvrFW. No further information available.
    PTT_PIN was incorrectly configured for Teensy 4.1 in traffic_manager.cpp. It was D13 in Charlie's original Teensy 3.6 Pocket FT8 code but had to move to D14 for Teensy 4.1
    [traffic_manager.cpp]
2024-09-18 Resolved PocketFT8Xcvr crashes and reboots following first calls to process_FT8_FFT(), extract_power(), and arm_rfft_q15()
    Wrong audio sample rate. The Teensy audio architecture changed from 3.6 to 4.1. The pdb.h file is no longer used to lower the audio sample rate to 32K. The analagous code is now in AudioStream_32k.h which must be copied into .../Arduino15/packages/teensy/hardware/avr/1.59.0/cores/teensy4 as AudioStream.h followed by a rebuild of everything. PocketFT8Xcvr is no longer crashing in the first call to arm_rfft_q15().
2024-09-19 All known HW have workarounds. FW is executing loop() and responding to buttons.
    [traffic_manager.cpp]
2024-09-19 Resolve V1.01 PCB is using the Teensy 3.X rather than 4.X audio input network on pin A2 #15
    Resolution modifies V1.01 schematic to replace 10K R6 with 2.2K Ohms per Teensy Audio System Design Tool documentation for ADC input on Teensy 4.1.
    [PocketFT8Xcvr.kicad_pcb, PocketFT8Xcvr.kicad_sch]
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2024-10-05 Moved battery to back (solder) side of board
    [PocketFT8Xcvr.kicad_pcb, PocketFT8Xcvr.kicad_sch]
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2024-10-06 Pivot to 74ACT244DWR Power Amplifier (in progress)
    ToDo: LPF values, bifilar transformer specs, QA checks (esp. XMIT/RECV logic)
    [PocketFT8Xcvr.kicad_pcb, PocketFT8Xcvr.kicad_sch]
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2024-10-08 Changed PA from MMIC to 74ACT244
    New PA chip.
    Optional step-up power supply apparently helps xmit power.
    Connector for choosing PA power (5V or ~6.6V).
    Misc bug fixes.
    7-Pole LP filter (TODO: Choose the real inductor/capacitor values).
    [PocketFT8Xcvr.kicad_pcb, PocketFT8Xcvr.kicad_sch]
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2024-10-09 REPLACED the two 2N7000s with a dual mosfet, 2N7002DW
    [PocketFT8Xcvr.kicad_pcb, PocketFT8Xcvr.kicad_sch]
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2024-10-10 Added test points
    Don't use sparkfun TPs again :(
    [PocketFT8Xcvr.kicad_pcb, PocketFT8Xcvr.kicad_sch]
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2024-10-15 Implemented SD configuration file
    The config file has potential use for debugging which made it more urgent
    [PocketFT8Xcvr.kicad_sch]
2024-10-16 Revise AudioStream.h for PocketFT8 sampling at 6400 samples/second
    The Teensy 4.1 audio library defines the AUDIO_SAMPLE_RATE_EXACT at 44100.0f but Pocket FT8 requires 6400.0f.
    Beware: Teensy 3.6 implemented this change in pdb.h and this apparently does not work with Teensy 4.1.
    Beware: The Pocket FT8 Terminal requires yet another sample rate and implements it in AudioStream.h similar to what's needed here.
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2024-10-17 Various debugging Issue #23 trials.
    [PocketFT8Xcvr.kicad_sch]
2024-10-19 Cleanup around SI4735, etc. for noise reduction
    [PocketFT8Xcvr.kicad_pcb, PocketFT8Xcvr.kicad_sch]
2024-10-19 Additional rerouting to minimize noise
    [PocketFT8Xcvr.kicad_pcb]
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2024-10-21 Resolve #14 (CQ not transmitted until traffic decoded)
    [traffic_manager.cpp]
2024-10-21 Traffic Manager doesn't enable/disable receiver for Tu (Tune) off/on #25
    Code now sets PIN_RCV to 0 prior to setting PIN_PTT to 1
    [traffic_manager.cpp]
2024-10-22 Implement changes to allow SI5351 and MCP342X to move to Wire2 bus
    This migration is part of SI4735 noise mitigation. The SI4735 is known to be sensitive to other traffic on its I2C bus. The idea is to leave the SI4735 on Wire and move everything else to Wire2 in V2 of the board.
2024-10-23 Debugging noise (Issue #23)
    Disabling I2C polling of touchscreen ADC *greatly* improves reception evidenced by both the number of decoded messages and their signal strengths. Removing the touchpanel display may provide a minor additional improvement (difficult to measure on-the-air).
    [traffic_manager.cpp]
2024-10-23 Cleanup debugging code and formatting before branching
    ...about to create a release branch for V1.10 HW/FW, and a development branch for the V2.00 HW and FW (to resolve SI4735 I2C noise issues).
    [display.h]
2024-10-23 Isolate SI4735 I2C traffic from other I2C chips for Issue #23
    + The ADC and SI5351 now reside on SCL2/SDA2. The SI4735 remains on SCL/SDA. There are now two I2C bus's.
    + The SI5351 XCLK now drives a single gate re. recommendation for SI5351 phase noise performance.
    + Improved +5V bulk (low frequency) decoupling.
    [PocketFT8Xcvr.kicad_pcb, PocketFT8Xcvr.kicad_sch]
2024-10-24 Ongoing PCB noise mitigations
    [PocketFT8Xcvr.kicad_pcb, PocketFT8Xcvr.kicad_sch]
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2024-10-26 Code changes placing touchscreen ADC and SI5351 on Wire2
    Previous experiments demonstrated the SI4735 noise largely originated from I2C activity for other devices on the Wire bus. The PCB and FW now place the SI4735 on Wire and the other I2C devices on Wire2.
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2024-10-28 Both the main board and filter board submitted to PCBway
    [LowPassChebyshev.kicad_sch, PocketFT8Filters.kicad_pcb]
2024-11-07 V2.01 Correct schematic for 51 ohm, C22 and C23 values
    Problem found by PCBway
    [PocketFT8Xcvr.kicad_pcb, PocketFT8Xcvr.kicad_sch]
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2024-11-11 40 Meter Bandpass Filter LTspice Simulation
    LTspice was used to evaluate the performance of the 40M bandpass filter
    [PocketFT8Filters.kicad_pcb, PocketFT8Filters.kicad_sch]
2024-11-22 Preparing bench tests and investigations for V2.00 hardware
    V2.00 hardware has a second I2C bus, a new SN74ACT244 PA, serial support for a GPS, and the complimentary XMT/RCV signals are now implemented in firmware to avoid an unnecessary gate.
    [ClassDSimulation.kicad_pcb, ClassDSimulation.kicad_sch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]
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2024-12-02 Investigating I2C failure on V2.00 HW
    [Test04-I2C.ino]
2024-12-03 Resolve Issue #24. Test04-I2C didn't find the SI4735 on SDA/SCL
    [Test04-I2C.ino]
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2024-12-04 Fixing tests for V2.00 boards
    [TouchScreenExplorer.ino]
2024-12-04 Update TouchScreenExplorer.ino
    Chasing the touchscreen noise problem
    [TouchScreenExplorer.ino]
2024-12-05 Debugging SI5351 test
    Output frequency off by 100X??? Does set_freq() really want 1/100 Hz resolution? Or has something went wrong?
    [Test06-Si5351.ino, Test07-Xmit.ino]
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2024-12-07 SI5351 moved from Wire to Wire2 in V2.00 hardware
    [40MFilters.xlsx, PocketFT8Xcvr.kicad_pcb, PocketFT8Xcvr.kicad_sch]
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2024-12-09 Issue #31: Enhance PocketFT8Xcvr.ino to catch wrong audio sample rate
    Teensy library updates will replace AudioStream.h, changing the sample rate from 6400. The workaround verifies the expected sample rate during setup().
2024-12-09 Issue #23: Isolating SI4735 on a private I2C bus resolves noise/reception issue
    The V2.00 hardware places SI4735 on Wire, and the SI5351 and MCP342x on Wire2 busses.
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2024-12-11 Submitted PCBWay order for 5-Pole Chebyshev LP Filter boards
    [5PoleLPFilter.kicad_pcb, 5PoleLPFilter.kicad_sch]
2024-12-21 Gathered all the filter designs/models into one folder
    [40MFilters.xlsx, 5PoleLPFilter.kicad_pcb, 5PoleLPFilter.kicad_sch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]
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2024-12-31 New bandpass filter PCB and ft8 decoding investigation
    [Bandpass40m.kicad_pcb, Bandpass40m.kicad_sch]
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2025-02-03 Resolve #47, snr=6 reports as 0dB
    [PocketFT8XcvrFW.cpp]
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2025-02-19 Resolve #52
    Confusing message in debugging stream
    [traffic_manager.cpp]
2025-02-19 Update Sequencer.cpp
    timeslotEvent() was missing a case for LISTEN_RRR
2025-02-19 Fix #54 and #55
    ADIF log now reports transmitter power and rig name.
    Sequencer now distinguishes "CQ" from "CQ DX" and related targeted CQs
2025-03-28 A_GUI implementation in progress in Investigations
    + Bug fixes for HX835_t3n which fails to include SP char in getTextBounds() calculation. FIx: Treat ' ' like a '_' char.
    [PocketFT8XcvrFW.cpp, display.h, main.cpp]
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2025-04-16 Connect XCLK to MCU
    We may use the GPS PPS timing signal to instrument the accuracy of XCLK operating at, say, 1 mHz and thus derive a calibration adjustment for the TCXO.
    [PocketFT8Xcvr.kicad_pcb, PocketFT8Xcvr.kicad_sch]
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2025-05-18 refactor and bug fix
    [PocketFT8XcvrFW.cpp]
2025-06-04 Added enclosure
    FreeCAD enclosure and the display bezel
    [PocketFT8DisplayBezel-Part.stl, PocketFT8DisplayBezel.FCStd, PocketFT8Enclosure.FCStd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]
2025-07-13 Reordered GPS pins to align with Adafruit Ultimate GPS PA1616S
    [PocketFT8Xcvr.kicad_sch]
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2025-07-18 PCB Cleanup
    + GPS signal pins now align with Adafruit's Ultimate GPS to simplify cable
    + Added PPS pin to GPS signals
    + Added extra connector for Teensy analog/digital expansion pins
    [PocketFT8Xcvr.kicad_pcb, PocketFT8Xcvr.kicad_sch]
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2025-09-24 Changed Decoded Message Display from six message to 9 message display.
    Commissioned SY touch buttonn to perform manual synchronizartion
    Raised Receiver Volume from 0 to 20 during Tune and Transmit
    Set Si5351 correction factor to -5000.
    [PocketFT8XcvrFW.cpp, display.h, traffic_manager.cpp]
2025-10-25 Cleaning up crashes arising from new ft8_lib code
    [PocketFT8XcvrFW.cpp]
2026-01-30 Ongoing refinements/fixes to ui
    [PocketFT8XcvrFW.cpp]
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2026-01-31 Fixed Sequencer failed to abort CQ
    [PocketFT8Xcvr-B_Cu.gbl, PocketFT8Xcvr-B_Mask.gbs, PocketFT8Xcvr-B_Paste.gbp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]
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2026-02-08 PCBway Submission on Feb 8, 2026
    Fix GPS pin order, add AUX connector
    [PocketFT8Xcvr.kicad_pcb, PocketFT8Xcvr.kicad_sch]
2026-02-13 Fixing KiCAD symbols/footprints
    ...damaged by KiCAD upgrade library reorg.
    [PocketFT8Xcvr.kicad_pcb, PocketFT8Xcvr.kicad_sch]
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2026-03-14 V4 PCB Layout
    Replace MCP342X with Teensy 4.1 internal ADC1 pins A16 and A17
    [PocketFT8Xcvr.kicad_pcb, PocketFT8Xcvr.kicad_sch]
2026-03-14 Cleanup V4 Label Names to Match Firmware GPIO Pin Names
    For touchscreen
    [PocketFT8Xcvr.kicad_pcb, PocketFT8Xcvr.kicad_sch]
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2026-03-15 V4.00 Submitted to PCBWay Mar 15 2026
    Removes MCP342X and replaces 2.0K resistors with 2.2K used elsewhere, eliminating a total of 2 unique components. Updates version number in silkscreen.
    [PocketFT8Xcvr.kicad_pcb, PocketFT8Xcvr.kicad_sch]
2026-03-17 V4.01 corrects mistakes in BOM
    Component reduction introduced several errors.
    [PocketFT8Xcvr.kicad_pcb, PocketFT8Xcvr.kicad_sch, PocketFT8XcvrV4.bom.csv]
2026-03-19 Resolve c++ static initialization order fiasco with GPShelper and Adafruit_GPS
    [PocketFT8XcvrFW.cpp]
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2026-03-25 Update 5PoleLP Filter
    + V4.00 Hardware LP Filter PCB
    + Remove deprecated files
    [5PoleLPFilter.kicad_pcb, 5PoleLPFilter.kicad_sch, Bandpass40m.kicad_pcb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]
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2026-05-13 Progress on TestCalibration.cpp with AGUI bug fixes in AWidget for AToggleButton
    [main.cpp]
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2026-05-17 Remove deprecated TouchScreen_I2C code, and repair bug in TouchScreenCalibration
    [PocketFT8XcvrFW.cpp]
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2026-07-06 Use GPS RTC UTC time at startup instead of Teensy RTC
    Prior to satellite acquisition, use GPS RTC UTC time which is in UTC
    and suitable for logging. The Teensy RTC has an unknown time zone
    making it useless for logging (issue #94).
    - Add GPShelper::obtainGPSrtcTime() that reads UTC date/time from
    the GPS module's internal RTC without requiring a satellite fix
    - Modify setup() to try GPS RTC UTC time first, falling back to
    Teensy RTC only when GPS is unavailable
    [PocketFT8XcvrFW.cpp]

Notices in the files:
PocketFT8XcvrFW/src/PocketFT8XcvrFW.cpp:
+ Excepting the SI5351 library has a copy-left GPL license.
